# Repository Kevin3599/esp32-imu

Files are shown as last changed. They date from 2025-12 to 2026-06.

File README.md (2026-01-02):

# ESP32 双I²C总线 IMU+OLED 项目

本项目演示如何在ESP32-WROOM-32上使用两个独立的I²C控制器，分别连接MPU6050 IMU传感器和SSD1306 OLED显示屏。

## 🔌 硬件连接

### ESP32引脚分配
```
MPU6050 (I²C总线0)：
├── VCC  → 3.3V
├── GND  → GND  
├── SDA  → GPIO21
└── SCL  → GPIO19

OLED显示屏 (I²C总线1)：
├── VCC  → 3.3V
├── GND  → GND
├── SDA  → GPIO25  
└── SCL  → GPIO26
```

### 接线图说明
```
ESP32-WROOM-32
     ┌─────────────┐
     │             │
     │  GPIO19 ────┼──── SCL (MPU6050)
     │  GPIO21 ────┼──── SDA (MPU6050)  
     │             │
     │  GPIO26 ────┼──── SCL (OLED)
     │  GPIO25 ────┼──── SDA (OLED)
     │             │
     │   3.3V ─────┼──── VCC (两个设备)
     │   GND ─────┼──── GND (两个设备)
     └─────────────┘
```

## 📋 物料清单

| 组件 | 型号/规格 | 数量 | 备注 |
|---|---|---|---|
| 微控制器 | ESP32-WROOM-32 | 1 | 主控制器 |
| IMU传感器 | MPU6050 | 1 | 6轴惯性传感器 |
| 显示屏 | SSD1306 OLED 128×64 | 1 | I²C接口 |
| 电阻 | 4.7KΩ | 4 | I²C上拉电阻（可选） |
| 跳线 | 杜邦线 | 若干 | 连接线 |

## 🛠️ 软件环境

### 开发环境
- **IDE**: Visual Studio Code + PlatformIO
- **框架**: Arduino Framework
- **平台**: Espressif 32

### 库依赖
```ini
lib_deps = 
    adafruit/Adafruit SSD1306@^2.5.7
    adafruit/Adafruit GFX Library@^1.11.8
    electroniccats/MPU6050@^1.0.2
    wire
```

## 📈 扩展建议

### 1. 姿态解算
```cpp
// 添加四元数或欧拉角计算
float pitch = atan2(-accelX, sqrt(accelY*accelY + accelZ*accelZ)) * 180/PI;
float roll = atan2(accelY, accelZ) * 180/PI;
```

### 2. 数据滤波
```cpp
// 添加低通滤波或卡尔曼滤波
class LowPassFilter {
private:
    float alpha;
    float filteredValue;
public:
    LowPassFilter(float cutoff) : alpha(cutoff), filteredValue(0) {}
    float update(float input) {
        filteredValue = alpha * input + (1 - alpha) * filteredValue;
        return filteredValue;
    }
};
```

## 📄 许可证

本项目采用 MIT 许可证 - 详见 [LICENSE](LICENSE) 文件

## 🤝 贡献

欢迎提交 Pull Request 和 Issue！

## 📧 联系方式

如有问题，请提交 GitHub Issue 或发送邮件。

---

**项目状态**: ✅ 稳定版本  
**最后更新**: 2024-12-23  
**兼容性**: ESP32-WROOM-32, Arduino Framework

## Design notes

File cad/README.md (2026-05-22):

# PCB1 Enclosure Model

This folder contains a parametric `OpenSCAD` enclosure for the PCB described by
`Gerber_PCB1_2026-02-03.zip`.

## Source dimensions

- Board outline: `78.867 mm x 70.866 mm`
- Corner radius: `5.08 mm`
- Source file: `Gerber_BoardOutlineLayer.GKO`

## Files

- `pcb1_enclosure.scad`: two-piece printable enclosure with a base, lid, board
  support ring, inferred component keepouts, simple edge retainers, and
  external screw-ear shell fastening.

## Design assumptions

- The PCB does not expose dedicated mounting holes, so the base uses perimeter
  support plus four retainers instead of screw posts.
- Top-side component clearance defaults to `18 mm`.
- Bottom-side component clearance defaults to `3 mm`.
- Edge cutouts default to a best-effort layout inferred from the Gerber probe
  data and should be tuned after checking the exact connector and cable
  locations on the assembled board.
- The lid now includes local relief pockets above the main component regions so
  you can keep the overall shell height reasonable while still clearing modules.
- The upper and lower shells are fastened with four external screw ears so the
  enclosure can still lock together even though the PCB itself has no mounting
  holes.

## Quick use

1. Open `pcb1_enclosure.scad` in OpenSCAD.
2. Change `show_mode` to `base`, `lid`, or `exploded` while tuning.
3. Toggle `show_components` if you want to inspect the inferred keepout boxes.
4. Adjust the clearance and cutout parameters near the top of the file.
5. Edit the cutout arrays as `[center, width, height]` in millimeters.
6. Export each half as STL once the fit looks right.

## Parameters you will likely tune first

- `fit_gap`
- `board_edge_gap`
- `underside_clearance`
- `topside_clearance`
- `north_cutouts`
- `south_cutouts`
- `east_cutouts`
- `west_cutouts`
- `component_clearance_gap`
- `use_fastening_ears`
- `screw_clearance_diameter`
- `screw_pilot_diameter`
- `screw_head_diameter`

## Notes

- The lid is modeled as an outer cap that overlaps the base walls. If your
  printer runs tight, increase `lid_clearance` by `0.1 mm` to `0.2 mm`.
- `show_components = true` displays approximate top-side module volumes inferred
  from silkscreen and flying-probe data. Treat them as starting geometry, not a
  final metrology source.
- `use_pressure_pads` is disabled by default to avoid colliding with tall
  modules until the exact assembled height is measured.
- The default fastening geometry is sized for roughly M3 hardware or similar
  self-tapping screws. Tweak the screw diameters if you plan to use inserts or
  machine screws instead.
- The support ring can be widened if the PCB has heavy modules near its center.

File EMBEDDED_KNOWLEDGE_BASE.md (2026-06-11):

# Embedded Knowledge Base

> 面向未来自己的工程复盘。本文以当前工作区源码为事实基线；旧 README、优化报告和面试笔记只作为设计背景，不覆盖代码事实。
>
> 最后核查：2026-06-10

## 目录

1. [第一部分：项目全景图](#第一部分项目全景图)
2. [第二部分：系统架构设计](#第二部分系统架构设计)
3. [第三部分：项目运行流程](#第三部分项目运行流程)
4. [第四部分：核心模块解析](#第四部分核心模块解析)
5. [第五部分：技术知识提取](#第五部分技术知识提取)
6. [第六部分：设计决策分析](#第六部分设计决策分析)
7. [第七部分：调试与踩坑记录](#第七部分调试与踩坑记录)
8. [第八部分：工程实践总结](#第八部分工程实践总结)
9. [第九部分：项目复盘](#第九部分项目复盘)
10. [第十部分：个人知识地图](#第十部分个人知识地图)

---

## 阅读前先知道的事实

这个仓库只有一个主固件项目，但它经历了明显演化：

1. 最初是 ESP32 + MPU6050 + OLED 的双 I2C 演示。
2. 后来加入 GT-U7 GPS，目标变成低成本 Dragy 风格车辆性能仪。
3. 再加入摩托车倾角/G 力分析、Wi-Fi 网页、音频录制、SD 卡日志、PCB 和 3D 打印外壳。

因此旧文档与当前代码有冲突。以后判断“现在是什么”，优先级应为：

```text
当前源码与 platformio.ini
        >
当前硬件接线和实测记录
        >
README / GPS 优化报告 / 面试笔记
```

当前已发现的版本漂移：

| 主题 | 当前源码 | 旧文档中的其他说法 |
|---|---|---|
| I2C | MPU: GPIO21/22；OLED: GPIO18/19，两条总线 | README 曾写 21/19 与 25/26；GPS_WIRING 曾写共享 21/22 |
| GPS 串口 | UART2，GPIO16/17，9600 bps | 优化报告写过 38400 bps |
| GPS 更新率 | 启动配置 10 Hz；掉线恢复时改为 5 Hz | 文档同时出现 5 Hz、10 Hz |
| SD 卡 | 模块完整，但 `setup()` 初始化被注释 | 部分描述把它写成可直接使用 |
| GPS-IMU 融合 | `loop()` 每 5 ms 调用 `fuseIMUSpeed()` | `/data` 的 `imuSpeed` 仍固定输出 0，注释称暂未实现 |
| 摩托互补滤波 | 已在 `performance_analyzer.cpp` 实现 | 面试笔记部分段落称姿态互补滤波未实现 |

编码方面，大量中文文件显示为 mojibake，说明文件很可能曾以 UTF-8 保存、后被错误编码链处理。代码符号仍可读，但这是长期维护风险。

---

# 第一部分：项目全景图

# ESP32 Draggy Racing Logger

## 项目背景

项目想用低成本器件做一个车载/摩托车数据终端：实时读取车辆运动状态，显示速度、姿态、G 力和性能测试结果，并让手机不安装 App 也能查看数据。

真正困难的不是“读出传感器”，而是车辆环境：

- 发动机和路面引入高频振动。
- MPU6050 有零偏、温漂和安装坐标误差。
- GT-U7 在静止和弱信号时会速度漂移。
- GPS 只有低频绝对速度，IMU 有高频响应但积分漂移。
- Web、OLED、采样、录音和存储都跑在同一个 Arduino 主循环中。

## 项目目标

当前代码试图实现：

- 200 Hz IMU 采样与滤波。
- 10 Hz GPS 解析、静止抑制和性能计时。
- GPS-IMU 速度与 G 力的轻量融合。
- 摩托车倾角、弯道、翘头/翘尾和峰值统计。
- OLED 本地显示。
- ESP32 SoftAP + HTTP Web 仪表盘。
- SPIFFS 低码率 WAV 录音。
- SD 卡 10 Hz CSV 行驶日志。
- 与 PCB 配套的参数化 OpenSCAD 外壳。

必须区分：SD 记录代码存在，但当前启动流程没有初始化 SD 卡，所以默认不会真正记录。

## 技术栈

| 类别 | 使用内容 |
|---|---|
| MCU | ESP32-WROOM-32 / PlatformIO `esp32dev` |
| 框架 | Arduino Framework |
| 语言 | C++、HTML/CSS/JavaScript、OpenSCAD |
| 传感器 | MPU6050、GT-U7 GPS、模拟麦克风 |
| 显示 | SSD1306 128x64 OLED |
| 总线 | 双 I2C、UART2、HSPI、ADC1 |
| 网络 | Wi-Fi SoftAP、HTTP `WebServer` |
| 存储 | SPIFFS、SD/FAT CSV |
| 数据格式 | NMEA、JSON、CSV、PCM WAV |
| 构建 | PlatformIO |
| 机械 | Gerber、OpenSCAD、STL |

## 项目一句话总结

基于 ESP32 构建低成本车载多传感器性能记录仪，融合 200 Hz IMU 与 10 Hz GPS，实现姿态/G 力分析、性能计时、Web 实时可视化、录音与可扩展数据记录。

## 项目目录结构分析

```text
esp32-imu/
├── src/                         固件主源码
│   ├── main.cpp                 系统装配、调度、OLED、HTTP API
│   ├── mpu6050.*                IMU 驱动、滤波、基础姿态
│   ├── gps_module.*             GPS、性能测试、速度融合、会话持久化
│   ├── performance_analyzer.*   G 力融合、车辆行为、摩托车分析
│   ├── audio_recorder.*         ADC 定时采样、WAV、自动录音
│   └── sd_logger.*              SD 初始化与 CSV 日志
├── data/index.html              SPIFFS Web 仪表盘
├── cad/                         PCB 外壳源码与 STL
├── platformio.ini               板卡、串口、依赖、SPIFFS 配置
├── README.md                    早期项目说明，已落后于源码
├── BUILD_GUIDE.md               PlatformIO 构建与排错说明
├── GPS_*.md                     GPS 接线、升级与优化思路
├── GT-U7_*.md                   GT-U7 优化总结，部分内容未与代码同步
├── INTERVIEW_NOTES.md           技术复盘素材，不是运行事实来源
├── Gerber_*.zip                 PCB 制造文件
├── wiring_diagram.txt           接线说明，接近当前双 I2C 方案
├── include/ lib/ test/          PlatformIO 模板目录，暂无自有实现/测试
└── interview/                   LaTeX/PDF 派生文档，不属于固件运行链
```

PCB 和外壳是同一产品化尝试的一部分，不应误识别为独立软件项目。Gerber 表明存在双层 PCB、丝印、阻焊、钻孔和飞针测试数据；无法仅从当前工作区确定实际焊接版本和最终 BOM。

---

# 第二部分：系统架构设计

# 系统架构

## 总体架构

```text
                   +---------------- ESP32 ----------------+
MPU6050 -- I2C0 -->| 采样/均值/IIR --> 姿态与G力 --------+ |
                   |                                      | |
GT-U7 ---- UART2 ->| NMEA解析/质量判断/速度滤波 --------+ | |
                   |                                    | | |
Mic ------ ADC1 -->| Timer ISR --> WAV缓冲 --> SPIFFS   | | |
                   |                                    v v |
SD Card --- HSPI <-| CSV Logger <--- 融合/性能/摩托分析器  |
                   |                    |                 |
OLED ----- I2C1 <--| 本地显示 <---------+                 |
                   |                    v                 |
Phone <-- Wi-Fi ---| WebServer --> JSON API --> index.html|
                   +--------------------------------------+
```

## 为什么这样拆分

- `main.cpp` 是 composition root：拥有硬件实例、启动顺序和时间调度。
- 驱动/算法按数据源拆分：IMU、GPS、音频、SD 各自维护状态。
- `performance_analyzer` 位于传感器之上，读取全局 IMU/GPS 数据形成派生指标。
- OLED 和 HTTP 是两个输出适配器，共享同一批全局状态。

这套拆法适合原型开发，新增功能快；代价是模块通过 `extern` 全局结构体耦合，调用顺序就是隐含的数据一致性协议。

## 数据链路

### 运动数据链

```text
MPU6050 raw acceleration/gyro
        |
        v
10点移动平均 + 一阶IIR
        |
        +--> Roll/Pitch
        +--> G力/驾驶状态
        +--> 摩托倾角互补滤波
        +--> IMU速度积分
                         \
GT-U7 NMEA --> GPS速度 ---> 轻量互补修正 --> 性能指标/Web/OLED/CSV
```

GPS 提供长期不漂移的绝对速度；IMU 提供短期快速变化。当前实现不是严格卡尔曼滤波，而是偏置校准、死区、积分和 GPS 比例拉回。

### 展示链

```text
全局状态结构体
   +--> OLED: 20 Hz，五种页面
   +--> /data: Web主仪表盘
   +--> /moto: 摩托数据
   +--> /audio: 录音状态
   +--> Serial: 5 Hz简报 / 2 s详细信息
```

### 存储链

```text
Mic ADC --> 8-bit/8 kHz PCM --> 512 B buffer --> SPIFFS WAV
GPS+IMU+Fusion --> RideDataPoint --> CSV line --> SD card
Browser samples --> JavaScript memory --> client-side CSV/JSON export
```

这里实际上有三套“记录”：SPIFFS 音频、SD 原始/融合数据、浏览器内存记录。它们没有统一会话 ID 和时间基准。

---

# 第三部分：项目运行流程

# 上电初始化

```text
Reset
  |
  v
Serial 115200 + BOOT输入
  |
  v
双I2C 400 kHz初始化 -> 扫描设备
  |
  v
MPU6050 -> GPS -> 性能分析 -> 摩托模式 -> 音频
  |
  v
SD初始化跳过（当前测试模式）
  |
  v
OLED -> SPIFFS -> Wi-Fi SoftAP -> HTTP路由
  |
  v
显示连接信息，进入 loop()
```

值得注意：`initAudioRecorder()` 在 `SPIFFS.begin(true)` 之前读取 SPIFFS 容量。首次启动或文件系统异常时，这个顺序不稳妥，应该先挂载文件系统。

# 主循环调度

项目没有 FreeRTOS 显式任务，也没有统一 scheduler，而是 `millis()` 驱动的协作式时间片：

```text
loop()
  |
  +--> server.handleClient()
  +--> BOOT按键与串口命令
  |
  +--> 每5 ms:
  |      ReadMPU6050()
  |      fuseIMUSpeed()
  |
  +--> 每100 ms:
  |      updateGPSData()
  |      checkAutoLogging()
  |      optional logDataPoint()
  |
  +--> 每次循环:
  |      updateAudioRecorder()
  |
  +--> 每50 ms:
         updateFusedData()
         update OLED
         print serial
```

优点是易读、没有任务同步成本。问题是任何阻塞操作都会破坏所有“频率承诺”。HTTP 文件传输、GPS 重连 `delay()`、OLED I2C、SD flush 和串口输出都可能让 5 ms/125 us 级任务失约。

# 中断流程

唯一明确的用户中断路径是音频定时器：

```text
125 us timer
   |
   v
ISR: adc1_get_raw()
   |
   +--> lastSample = sample
   +--> sampleReady = true
             |
             v
主循环 processSample()
   |
   +--> 12 bit转8 bit
   +--> 更新音量
   +--> 写入512 B缓冲
   +--> 缓冲满后写SPIFFS
```

这不是可靠的生产者-消费者队列。若主循环在两个中断之间没有消费，`lastSample` 被覆盖，只保留最新样本。

# 通信流程

## GPS

```text
UART2 bytes
  -> TinyGPS++ encode
  -> location/speed/time/satellite/HDOP
  -> 合理范围与跳变检查
  -> 速度20点窗口、方差、自适应滤波、死区
  -> GPS_DATA
```

超过 3 秒无可解析数据会标记丢失；每 10 秒发送热启动和恢复配置。恢复配置将更新周期设置为 5 Hz，与启动时 10 Hz 不一致。

## Web

ESP32 创建 `ESP32-IMU` 热点，密码硬编码为 `12345678`，地址通常为 `192.168.4.1`。

| 路由 | 作用 |
|---|---|
| `/` | 从 SPIFFS 流式返回 `index.html` |
| `/data` | 通用速度、GPS、G 力、性能 JSON |
| `/moto` | 摩托倾角、事件和峰值 JSON |
| `/audio` | 录音状态 JSON |
| `/audio/control?action=...` | 开始、停止、暂停、恢复、删除、自动模式、列表 |
| `/audio/download?file=...` | 下载 WAV |

网页每 150 ms 请求 `/data`，每 100 ms 请求 `/moto`。这是轮询架构，简单但请求频繁，且 `/moto` 请求本身会再次调用 `updateMotorcycleData()`，使算法更新时间受浏览器请求节奏影响。

# 状态机

## 音频录制

```text
IDLE/STOPPED -- speed >= 5 --> ACTIVE
ACTIVE -- speed < 2 for 5s --> STOPPED
ACTIVE -- pause ------------> PAUSED
PAUSED -- resume -----------> ACTIVE
ACTIVE -- 300s -------------> STOPPED
```

`RECORDING_WAITING` 被定义但当前逻辑基本未使用。

## 性能测试

- 加速：速度超过 5 km/h 自动开始，穿越 60/100/200 km/h 时记录时间。
- 制动：速度达到约 95 km/h 后进入条件，降到 5 km/h 结束。
- 圈速字段和函数声明存在，但完整实现无法从当前工作区确定。

---

# 第四部分：核心模块解析

# `main.cpp`：系统装配与输出层

职责：

- 创建两条 `TwoWire` 总线、OLED、WebServer。
- 固定初始化顺序和主循环频率。
- 把全局数据编码为 OLED 页面和 JSON。
- 管理 BOOT 按键及串口模式。

关键设计是多速率协作循环。最大问题是文件已超过千行，HTTP、OLED、调度和业务拼在一起，修改一个输出字段容易影响实时路径。

# `mpu6050`：高振动车辆 IMU 前端

核心结构 `MPU6050_DATA` 同时保存原始和滤波后的加速度、角速度、Roll/Pitch。

处理链：

```text
Adafruit getEvent()
 -> 10样本滑动平均
 -> alpha=0.1 一阶IIR
 -> 加速度倾角
```

量程为 ±8 g、±500 deg/s，DLPF 为 94 Hz。选择 94 Hz 是为了保留快速车辆动作，再依赖软件滤波压制振动。

注意：

- `CalculateAttitude()` 的基础 Roll/Pitch 仅使用加速度计。
- `Yaw` 固定为 0。
- 陀螺数据在 Adafruit API 中是 rad/s，但摩托互补滤波直接按 deg/s 积分的迹象很强；若未转换，倾角动态项会缩小约 57.3 倍。需要实机与库单位确认后修正。
- 初始滤波状态为 0，会有启动爬升过程。

# `gps_module`：GPS、速度与性能计时

核心结构：

- `GPS_DATA`：位置、时间、速度、信号质量、融合状态。
- `PERFORMANCE_DATA`：加速、制动、圈速和会话数据。

主要策略：

- 仅输出 RMC/GGA，降低 9600 bps 下 NMEA 堵塞风险。
- 开启 SBAS/WAAS。
- 对位置做经纬度范围和 1 km 单帧跳变检查。
- 对速度做 20 点窗口、标准差、卫星/HDOP 动态阈值、分段 IIR 和最终死区。
- 静止时收集 200 个样本估计 IMU 前向偏置。
- IMU 积分速度每次 GPS 新帧向 GPS 拉回 10%。

设计意图正确，但实现中 `gps_data.speed_ms` 很少被明确同步为当前 GPS 速度，而校准与静止归零依赖它；应统一只使用 `speed_mps` 或明确维护该字段。

# `performance_analyzer`：派生指标与摩托语义

`FUSED_PERFORMANCE_DATA` 保存当前速度/G 力、峰值、行为状态和质量分数。

主要功能：

- 组合 IMU 加速度与 GPS 速度差分。
- 检测加速、制动、转弯。
- 用车辆质量、滚阻、风阻估算瞬时功率。
- 用互补滤波估计摩托倾角和俯仰。
- 检测弯道、翘头、翘尾，估算弯道半径。

这里把“信号处理”和“车辆业务语义”放在同一模块，原型阶段方便，但未来应拆成：

```text
Sensor Fusion
Vehicle Frame Transform
Event Detector
Session Statistics
```

硬编码偏置 `-0.47/+0.5/-0.48` 和假定坐标 `X=垂直、Y=侧向、Z=前向` 是整个分析可信度的基础。换安装方向或换板后必须重新标定。

# `audio_recorder`：低码率事件录音

配置为单声道、8 kHz、8 bit PCM，每秒约 8 KB，5 分钟约 2.4 MB，不含文件系统开销。

WAV 头在开始时写占位值，停止时回写文件大小。这种方式简单，但异常断电会留下头部未完成的文件。

最大架构问题是 ISR 只有一个样本槽，不是 DMA/环形缓冲。录音数据完整性无法保证。

# `sd_logger`：行驶 CSV

SD 使用 HSPI：

```text
MISO GPIO25
MOSI GPIO13
SCK  GPIO14
CS   GPIO15
```

选择 GPIO25 替代 GPIO12，是为了规避 ESP32 启动绑带引脚风险。日志以 10 Hz 写 CSV，每 100 点 flush 一次，在数据安全和写入开销之间折中。

当前 `setup()` 没有调用 `initSDCard()`，因此 `checkAutoLogging()` 会因 `initialized=false` 直接返回。

# `data/index.html`：无 App Web 仪表盘

单文件前端包含：

- 实时速度/G 力曲线。
- 性能、GPS、摩托状态。
- 浏览器端会话记录与 CSV/JSON 导出。
- 录音控制逻辑。

优点是部署简单。缺点是 HTML 已很大、编码损坏明显、无构建/校验、API 字段靠手写约定。浏览器记录只存在内存，刷新即丢失。

# `cad/pcb1_enclosure.scad`：参数化产品外壳

外壳从 Gerber 轮廓推导出 78.867 x 70.866 mm、圆角 5.08 mm 的 PCB：

- 底壳用周边支撑环和卡扣固定无安装孔 PCB。
- 上盖使用局部器件避让腔。
- 四角外置螺钉耳避免占用板内空间。
- 提供通风槽、边缘开口、装配/爆炸/导出模式。

器件高度和接口位置是从丝印/飞针数据推断的，不是装配实测。打印前必须实测校核。

---

# 第五部分：技术知识提取

# 双 I2C

## 为什么需要它

MPU6050 与 OLED 本可共享地址不同的总线，但 OLED 整帧刷新会占用 I2C 时间。分成两条控制器可以隔离显示流量与传感器采样，也方便独立排错。

## 项目中的实际应用

- I2C0：GPIO21/22，MPU6050。
- I2C1：GPIO18/19，SSD1306。
- 两者均配置 400 kHz。

## 常见 Bug 与调试

- 文档接线漂移是当前首要风险。
- 地址应扫描确认：MPU 0x68/0x69，OLED 0x3C/0x3D。
- 线长、上拉、电源噪声会导致间歇 NACK。
- 用现有 `scanI2CDevices()` 先区分接线问题与驱动问题。

替代方案是共享一条 I2C，节省引脚；对本项目而言隔离总线更适合实时采样。

# UART 与 NMEA

GT-U7 通过 UART2 输入 NMEA。项目只保留 RMC 与 GGA，因为 10 Hz、9600 bps 时全量语句容易占满串口带宽。

常见坑：

- 模块不一定兼容所有 PMTK 命令。
- 发送 10 Hz 配置不代表模块确实进入 10 Hz。
- 掉线恢复又设置 5 Hz，导致运行状态不一致。
- 应统计每秒完整 RMC/GGA 帧数，而不是只相信配置命令。

# 采样与数字滤波

项目使用了三类低成本滤波：

- 硬件 DLPF：在传感器内部先限制带宽。
- 滑动平均：压制随机噪声，但引入窗口延迟。
- 一阶 IIR：O(1) 状态，适合 MCU，但有相位延迟。

常见误区是把“200 Hz 调用周期”当成严格采样率。当前系统是协作循环，实际采样间隔会抖动，且代码给融合器的 `dt` 固定为 5 ms，没有用真实时间差。

调试时应同时记录：

- 实际 `micros()` 间隔分布。
- 原始值、滑动平均值、IIR 值。
- 静止 RMS、阶跃响应和相位延迟。

# GPS 静止漂移

GPS 低速时噪声可能大于真实速度。项目不是简单小于阈值清零，而是综合窗口方差、连续稳定次数、卫星数和 HDOP。

这能改善显示，但阈值滤波也会吃掉真实低速起步，使 0-100 起点变晚。性能计时最好保留原始 Doppler 速度和滤波速度两路，分别服务计时与 UI。

# GPS-IMU 融合

当前思路：

```text
IMU: 高频预测，但漂移
GPS: 低频校正，但延迟和低速噪声
```

项目采用简化互补校正而非 EKF，优点是参数直观、计算低。缺点是没有显式状态协方差、时间戳对齐、姿态重力补偿和传感器延迟模型。

真正升级时，优先实现一维状态 `[速度, 加速度偏置]` 的 Kalman filter，而不是直接上完整 9/15 状态导航 EKF。

# ADC、Timer 与音频

定时器中断可以建立稳定采样节拍，但 ISR 应只搬运数据，不能依赖单槽共享变量承载连续流。

更合适的方案：

- ESP32 I2S ADC/DMA。
- ISR 写入 lock-free ring buffer。
- 双缓冲，由任务批量写文件。

此外 8-bit unsigned PCM 的直流中心假设是 128；模拟麦克风偏置和 ADC 非线性应实测。

# SPI、SD 与文件系统

SD 写入延迟具有长尾，`flush()` 可能阻塞几十毫秒。若和 200 Hz 采样同循环，必须缓冲解耦。

SPIFFS 适合少量静态资源和小文件，不适合高频持续音频写入。LittleFS 或 SD 更适合长期录音；异常断电还需要临时文件和恢复策略。

# Wi-Fi 与 HTTP

SoftAP 让手机直接连接，现场无需路由器，这是很实用的产品决策。

当前轮询方案的常见问题：

- 多客户端会放大 CPU 和 JSON 序列化开销。
- 同步 `WebServer` 的流式下载可能阻塞采样。
- `sprintf` 固定缓冲区依赖字段长度，需用 `snprintf`。
- 密码硬编码，适合原型但不适合发布。

替代方案：Server-Sent Events 或 WebSocket 推送，并将静态资源缓存与实时数据通道分离。

---

# 第六部分：设计决策分析

# 双 I2C 而不是共享总线

背景：显示更新与高频 IMU 读取争用总线。

优点：故障隔离、时序可控、扫描清晰。缺点：多占两根 GPIO，接线复杂。当前 ESP32 引脚尚可，选择合理。

# 协作式调度而不是 FreeRTOS 任务

背景：Arduino 原型需要快速迭代。

优点：控制流直观、调试容易。缺点：所有模块共享阻塞预算，无法保证 200 Hz IMU 和 8 kHz 音频。

当前方案适合功能验证；当音频、SD 和网络同时开启时，应迁移为任务和队列：

```text
Core/Task Sensor -> Queue -> Fusion
Core/Task IO     -> SD/SPIFFS/Web
```

# 多级滤波而不是单一滤波器

车辆振动覆盖宽频段，单一强低通会造成明显延迟。硬件 DLPF、移动平均和 IIR 分层容易调参，但当前级联实际带宽没有通过测试数据验证。

替代方案包括双二阶 Butterworth、陷波器、Savitzky-Golay 或频域分析后定制滤波。应先采集原始数据做 PSD，再决定，而不是继续堆滤波。

# 互补滤波而不是 EKF

当前传感器精度有限，且原型更需要可解释性。互补滤波成本低、故障容易定位。

缺点是重力投影、安装误差和时间同步需要手工处理。等硬件、坐标系和时间戳稳定后，再引入一维 KF 或姿态 EKF。

# 阈值状态机

自动录音、SD 日志、加速/制动、弯道检测都采用阈值 + 延时/滞回。

优点是行为可解释；缺点是阈值分散在多个文件，且录音与 SD 的起停参数不一致：

- 录音停止延时 5 秒。
- SD 停止延时 30 秒。

应集中成 `VehicleSessionConfig`，并用一次会话状态驱动所有记录器。

# 浏览器端导出

浏览器记录减轻 ESP32 存储压力，开发方便。但手机锁屏、刷新、断连都会丢数据，不能替代设备端可靠日志。它更适合作为“即时观察与临时导出”。

---

# 第七部分：调试与踩坑记录

# 调试记录 1：文档与固件接线冲突

问题：按旧 README 接线可能找不到设备。

原因：项目从共享 I2C 演进到双 I2C，文档未统一。

定位：以 `main.cpp` 宏和启动扫描输出为准。

解决：维护唯一 `HARDWARE_PINOUT.md`，其他文档只链接，不复制引脚表。

经验：硬件配置必须单一事实源。

# 调试记录 2：音频丢采样

问题：WAV 时长、音质或样本数异常。

原因：8 kHz ISR 覆盖单个 `lastSample`；主循环无法保证每 125 us 消费。

定位：比较墙钟时长与 `samples_recorded / 8000`，统计覆盖次数。

解决：I2S DMA 或环形缓冲，文件写入放到独立任务。

# 调试记录 3：SD 功能看似存在但不工作

问题：速度超过阈值仍不生成 CSV。

原因：`initSDCard()` 在 `setup()` 被注释，`sd_status.initialized` 始终为 false。

定位：查看启动日志是否打印 SD 容量。

解决：恢复初始化前先解决原注释所说的 I2C/引脚冲突，并增加 Web/串口 SD 状态。

# 调试记录 4：倾角动态响应可能错误

问题：陀螺贡献过弱，倾角主要跟随加速度计。

原因：Adafruit 陀螺输出通常为 rad/s，而摩托代码按 deg/s 注释直接积分。

定位：固定角速度转动，比较原始 gyro、积分角与实际角度。

解决：在驱动边界统一单位，字段命名加入 `_rad_s` 或 `_deg_s`。

# 调试记录 5：GPS 模式不一致

问题：掉线恢复后刷新率下降，性能测试响应变化。

原因：启动发送 100 ms 更新命令，恢复发送 200 ms 更新命令。

解决：抽取 `configureGPS()`，启动和恢复调用同一配置；读取实际帧率确认结果。

# 调试记录 6：启动顺序与 SPIFFS

问题：音频模块初始化时容量可能为 0 或状态不可靠。

原因：音频初始化早于 `SPIFFS.begin(true)`。

解决：先初始化存储，再初始化依赖存储的音频和 Web。

# 调试记录 7：融合字段与 API 不一致

问题：内部已经运行速度融合，但网页 `imuSpeed` 永远为 0，`speed` 仍来自 GPS。

原因：算法、状态结构和 JSON 输出没有同时更新。

解决：定义明确字段：`gps_speed`、`imu_predicted_speed`、`fused_speed`，并建立 API schema 测试。

# 调试记录 8：HTTP 文件下载路径

问题：下载接口可能访问任意 SPIFFS 已知路径，而不仅是录音。

原因：只补 `/` 和检查文件存在，没有限定 `/ride_*.wav`。

解决：白名单文件名格式，拒绝 `..`、非 WAV 和非录音前缀。

# 调试记录 9：字符串与缓冲区

问题：JSON/文本字段增长后可能溢出固定缓冲区。

原因：使用 `sprintf` 而非长度受限接口。

解决：改为 `snprintf` 并检查返回值；长期使用 ArduinoJson 流式序列化。

# 调试记录 10：编码损坏

问题：中文日志、网页标签和文档显示乱码，甚至可能破坏 HTML 标签或 C++ 字符串。

原因：文件编码链不一致。

解决：全仓统一 UTF-8，无 BOM；添加 `.editorconfig`，在 CI 中做 UTF-8 解码和 HTML/C++ 基础检查。

---

# 第八部分：工程实践总结

## 做得好的地方

- 模块按传感器和业务域拆分，原型意图清楚。
- 使用 `millis()` 而不是在主路径大量固定延时。
- 对 GPS 弱信号、静止漂移和跳点有工程化防护。
- 同时保留原始值、滤波值和峰值，便于调试。
- 通过 SoftAP + 单页 Web 降低现场使用门槛。
- SD 选择 HSPI 和非 GPIO12 MISO，体现了对 ESP32 启动绑带的考虑。
- OpenSCAD 参数化外壳把软件项目向可装配设备推进了一步。

## 可以改进的地方

### 代码组织

`main.cpp` 应拆成：

```text
app_scheduler
web_api
oled_view
hardware_config
```

全局 `extern` 状态应逐步替换为只读快照或消息结构，至少明确谁写、谁读、更新频率和单位。

### 配置管理

引脚、采样率、阈值、车辆参数和 Wi-Fi 凭据分散在各文件。建议集中：

```text
board_config.h
sensor_config.h
vehicle_config.h
```

并把所有物理量写入单位后缀。

### 日志

串口日志丰富，但缺乏级别和节流统一。应使用 `LOGE/W/I/D`，避免高频 `Serial.printf` 破坏实时性。

### 错误处理

很多初始化失败后继续运行，这是原型的容错思路，但后续函数仍可能假定硬件有效。应维护模块健康状态，并在 UI 显示 degraded mode。

### 测试策略

当前 `test/` 只有模板说明，没有项目测试。最值得先补的是纯算法主机测试：

- Haversine 距离。
- GPS 窗口与静止判定。
- 阈值穿越计时。
- WAV 头尺寸。
- CSV 格式。
- 互补滤波单位与步进响应。
- 状态机起停滞回。

硬件在环测试应回放已保存的 NMEA 与 IMU 数据，而不是每次都上车测试。

### 构建与 CI

当前配置锁定库版本是好事。建议 CI 至少执行：

```text
pio run
pio test -e native
HTML/JSON schema sanity check
UTF-8 validation
```

本次分析环境无法执行构建，因为终端没有可用的 `pio` 命令；因此当前源码是否能完整编译无法从本次静态分析确定。

---

# 第九部分：项目复盘

## 最大的亮点

不是简单堆传感器，而是围绕“低成本硬件在真实车辆环境中不可靠”做了多层处理：信号质量、静止抑制、漂移校准、融合、状态机和多终端显示。

## 最大的难点

多时间尺度和多误差源同时存在：

- 音频 8 kHz。
- IMU 200 Hz。
- 显示/融合 20 Hz。
- GPS/日志 10 Hz。
- Web 约 6.7/10 Hz。

而它们目前共享一个可能阻塞的主循环。真正的系统瓶颈是调度与数据一致性，不再只是算法。

## 学到的知识

- 传感器数据“能读”与“能用于决策”之间隔着校准、坐标系、滤波、质量评估和时间同步。
- 低成本 GPS 的极限不能只靠软件宣传突破，升级硬件有时比继续堆阈值更合理。
- 原型文档很容易落后于代码，尤其是引脚和单位。
- 记录系统必须考虑掉电、断连和阻塞长尾。
- 机械结构、接线和软件配置应被视为同一系统架构。

## 如果重新设计

1. 先定义统一硬件配置、坐标系和单位。
2. 使用 I2S DMA 采音，传感器和存储通过队列解耦。
3. 建立单一 `VehicleSession` 状态机，统一音频、CSV 和峰值会话。
4. 所有数据携带 `micros()` 时间戳，融合使用真实 `dt`。
5. 保留 raw/filtered/fused 三层数据并定义稳定 API schema。
6. 先做数据回放工具和 native 单元测试，再调算法。
7. 用实测频谱和标定数据选择滤波器。
8. 把网页通信改成 SSE/WebSocket。

## 下一步扩展

优先级建议：

1. 修复编码、引脚文档和单位问题。
2. 恢复可验证的 SD 日志，获得真实数据集。
3. 修复音频采样架构。
4. 增加时间戳和离线回放测试。
5. 一维速度/偏置 Kalman filter。
6. 升级 NEO-M9N 或更高频 GNSS；是否上 RTK 取决于实际计时精度目标。
7. 增加 OTA、配置页面和会话下载。

无法从当前工作区确定：现有 PCB 是否已经覆盖麦克风与 SD 模块、外壳是否完成实物试装、车辆参数是否经过标定、GPS 优化报告中的量化提升是否来自可复现实测。

---

# 第十部分：个人知识地图

# Embedded Knowledge Map

```text
嵌入式系统
├── ESP32
│   ├── Arduino Framework
│   ├── GPIO与启动绑带
│   ├── 双I2C控制器
│   ├── UART2
│   ├── HSPI
│   ├── ADC1与硬件Timer
│   ├── SPIFFS
│   └── Wi-Fi SoftAP / HTTP
│
├── 传感器与信号处理
│   ├── MPU6050量程与DLPF
│   ├── 滑动平均
│   ├── 一阶IIR
│   ├── 互补滤波
│   ├── 零偏与安装校准
│   ├── 坐标系映射
│   ├── 重力补偿
│   └── 采样率、抖动与真实dt
│
├── GNSS
│   ├── NMEA RMC/GGA
│   ├── Doppler速度
│   ├── 卫星数与HDOP
│   ├── 静止漂移抑制
│   ├── 跳点过滤
│   ├── SBAS
│   ├── 多频率数据融合
│   └── GT-U7到高性能GNSS升级
│
├── 车辆与机器人数据
│   ├── 纵向/横向/垂直G
│   ├── 加速与制动计时
│   ├── 倾角与俯仰
│   ├── 弯道检测与半径估计
│   ├── 翘头/翘尾事件
│   ├── 峰值与会话统计
│   └── 简化功率估算
│
├── 数据记录
│   ├── WAV/PCM
│   ├── CSV
│   ├── JSON API
│   ├── 环形缓冲与DMA
│   ├── SD写入长尾
│   ├── 掉电一致性
│   └── 浏览器端临时记录
│
├── 软件架构
│   ├── 协作式调度
│   ├── 多速率任务
│   ├── 状态机与滞回
│   ├── 全局状态耦合
│   ├── 消息队列/生产者消费者
│   ├── 模块健康状态
│   └── API schema
│
├── 工程化
│   ├── PlatformIO依赖锁定
│   ├── Native算法测试
│   ├── 硬件在环与数据回放
│   ├── 日志分级
│   ├── UTF-8与文档单一事实源
│   └── CI构建与静态检查
│
└── 产品化
    ├── Gerber与PCB制造资料
    ├── 飞针测试数据
    ├── OpenSCAD参数化外壳
    ├── 装配公差与器件避让
    ├── Web免安装交互
    └── 硬件成本与精度边界
```

## 长期维护入口

半年后重新开始时，建议按这个顺序：

1. 先读本文的“阅读前事实”和“调试记录”。
2. 核对实际硬件接线与 `main.cpp` 引脚。
3. 执行 PlatformIO 构建并保存构建环境版本。
4. 串口确认 I2C 扫描、GPS 帧率、SPIFFS 和 SD 状态。
5. 先记录一份 raw 数据，再修改滤波或融合参数。
6. 所有新的实测结论更新到本文，同时删除或标记过时文档中的冲突说法。

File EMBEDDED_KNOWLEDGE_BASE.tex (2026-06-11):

% Options for packages loaded elsewhere
\PassOptionsToPackage{unicode}{hyperref}
\PassOptionsToPackage{hyphens}{url}
\PassOptionsToPackage{dvipsnames,svgnames,x11names}{xcolor}
\documentclass[
  UTF8,11pt,a4paper]{ctexart}
\usepackage{xcolor}
\usepackage[margin=2.2cm]{geometry}
\usepackage{amsmath,amssymb}
\setcounter{secnumdepth}{5}
\usepackage{iftex}
\ifPDFTeX
  \usepackage[T1]{fontenc}
  \usepackage[utf8]{inputenc}
  \usepackage{textcomp} % provide euro and other symbols
\else % if luatex or xetex
  \usepackage{unicode-math} % this also loads fontspec
  \defaultfontfeatures{Scale=MatchLowercase}
  \defaultfontfeatures[\rmfamily]{Ligatures=TeX,Scale=1}
\fi
\usepackage{lmodern}
\ifPDFTeX\else
  % xetex/luatex font selection
\fi
% Use upquote if available, for straight quotes in verbatim environments
\IfFileExists{upquote.sty}{\usepackage{upquote}}{}
\IfFileExists{microtype.sty}{% use microtype if available
  \usepackage[]{microtype}
  \UseMicrotypeSet[protrusion]{basicmath} % disable protrusion for tt fonts
}{}
\makeatletter
\@ifundefined{KOMAClassName}{% if non-KOMA class
  \IfFileExists{parskip.sty}{%
    \usepackage{parskip}
  }{% else
    \setlength{\parindent}{0pt}
    \setlength{\parskip}{6pt plus 2pt minus 1pt}}
}{% if KOMA class
  \KOMAoptions{parskip=half}}
\makeatother
\usepackage{listings}
\setmonofont{Microsoft YaHei UI}
\setCJKmonofont{Microsoft YaHei UI}
\lstset{
  basicstyle=\small\ttfamily,
  columns=fullflexible,
  keepspaces=true,
  breaklines=true,
  breakatwhitespace=false,
  showstringspaces=false
}
\newcommand{\passthrough}[1]{#1}
\lstset{defaultdialect=[5.3]Lua}
\lstset{defaultdialect=[x86masm]Assembler}
\usepackage{longtable,booktabs,array}
\newcounter{none} % for unnumbered tables
\usepackage{calc} % for calculating minipage widths
% Correct order of tables after \paragraph or \subparagraph
\usepackage{etoolbox}
\makeatletter
\patchcmd\longtable{\par}{\if@noskipsec\mbox{}\fi\par}{}{}
\makeatother
% Allow footnotes in longtable head/foot
\IfFileExists{footnotehyper.sty}{\usepackage{footnotehyper}}{\usepackage{footnote}}
\makesavenoteenv{longtable}
\setlength{\emergencystretch}{3em} % prevent overfull lines
\providecommand{\tightlist}{%
  \setlength{\itemsep}{0pt}\setlength{\parskip}{0pt}}
\usepackage{bookmark}
\IfFileExists{xurl.sty}{\usepackage{xurl}}{} % add URL line breaks if available
\urlstyle{same}
\hypersetup{
  colorlinks=true,
  linkcolor={teal},
  filecolor={Maroon},
  citecolor={Blue},
  urlcolor={blue},
  pdfcreator={LaTeX via pandoc}}

\title{Embedded Knowledge Base}
\usepackage{etoolbox}
\makeatletter
\providecommand{\subtitle}[1]{% add subtitle to \maketitle
  \apptocmd{\@title}{\par {\large #1 \par}}{}{}
}
\makeatother
\subtitle{ESP32 Draggy Racing Logger 工程知识库}
\author{Workspace Engineering Notes}
\date{2026-06-10}

\begin{document}
\maketitle

{
\setcounter{tocdepth}{3}
\tableofcontents
}
\section{Embedded Knowledge Base}\label{embedded-knowledge-base}

\begin{quote}
面向未来自己的工程复盘。本文以当前工作区源码为事实基线；旧
README、优化报告和面试笔记只作为设计背景，不覆盖代码事实。

最后核查：2026-06-10
\end{quote}

\subsection{目录}\label{ux76eeux5f55}

\begin{enumerate}
\def\labelenumi{\arabic{enumi}.}
\tightlist
\item
  \hyperref[ux7b2cux4e00ux90e8ux5206ux9879ux76eeux5168ux666fux56fe]{第一部分：项目全景图}
\item
  \hyperref[ux7b2cux4e8cux90e8ux5206ux7cfbux7edfux67b6ux6784ux8bbeux8ba1]{第二部分：系统架构设计}
\item
  \hyperref[ux7b2cux4e09ux90e8ux5206ux9879ux76eeux8fd0ux884cux6d41ux7a0b]{第三部分：项目运行流程}
\item
  \hyperref[ux7b2cux56dbux90e8ux5206ux6838ux5fc3ux6a21ux5757ux89e3ux6790]{第四部分：核心模块解析}
\item
  \hyperref[ux7b2cux4e94ux90e8ux5206ux6280ux672fux77e5ux8bc6ux63d0ux53d6]{第五部分：技术知识提取}
\item
  \hyperref[ux7b2cux516dux90e8ux5206ux8bbeux8ba1ux51b3ux7b56ux5206ux6790]{第六部分：设计决策分析}
\item
  \hyperref[ux7b2cux4e03ux90e8ux5206ux8c03ux8bd5ux4e0eux8e29ux5751ux8bb0ux5f55]{第七部分：调试与踩坑记录}
\item
  \hyperref[ux7b2cux516bux90e8ux5206ux5de5ux7a0bux5b9eux8df5ux603bux7ed3]{第八部分：工程实践总结}
\item
  \hyperref[ux7b2cux4e5dux90e8ux5206ux9879ux76eeux590dux76d8]{第九部分：项目复盘}
\item
  \hyperref[ux7b2cux5341ux90e8ux5206ux4e2aux4ebaux77e5ux8bc6ux5730ux56fe]{第十部分：个人知识地图}
\end{enumerate}

\begin{center}\rule{0.5\linewidth}{0.5pt}\end{center}

\subsection{阅读前先知道的事实}\label{ux9605ux8bfbux524dux5148ux77e5ux9053ux7684ux4e8bux5b9e}

这个仓库只有一个主固件项目，但它经历了明显演化：

\begin{enumerate}
\def\labelenumi{\arabic{enumi}.}
\tightlist
\item
  最初是 ESP32 + MPU6050 + OLED 的双 I2C 演示。
\item
  后来加入 GT-U7 GPS，目标变成低成本 Dragy 风格车辆性能仪。
\item
  再加入摩托车倾角/G 力分析、Wi-Fi 网页、音频录制、SD 卡日志、PCB 和 3D
  打印外壳。
\end{enumerate}

因此旧文档与当前代码有冲突。以后判断``现在是什么''，优先级应为：

\begin{lstlisting}
当前源码与 platformio.ini
        >
当前硬件接线和实测记录
        >
README / GPS 优化报告 / 面试笔记
\end{lstlisting}

当前已发现的版本漂移：

{\def\LTcaptype{none} % do not increment counter
\begin{longtable}[]{@{}lll@{}}
\toprule\noalign{}
主题 & 当前源码 & 旧文档中的其他说法 \\
\midrule\noalign{}
\endhead
\bottomrule\noalign{}
\endlastfoot
I2C & MPU: GPIO21/22；OLED: GPIO18/19，两条总线 & README 曾写 21/19 与
25/26；GPS\_WIRING 曾写共享 21/22 \\
GPS 串口 & UART2，GPIO16/17，9600 bps & 优化报告写过 38400 bps \\
GPS 更新率 & 启动配置 10 Hz；掉线恢复时改为 5 Hz & 文档同时出现 5 Hz、10
Hz \\
SD 卡 & 模块完整，但 \passthrough{\lstinline!setup()!} 初始化被注释 &
部分描述把它写成可直接使用 \\
GPS-IMU 融合 & \passthrough{\lstinline!loop()!} 每 5 ms 调用
\passthrough{\lstinline!fuseIMUSpeed()!} &
\passthrough{\lstinline!/data!} 的 \passthrough{\lstinline!imuSpeed!}
仍固定输出 0，注释称暂未实现 \\
摩托互补滤波 & 已在 \passthrough{\lstinline!performance\_analyzer.cpp!}
实现 & 面试笔记部分段落称姿态互补滤波未实现 \\
\end{longtable}
}

编码方面，大量中文文件显示为 mojibake，说明文件很可能曾以 UTF-8
保存、后被错误编码链处理。代码符号仍可读，但这是长期维护风险。

\begin{center}\rule{0.5\linewidth}{0.5pt}\end{center}

\section{第一部分：项目全景图}\label{ux7b2cux4e00ux90e8ux5206ux9879ux76eeux5168ux666fux56fe}

\section{ESP32 Draggy Racing Logger}\label{esp32-draggy-racing-logger}

\subsection{项目背景}\label{ux9879ux76eeux80ccux666f}

项目想用低成本器件做一个车载/摩托车数据终端：实时读取车辆运动状态，显示速度、姿态、G
力和性能测试结果，并让手机不安装 App 也能查看数据。

真正困难的不是``读出传感器''，而是车辆环境：

\begin{itemize}
\tightlist
\item
  发动机和路面引入高频振动。
\item
  MPU6050 有零偏、温漂和安装坐标误差。
\item
  GT-U7 在静止和弱信号时会速度漂移。
\item
  GPS 只有低频绝对速度，IMU 有高频响应但积分漂移。
\item
  Web、OLED、采样、录音和存储都跑在同一个 Arduino 主循环中。
\end{itemize}

\subsection{项目目标}\label{ux9879ux76eeux76eeux6807}

当前代码试图实现：

\begin{itemize}
\tightlist
\item
  200 Hz IMU 采样与滤波。
\item
  10 Hz GPS 解析、静止抑制和性能计时。
\item
  GPS-IMU 速度与 G 力的轻量融合。
\item
  摩托车倾角、弯道、翘头/翘尾和峰值统计。
\item
  OLED 本地显示。
\item
  ESP32 SoftAP + HTTP Web 仪表盘。
\item
  SPIFFS 低码率 WAV 录音。
\item
  SD 卡 10 Hz CSV 行驶日志。
\item
  与 PCB 配套的参数化 OpenSCAD 外壳。
\end{itemize}

必须区分：SD 记录代码存在，但当前启动流程没有初始化 SD
卡，所以默认不会真正记录。

\subsection{技术栈}\label{ux6280ux672fux6808}

{\def\LTcaptype{none} % do not increment counter
\begin{longtable}[]{@{}ll@{}}
\toprule\noalign{}
类别 & 使用内容 \\
\midrule\noalign{}
\endhead
\bottomrule\noalign{}
\endlastfoot
MCU & ESP32-WROOM-32 / PlatformIO \passthrough{\lstinline!esp32dev!} \\
框架 & Arduino Framework \\
语言 & C++、HTML/CSS/JavaScript、OpenSCAD \\
传感器 & MPU6050、GT-U7 GPS、模拟麦克风 \\
显示 & SSD1306 128x64 OLED \\
总线 & 双 I2C、UART2、HSPI、ADC1 \\
网络 & Wi-Fi SoftAP、HTTP \passthrough{\lstinline!WebServer!} \\
存储 & SPIFFS、SD/FAT CSV \\
数据格式 & NMEA、JSON、CSV、PCM WAV \\
构建 & PlatformIO \\
机械 & Gerber、OpenSCAD、STL \\
\end{longtable}
}

\subsection{项目一句话总结}\label{ux9879ux76eeux4e00ux53e5ux8bddux603bux7ed3}

基于 ESP32 构建低成本车载多传感器性能记录仪，融合 200 Hz IMU 与 10 Hz
GPS，实现姿态/G 力分析、性能计时、Web 实时可视化、录音与可扩展数据记录。

\subsection{项目目录结构分析}\label{ux9879ux76eeux76eeux5f55ux7ed3ux6784ux5206ux6790}

\begin{lstlisting}
esp32-imu/
├── src/                         固件主源码
│   ├── main.cpp                 系统装配、调度、OLED、HTTP API
│   ├── mpu6050.*                IMU 驱动、滤波、基础姿态
│   ├── gps_module.*             GPS、性能测试、速度融合、会话持久化
│   ├── performance_analyzer.*   G 力融合、车辆行为、摩托车分析
│   ├── audio_recorder.*         ADC 定时采样、WAV、自动录音
│   └── sd_logger.*              SD 初始化与 CSV 日志
├── data/index.html              SPIFFS Web 仪表盘
├── cad/                         PCB 外壳源码与 STL
├── platformio.ini               板卡、串口、依赖、SPIFFS 配置
├── README.md                    早期项目说明，已落后于源码
├── BUILD_GUIDE.md               PlatformIO 构建与排错说明
├── GPS_*.md                     GPS 接线、升级与优化思路
├── GT-U7_*.md                   GT-U7 优化总结，部分内容未与代码同步
├── INTERVIEW_NOTES.md           技术复盘素材，不是运行事实来源
├── Gerber_*.zip                 PCB 制造文件
├── wiring_diagram.txt           接线说明，接近当前双 I2C 方案
├── include/ lib/ test/          PlatformIO 模板目录，暂无自有实现/测试
└── interview/                   LaTeX/PDF 派生文档，不属于固件运行链
\end{lstlisting}

PCB 和外壳是同一产品化尝试的一部分，不应误识别为独立软件项目。Gerber
表明存在双层
PCB、丝印、阻焊、钻孔和飞针测试数据；无法仅从当前工作区确定实际焊接版本和最终
BOM。

\begin{center}\rule{0.5\linewidth}{0.5pt}\end{center}

\section{第二部分：系统架构设计}\label{ux7b2cux4e8cux90e8ux5206ux7cfbux7edfux67b6ux6784ux8bbeux8ba1}

\section{系统架构}\label{ux7cfbux7edfux67b6ux6784}

\subsection{总体架构}\label{ux603bux4f53ux67b6ux6784}

\begin{lstlisting}
                   +---------------- ESP32 ----------------+
MPU6050 -- I2C0 -->| 采样/均值/IIR --> 姿态与G力 --------+ |
                   |                                      | |
GT-U7 ---- UART2 ->| NMEA解析/质量判断/速度滤波 --------+ | |
                   |                                    | | |
Mic ------ ADC1 -->| Timer ISR --> WAV缓冲 --> SPIFFS   | | |
                   |                                    v v |
SD Card --- HSPI <-| CSV Logger <--- 融合/性能/摩托分析器  |
                   |                    |                 |
OLED ----- I2C1 <--| 本地显示 <---------+                 |
                   |                    v                 |
Phone <-- Wi-Fi ---| WebServer --> JSON API --> index.html|
                   +--------------------------------------+
\end{lstlisting}

\subsection{为什么这样拆分}\label{ux4e3aux4ec0ux4e48ux8fd9ux6837ux62c6ux5206}

\begin{itemize}
\tightlist
\item
  \passthrough{\lstinline!main.cpp!} 是 composition
  root：拥有硬件实例、启动顺序和时间调度。
\item
  驱动/算法按数据源拆分：IMU、GPS、音频、SD 各自维护状态。
\item
  \passthrough{\lstinline!performance\_analyzer!}
  位于传感器之上，读取全局 IMU/GPS 数据形成派生指标。
\item
  OLED 和 HTTP 是两个输出适配器，共享同一批全局状态。
\end{itemize}

这套拆法适合原型开发，新增功能快；代价是模块通过
\passthrough{\lstinline!extern!}
全局结构体耦合，调用顺序就是隐含的数据一致性协议。

\subsection{数据链路}\label{ux6570ux636eux94feux8def}

\subsubsection{运动数据链}\label{ux8fd0ux52a8ux6570ux636eux94fe}

\begin{lstlisting}
MPU6050 raw acceleration/gyro
        |
        v
10点移动平均 + 一阶IIR
        |
        +--> Roll/Pitch
        +--> G力/驾驶状态
        +--> 摩托倾角互补滤波
        +--> IMU速度积分
                         \
GT-U7 NMEA --> GPS速度 ---> 轻量互补修正 --> 性能指标/Web/OLED/CSV
\end{lstlisting}

GPS 提供长期不漂移的绝对速度；IMU
提供短期快速变化。当前实现不是严格卡尔曼滤波，而是偏置校准、死区、积分和
GPS 比例拉回。

\subsubsection{展示链}\label{ux5c55ux793aux94fe}

\begin{lstlisting}
全局状态结构体
   +--> OLED: 20 Hz，五种页面
   +--> /data: Web主仪表盘
   +--> /moto: 摩托数据
   +--> /audio: 录音状态
   +--> Serial: 5 Hz简报 / 2 s详细信息
\end{lstlisting}

\subsubsection{存储链}\label{ux5b58ux50a8ux94fe}

\begin{lstlisting}
Mic ADC --> 8-bit/8 kHz PCM --> 512 B buffer --> SPIFFS WAV
GPS+IMU+Fusion --> RideDataPoint --> CSV line --> SD card
Browser samples --> JavaScript memory --> client-side CSV/JSON export
\end{lstlisting}

这里实际上有三套``记录''：SPIFFS 音频、SD
原始/融合数据、浏览器内存记录。它们没有统一会话 ID 和时间基准。

\begin{center}\rule{0.5\linewidth}{0.5pt}\end{center}

\section{第三部分：项目运行流程}\label{ux7b2cux4e09ux90e8ux5206ux9879ux76eeux8fd0ux884cux6d41ux7a0b}

\section{上电初始化}\label{ux4e0aux7535ux521dux59cbux5316}

\begin{lstlisting}
Reset
  |
  v
Serial 115200 + BOOT输入
  |
  v
双I2C 400 kHz初始化 -> 扫描设备
  |
  v
MPU6050 -> GPS -> 性能分析 -> 摩托模式 -> 音频
  |
  v
SD初始化跳过（当前测试模式）
  |
  v
OLED -> SPIFFS -> Wi-Fi SoftAP -> HTTP路由
  |
  v
显示连接信息，进入 loop()
\end{lstlisting}

值得注意：\passthrough{\lstinline!initAudioRecorder()!} 在
\passthrough{\lstinline!SPIFFS.begin(true)!} 之前读取 SPIFFS
容量。首次启动或文件系统异常时，这个顺序不稳妥，应该先挂载文件系统。

\section{主循环调度}\label{ux4e3bux5faaux73afux8c03ux5ea6}

项目没有 FreeRTOS 显式任务，也没有统一 scheduler，而是
\passthrough{\lstinline!millis()!} 驱动的协作式时间片：

\begin{lstlisting}
loop()
  |
  +--> server.handleClient()
  +--> BOOT按键与串口命令
  |
  +--> 每5 ms:
  |      ReadMPU6050()
  |      fuseIMUSpeed()
  |
  +--> 每100 ms:
  |      updateGPSData()
  |      checkAutoLogging()
  |      optional logDataPoint()
  |
  +--> 每次循环:
  |      updateAudioRecorder()
  |
  +--> 每50 ms:
         updateFusedData()
         update OLED
         print serial
\end{lstlisting}

优点是易读、没有任务同步成本。问题是任何阻塞操作都会破坏所有``频率承诺''。HTTP
文件传输、GPS 重连 \passthrough{\lstinline!delay()!}、OLED I2C、SD flush
和串口输出都可能让 5 ms/125 us 级任务失约。

\section{中断流程}\label{ux4e2dux65adux6d41ux7a0b}

唯一明确的用户中断路径是音频定时器：

\begin{lstlisting}
125 us timer
   |
   v
ISR: adc1_get_raw()
   |
   +--> lastSample = sample
   +--> sampleReady = true
             |
             v
主循环 processSample()
   |
   +--> 12 bit转8 bit
   +--> 更新音量
   +--> 写入512 B缓冲
   +--> 缓冲满后写SPIFFS
\end{lstlisting}

这不是可靠的生产者-消费者队列。若主循环在两个中断之间没有消费，\passthrough{\lstinline!lastSample!}
被覆盖，只保留最新样本。

\section{通信流程}\label{ux901aux4fe1ux6d41ux7a0b}

\subsection{GPS}\label{gps}

\begin{lstlisting}
UART2 bytes
  -> TinyGPS++ encode
  -> location/speed/time/satellite/HDOP
  -> 合理范围与跳变检查
  -> 速度20点窗口、方差、自适应滤波、死区
  -> GPS_DATA
\end{lstlisting}

超过 3 秒无可解析数据会标记丢失；每 10
秒发送热启动和恢复配置。恢复配置将更新周期设置为 5 Hz，与启动时 10 Hz
不一致。

\subsection{Web}\label{web}

ESP32 创建 \passthrough{\lstinline!ESP32-IMU!} 热点，密码硬编码为
\passthrough{\lstinline!12345678!}，地址通常为
\passthrough{\lstinline!192.168.4.1!}。

{\def\LTcaptype{none} % do not increment counter
\begin{longtable}[]{@{}ll@{}}
\toprule\noalign{}
路由 & 作用 \\
\midrule\noalign{}
\endhead
\bottomrule\noalign{}
\endlastfoot
\passthrough{\lstinline!/!} & 从 SPIFFS 流式返回
\passthrough{\lstinline!index.html!} \\
\passthrough{\lstinline!/data!} & 通用速度、GPS、G 力、性能 JSON \\
\passthrough{\lstinline!/moto!} & 摩托倾角、事件和峰值 JSON \\
\passthrough{\lstinline!/audio!} & 录音状态 JSON \\
\passthrough{\lstinline!/audio/control?action=...!} &
开始、停止、暂停、恢复、删除、自动模式、列表 \\
\passthrough{\lstinline!/audio/download?file=...!} & 下载 WAV \\
\end{longtable}
}

网页每 150 ms 请求 \passthrough{\lstinline!/data!}，每 100 ms 请求
\passthrough{\lstinline!/moto!}。这是轮询架构，简单但请求频繁，且
\passthrough{\lstinline!/moto!} 请求本身会再次调用
\passthrough{\lstinline!updateMotorcycleData()!}，使算法更新时间受浏览器请求节奏影响。

\section{状态机}\label{ux72b6ux6001ux673a}

\subsection{音频录制}\label{ux97f3ux9891ux5f55ux5236}

\begin{lstlisting}
IDLE/STOPPED -- speed >= 5 --> ACTIVE
ACTIVE -- speed < 2 for 5s --> STOPPED
ACTIVE -- pause ------------> PAUSED
PAUSED -- resume -----------> ACTIVE
ACTIVE -- 300s -------------> STOPPED
\end{lstlisting}

\passthrough{\lstinline!RECORDING\_WAITING!}
被定义但当前逻辑基本未使用。

\subsection{性能测试}\label{ux6027ux80fdux6d4bux8bd5}

\begin{itemize}
\tightlist
\item
  加速：速度超过 5 km/h 自动开始，穿越 60/100/200 km/h 时记录时间。
\item
  制动：速度达到约 95 km/h 后进入条件，降到 5 km/h 结束。
\item
  圈速字段和函数声明存在，但完整实现无法从当前工作区确定。
\end{itemize}

\begin{center}\rule{0.5\linewidth}{0.5pt}\end{center}

\section{第四部分：核心模块解析}\label{ux7b2cux56dbux90e8ux5206ux6838ux5fc3ux6a21ux5757ux89e3ux6790}

\section{\texorpdfstring{\texttt{main.cpp}：系统装配与输出层}{main.cpp：系统装配与输出层}}\label{maincppux7cfbux7edfux88c5ux914dux4e0eux8f93ux51faux5c42}

职责：

\begin{itemize}
\tightlist
\item
  创建两条 \passthrough{\lstinline!TwoWire!} 总线、OLED、WebServer。
\item
  固定初始化顺序和主循环频率。
\item
  把全局数据编码为 OLED 页面和 JSON。
\item
  管理 BOOT 按键及串口模式。
\end{itemize}

关键设计是多速率协作循环。最大问题是文件已超过千行，HTTP、OLED、调度和业务拼在一起，修改一个输出字段容易影响实时路径。

\section{\texorpdfstring{\texttt{mpu6050}：高振动车辆 IMU
前端}{mpu6050：高振动车辆 IMU 前端}}\label{mpu6050ux9ad8ux632fux52a8ux8f66ux8f86-imu-ux524dux7aef}

核心结构 \passthrough{\lstinline!MPU6050\_DATA!}
同时保存原始和滤波后的加速度、角速度、Roll/Pitch。

处理链：

\begin{lstlisting}
Adafruit getEvent()
 -> 10样本滑动平均
 -> alpha=0.1 一阶IIR
 -> 加速度倾角
\end{lstlisting}

量程为 ±8 g、±500 deg/s，DLPF 为 94 Hz。选择 94 Hz
是为了保留快速车辆动作，再依赖软件滤波压制振动。

注意：

\begin{itemize}
\tightlist
\item
  \passthrough{\lstinline!CalculateAttitude()!} 的基础 Roll/Pitch
  仅使用加速度计。
\item
  \passthrough{\lstinline!Yaw!} 固定为 0。
\item
  陀螺数据在 Adafruit API 中是 rad/s，但摩托互补滤波直接按 deg/s
  积分的迹象很强；若未转换，倾角动态项会缩小约 57.3
  倍。需要实机与库单位确认后修正。
\item
  初始滤波状态为 0，会有启动爬升过程。
\end{itemize}

\section{\texorpdfstring{\texttt{gps\_module}：GPS、速度与性能计时}{gps\_module：GPS、速度与性能计时}}\label{gps_modulegpsux901fux5ea6ux4e0eux6027ux80fdux8ba1ux65f6}

核心结构：

\begin{itemize}
\tightlist
\item
  \passthrough{\lstinline!GPS\_DATA!}：位置、时间、速度、信号质量、融合状态。
\item
  \passthrough{\lstinline!PERFORMANCE\_DATA!}：加速、制动、圈速和会话数据。
\end{itemize}

主要策略：

\begin{itemize}
\tightlist
\item
  仅输出 RMC/GGA，降低 9600 bps 下 NMEA 堵塞风险。
\item
  开启 SBAS/WAAS。
\item
  对位置做经纬度范围和 1 km 单帧跳变检查。
\item
  对速度做 20 点窗口、标准差、卫星/HDOP 动态阈值、分段 IIR 和最终死区。
\item
  静止时收集 200 个样本估计 IMU 前向偏置。
\item
  IMU 积分速度每次 GPS 新帧向 GPS 拉回 10\%。
\end{itemize}

设计意图正确，但实现中 \passthrough{\lstinline!gps\_data.speed\_ms!}
很少被明确同步为当前 GPS 速度，而校准与静止归零依赖它；应统一只使用
\passthrough{\lstinline!speed\_mps!} 或明确维护该字段。

\section{\texorpdfstring{\texttt{performance\_analyzer}：派生指标与摩托语义}{performance\_analyzer：派生指标与摩托语义}}\label{performance_analyzerux6d3eux751fux6307ux6807ux4e0eux6469ux6258ux8bedux4e49}

\passthrough{\lstinline!FUSED\_PERFORMANCE\_DATA!} 保存当前速度/G
力、峰值、行为状态和质量分数。

主要功能：

\begin{itemize}
\tightlist
\item
  组合 IMU 加速度与 GPS 速度差分。
\item
  检测加速、制动、转弯。
\item
  用车辆质量、滚阻、风阻估算瞬时功率。
\item
  用互补滤波估计摩托倾角和俯仰。
\item
  检测弯道、翘头、翘尾，估算弯道半径。
\end{itemize}

这里把``信号处理''和``车辆业务语义''放在同一模块，原型阶段方便，但未来应拆成：

\begin{lstlisting}
Sensor Fusion
Vehicle Frame Transform
Event Detector
Session Statistics
\end{lstlisting}

硬编码偏置 \passthrough{\lstinline!-0.47/+0.5/-0.48!} 和假定坐标
\passthrough{\lstinline!X=垂直、Y=侧向、Z=前向!}
是整个分析可信度的基础。换安装方向或换板后必须重新标定。

\section{\texorpdfstring{\texttt{audio\_recorder}：低码率事件录音}{audio\_recorder：低码率事件录音}}\label{audio_recorderux4f4eux7801ux7387ux4e8bux4ef6ux5f55ux97f3}

配置为单声道、8 kHz、8 bit PCM，每秒约 8 KB，5 分钟约 2.4
MB，不含文件系统开销。

WAV
头在开始时写占位值，停止时回写文件大小。这种方式简单，但异常断电会留下头部未完成的文件。

最大架构问题是 ISR 只有一个样本槽，不是
DMA/环形缓冲。录音数据完整性无法保证。

\section{\texorpdfstring{\texttt{sd\_logger}：行驶
CSV}{sd\_logger：行驶 CSV}}\label{sd_loggerux884cux9a76-csv}

SD 使用 HSPI：

\begin{lstlisting}
MISO GPIO25
MOSI GPIO13
SCK  GPIO14
CS   GPIO15
\end{lstlisting}

选择 GPIO25 替代 GPIO12，是为了规避 ESP32 启动绑带引脚风险。日志以 10 Hz
写 CSV，每 100 点 flush 一次，在数据安全和写入开销之间折中。

当前 \passthrough{\lstinline!setup()!} 没有调用
\passthrough{\lstinline!initSDCard()!}，因此
\passthrough{\lstinline!checkAutoLogging()!} 会因
\passthrough{\lstinline!initialized=false!} 直接返回。

\section{\texorpdfstring{\texttt{data/index.html}：无 App Web
仪表盘}{data/index.html：无 App Web 仪表盘}}\label{dataindexhtmlux65e0-app-web-ux4eeaux8868ux76d8}

单文件前端包含：

\begin{itemize}
\tightlist
\item
  实时速度/G 力曲线。
\item
  性能、GPS、摩托状态。
\item
  浏览器端会话记录与 CSV/JSON 导出。
\item
  录音控制逻辑。
\end{itemize}

优点是部署简单。缺点是 HTML 已很大、编码损坏明显、无构建/校验、API
字段靠手写约定。浏览器记录只存在内存，刷新即丢失。

\section{\texorpdfstring{\texttt{cad/pcb1\_enclosure.scad}：参数化产品外壳}{cad/pcb1\_enclosure.scad：参数化产品外壳}}\label{cadpcb1_enclosurescadux53c2ux6570ux5316ux4ea7ux54c1ux5916ux58f3}

外壳从 Gerber 轮廓推导出 78.867 x 70.866 mm、圆角 5.08 mm 的 PCB：

\begin{itemize}
\tightlist
\item
  底壳用周边支撑环和卡扣固定无安装孔 PCB。
\item
  上盖使用局部器件避让腔。
\item
  四角外置螺钉耳避免占用板内空间。
\item
  提供通风槽、边缘开口、装配/爆炸/导出模式。
\end{itemize}

器件高度和接口位置是从丝印/飞针数据推断的，不是装配实测。打印前必须实测校核。

\begin{center}\rule{0.5\linewidth}{0.5pt}\end{center}

\section{第五部分：技术知识提取}\label{ux7b2cux4e94ux90e8ux5206ux6280ux672fux77e5ux8bc6ux63d0ux53d6}

\section{双 I2C}\label{ux53cc-i2c}

\subsection{为什么需要它}\label{ux4e3aux4ec0ux4e48ux9700ux8981ux5b83}

MPU6050 与 OLED 本可共享地址不同的总线，但 OLED 整帧刷新会占用 I2C
时间。分成两条控制器可以隔离显示流量与传感器采样，也方便独立排错。

\subsection{项目中的实际应用}\label{ux9879ux76eeux4e2dux7684ux5b9eux9645ux5e94ux7528}

\begin{itemize}
\tightlist
\item
  I2C0：GPIO21/22，MPU6050。
\item
  I2C1：GPIO18/19，SSD1306。
\item
  两者均配置 400 kHz。
\end{itemize}

\subsection{常见 Bug 与调试}\label{ux5e38ux89c1-bug-ux4e0eux8c03ux8bd5}

\begin{itemize}
\tightlist
\item
  文档接线漂移是当前首要风险。
\item
  地址应扫描确认：MPU 0x68/0x69，OLED 0x3C/0x3D。
\item
  线长、上拉、电源噪声会导致间歇 NACK。
\item
  用现有 \passthrough{\lstinline!scanI2CDevices()!}
  先区分接线问题与驱动问题。
\end{itemize}

替代方案是共享一条 I2C，节省引脚；对本项目而言隔离总线更适合实时采样。

\section{UART 与 NMEA}\label{uart-ux4e0e-nmea}

GT-U7 通过 UART2 输入 NMEA。项目只保留 RMC 与 GGA，因为 10 Hz、9600 bps
时全量语句容易占满串口带宽。

常见坑：

\begin{itemize}
\tightlist
\item
  模块不一定兼容所有 PMTK 命令。
\item
  发送 10 Hz 配置不代表模块确实进入 10 Hz。
\item
  掉线恢复又设置 5 Hz，导致运行状态不一致。
\item
  应统计每秒完整 RMC/GGA 帧数，而不是只相信配置命令。
\end{itemize}

\section{采样与数字滤波}\label{ux91c7ux6837ux4e0eux6570ux5b57ux6ee4ux6ce2}

项目使用了三类低成本滤波：

\begin{itemize}
\tightlist
\item
  硬件 DLPF：在传感器内部先限制带宽。
\item
  滑动平均：压制随机噪声，但引入窗口延迟。
\item
  一阶 IIR：O(1) 状态，适合 MCU，但有相位延迟。
\end{itemize}

常见误区是把``200 Hz
调用周期''当成严格采样率。当前系统是协作循环，实际采样间隔会抖动，且代码给融合器的
\passthrough{\lstinline!dt!} 固定为 5 ms，没有用真实时间差。

调试时应同时记录：

\begin{itemize}
\tightlist
\item
  实际 \passthrough{\lstinline!micros()!} 间隔分布。
\item
  原始值、滑动平均值、IIR 值。
\item
  静止 RMS、阶跃响应和相位延迟。
\end{itemize}

\section{GPS 静止漂移}\label{gps-ux9759ux6b62ux6f02ux79fb}

GPS
低速时噪声可能大于真实速度。项目不是简单小于阈值清零，而是综合窗口方差、连续稳定次数、卫星数和
HDOP。

这能改善显示，但阈值滤波也会吃掉真实低速起步，使 0-100
起点变晚。性能计时最好保留原始 Doppler
速度和滤波速度两路，分别服务计时与 UI。

\section{GPS-IMU 融合}\label{gps-imu-ux878dux5408}

当前思路：

\begin{lstlisting}
IMU: 高频预测，但漂移
GPS: 低频校正，但延迟和低速噪声
\end{lstlisting}

项目采用简化互补校正而非
EKF，优点是参数直观、计算低。缺点是没有显式状态协方差、时间戳对齐、姿态重力补偿和传感器延迟模型。

真正升级时，优先实现一维状态
\passthrough{\lstinline![速度, 加速度偏置]!} 的 Kalman
filter，而不是直接上完整 9/15 状态导航 EKF。

\section{ADC、Timer 与音频}\label{adctimer-ux4e0eux97f3ux9891}

定时器中断可以建立稳定采样节拍，但 ISR
应只搬运数据，不能依赖单槽共享变量承载连续流。

更合适的方案：

\begin{itemize}
\tightlist
\item
  ESP32 I2S ADC/DMA。
\item
  ISR 写入 lock-free ring buffer。
\item
  双缓冲，由任务批量写文件。
\end{itemize}

此外 8-bit unsigned PCM 的直流中心假设是 128；模拟麦克风偏置和 ADC
非线性应实测。

\section{SPI、SD 与文件系统}\label{spisd-ux4e0eux6587ux4ef6ux7cfbux7edf}

SD 写入延迟具有长尾，\passthrough{\lstinline!flush()!}
可能阻塞几十毫秒。若和 200 Hz 采样同循环，必须缓冲解耦。

SPIFFS 适合少量静态资源和小文件，不适合高频持续音频写入。LittleFS 或 SD
更适合长期录音；异常断电还需要临时文件和恢复策略。

\section{Wi-Fi 与 HTTP}\label{wi-fi-ux4e0e-http}

SoftAP 让手机直接连接，现场无需路由器，这是很实用的产品决策。

当前轮询方案的常见问题：

\begin{itemize}
\tightlist
\item
  多客户端会放大 CPU 和 JSON 序列化开销。
\item
  同步 \passthrough{\lstinline!WebServer!} 的流式下载可能阻塞采样。
\item
  \passthrough{\lstinline!sprintf!} 固定缓冲区依赖字段长度，需用
  \passthrough{\lstinline!snprintf!}。
\item
  密码硬编码，适合原型但不适合发布。
\end{itemize}

替代方案：Server-Sent Events 或 WebSocket
推送，并将静态资源缓存与实时数据通道分离。

\begin{center}\rule{0.5\linewidth}{0.5pt}\end{center}

\section{第六部分：设计决策分析}\label{ux7b2cux516dux90e8ux5206ux8bbeux8ba1ux51b3ux7b56ux5206ux6790}

\section{双 I2C
而不是共享总线}\label{ux53cc-i2c-ux800cux4e0dux662fux5171ux4eabux603bux7ebf}

背景：显示更新与高频 IMU 读取争用总线。

优点：故障隔离、时序可控、扫描清晰。缺点：多占两根 GPIO，接线复杂。当前
ESP32 引脚尚可，选择合理。

\section{协作式调度而不是 FreeRTOS
任务}\label{ux534fux4f5cux5f0fux8c03ux5ea6ux800cux4e0dux662f-freertos-ux4efbux52a1}

背景：Arduino 原型需要快速迭代。

优点：控制流直观、调试容易。缺点：所有模块共享阻塞预算，无法保证 200 Hz
IMU 和 8 kHz 音频。

当前方案适合功能验证；当音频、SD 和网络同时开启时，应迁移为任务和队列：

\begin{lstlisting}
Core/Task Sensor -> Queue -> Fusion
Core/Task IO     -> SD/SPIFFS/Web
\end{lstlisting}

\section{多级滤波而不是单一滤波器}\label{ux591aux7ea7ux6ee4ux6ce2ux800cux4e0dux662fux5355ux4e00ux6ee4ux6ce2ux5668}

车辆振动覆盖宽频段，单一强低通会造成明显延迟。硬件 DLPF、移动平均和 IIR
分层容易调参，但当前级联实际带宽没有通过测试数据验证。

替代方案包括双二阶 Butterworth、陷波器、Savitzky-Golay
或频域分析后定制滤波。应先采集原始数据做 PSD，再决定，而不是继续堆滤波。

\section{互补滤波而不是
EKF}\label{ux4e92ux8865ux6ee4ux6ce2ux800cux4e0dux662f-ekf}

当前传感器精度有限，且原型更需要可解释性。互补滤波成本低、故障容易定位。

缺点是重力投影、安装误差和时间同步需要手工处理。等硬件、坐标系和时间戳稳定后，再引入一维
KF 或姿态 EKF。

\section{阈值状态机}\label{ux9608ux503cux72b6ux6001ux673a}

自动录音、SD 日志、加速/制动、弯道检测都采用阈值 + 延时/滞回。

优点是行为可解释；缺点是阈值分散在多个文件，且录音与 SD
的起停参数不一致：

\begin{itemize}
\tightlist
\item
  录音停止延时 5 秒。
\item
  SD 停止延时 30 秒。
\end{itemize}

应集中成
\passthrough{\lstinline!VehicleSessionConfig!}，并用一次会话状态驱动所有记录器。

\section{浏览器端导出}\label{ux6d4fux89c8ux5668ux7aefux5bfcux51fa}

浏览器记录减轻 ESP32
存储压力，开发方便。但手机锁屏、刷新、断连都会丢数据，不能替代设备端可靠日志。它更适合作为``即时观察与临时导出''。

\begin{center}\rule{0.5\linewidth}{0.5pt}\end{center}

\section{第七部分：调试与踩坑记录}\label{ux7b2cux4e03ux90e8ux5206ux8c03ux8bd5ux4e0eux8e29ux5751ux8bb0ux5f55}

\section{调试记录
1：文档与固件接线冲突}\label{ux8c03ux8bd5ux8bb0ux5f55-1ux6587ux6863ux4e0eux56faux4ef6ux63a5ux7ebfux51b2ux7a81}

问题：按旧 README 接线可能找不到设备。

原因：项目从共享 I2C 演进到双 I2C，文档未统一。

定位：以 \passthrough{\lstinline!main.cpp!} 宏和启动扫描输出为准。

解决：维护唯一
\passthrough{\lstinline!HARDWARE\_PINOUT.md!}，其他文档只链接，不复制引脚表。

经验：硬件配置必须单一事实源。

\section{调试记录
2：音频丢采样}\label{ux8c03ux8bd5ux8bb0ux5f55-2ux97f3ux9891ux4e22ux91c7ux6837}

问题：WAV 时长、音质或样本数异常。

原因：8 kHz ISR 覆盖单个
\passthrough{\lstinline!lastSample!}；主循环无法保证每 125 us 消费。

定位：比较墙钟时长与
\passthrough{\lstinline!samples\_recorded / 8000!}，统计覆盖次数。

解决：I2S DMA 或环形缓冲，文件写入放到独立任务。

\section{调试记录 3：SD
功能看似存在但不工作}\label{ux8c03ux8bd5ux8bb0ux5f55-3sd-ux529fux80fdux770bux4f3cux5b58ux5728ux4f46ux4e0dux5de5ux4f5c}

问题：速度超过阈值仍不生成 CSV。

原因：\passthrough{\lstinline!initSDCard()!} 在
\passthrough{\lstinline!setup()!}
被注释，\passthrough{\lstinline!sd\_status.initialized!} 始终为 false。

定位：查看启动日志是否打印 SD 容量。

解决：恢复初始化前先解决原注释所说的 I2C/引脚冲突，并增加 Web/串口 SD
状态。

\section{调试记录
4：倾角动态响应可能错误}\label{ux8c03ux8bd5ux8bb0ux5f55-4ux503eux89d2ux52a8ux6001ux54cdux5e94ux53efux80fdux9519ux8bef}

问题：陀螺贡献过弱，倾角主要跟随加速度计。

原因：Adafruit 陀螺输出通常为 rad/s，而摩托代码按 deg/s 注释直接积分。

定位：固定角速度转动，比较原始 gyro、积分角与实际角度。

解决：在驱动边界统一单位，字段命名加入
\passthrough{\lstinline!\_rad\_s!} 或
\passthrough{\lstinline!\_deg\_s!}。

\section{调试记录 5：GPS
模式不一致}\label{ux8c03ux8bd5ux8bb0ux5f55-5gps-ux6a21ux5f0fux4e0dux4e00ux81f4}

问题：掉线恢复后刷新率下降，性能测试响应变化。

原因：启动发送 100 ms 更新命令，恢复发送 200 ms 更新命令。

解决：抽取
\passthrough{\lstinline!configureGPS()!}，启动和恢复调用同一配置；读取实际帧率确认结果。

\section{调试记录 6：启动顺序与
SPIFFS}\label{ux8c03ux8bd5ux8bb0ux5f55-6ux542fux52a8ux987aux5e8fux4e0e-spiffs}

问题：音频模块初始化时容量可能为 0 或状态不可靠。

原因：音频初始化早于 \passthrough{\lstinline!SPIFFS.begin(true)!}。

解决：先初始化存储，再初始化依赖存储的音频和 Web。

\section{调试记录 7：融合字段与 API
不一致}\label{ux8c03ux8bd5ux8bb0ux5f55-7ux878dux5408ux5b57ux6bb5ux4e0e-api-ux4e0dux4e00ux81f4}

问题：内部已经运行速度融合，但网页 \passthrough{\lstinline!imuSpeed!}
永远为 0，\passthrough{\lstinline!speed!} 仍来自 GPS。

原因：算法、状态结构和 JSON 输出没有同时更新。

解决：定义明确字段：\passthrough{\lstinline!gps\_speed!}、\passthrough{\lstinline!imu\_predicted\_speed!}、\passthrough{\lstinline!fused\_speed!}，并建立
API schema 测试。

\section{调试记录 8：HTTP
文件下载路径}\label{ux8c03ux8bd5ux8bb0ux5f55-8http-ux6587ux4ef6ux4e0bux8f7dux8defux5f84}

问题：下载接口可能访问任意 SPIFFS 已知路径，而不仅是录音。

原因：只补 \passthrough{\lstinline!/!} 和检查文件存在，没有限定
\passthrough{\lstinline!/ride\_*.wav!}。

解决：白名单文件名格式，拒绝 \passthrough{\lstinline!..!}、非 WAV
和非录音前缀。

\section{调试记录
9：字符串与缓冲区}\label{ux8c03ux8bd5ux8bb0ux5f55-9ux5b57ux7b26ux4e32ux4e0eux7f13ux51b2ux533a}

问题：JSON/文本字段增长后可能溢出固定缓冲区。

原因：使用 \passthrough{\lstinline!sprintf!} 而非长度受限接口。

解决：改为 \passthrough{\lstinline!snprintf!} 并检查返回值；长期使用
ArduinoJson 流式序列化。

\section{调试记录
10：编码损坏}\label{ux8c03ux8bd5ux8bb0ux5f55-10ux7f16ux7801ux635fux574f}

问题：中文日志、网页标签和文档显示乱码，甚至可能破坏 HTML 标签或 C++
字符串。

原因：文件编码链不一致。

解决：全仓统一 UTF-8，无 BOM；添加
\passthrough{\lstinline!.editorconfig!}，在 CI 中做 UTF-8 解码和
HTML/C++ 基础检查。

\begin{center}\rule{0.5\linewidth}{0.5pt}\end{center}

\section{第八部分：工程实践总结}\label{ux7b2cux516bux90e8ux5206ux5de5ux7a0bux5b9eux8df5ux603bux7ed3}

\subsection{做得好的地方}\label{ux505aux5f97ux597dux7684ux5730ux65b9}

\begin{itemize}
\tightlist
\item
  模块按传感器和业务域拆分，原型意图清楚。
\item
  使用 \passthrough{\lstinline!millis()!} 而不是在主路径大量固定延时。
\item
  对 GPS 弱信号、静止漂移和跳点有工程化防护。
\item
  同时保留原始值、滤波值和峰值，便于调试。
\item
  通过 SoftAP + 单页 Web 降低现场使用门槛。
\item
  SD 选择 HSPI 和非 GPIO12 MISO，体现了对 ESP32 启动绑带的考虑。
\item
  OpenSCAD 参数化外壳把软件项目向可装配设备推进了一步。
\end{itemize}

\subsection{可以改进的地方}\label{ux53efux4ee5ux6539ux8fdbux7684ux5730ux65b9}

\subsubsection{代码组织}\label{ux4ee3ux7801ux7ec4ux7ec7}

\passthrough{\lstinline!main.cpp!} 应拆成：

\begin{lstlisting}
app_scheduler
web_api
oled_view
hardware_config
\end{lstlisting}

全局 \passthrough{\lstinline!extern!}
状态应逐步替换为只读快照或消息结构，至少明确谁写、谁读、更新频率和单位。

\subsubsection{配置管理}\label{ux914dux7f6eux7ba1ux7406}

引脚、采样率、阈值、车辆参数和 Wi-Fi 凭据分散在各文件。建议集中：

\begin{lstlisting}
board_config.h
sensor_config.h
vehicle_config.h
\end{lstlisting}

并把所有物理量写入单位后缀。

\subsubsection{日志}\label{ux65e5ux5fd7}

串口日志丰富，但缺乏级别和节流统一。应使用
\passthrough{\lstinline!LOGE/W/I/D!}，避免高频
\passthrough{\lstinline!Serial.printf!} 破坏实时性。

\subsubsection{错误处理}\label{ux9519ux8befux5904ux7406}

很多初始化失败后继续运行，这是原型的容错思路，但后续函数仍可能假定硬件有效。应维护模块健康状态，并在
UI 显示 degraded mode。

\subsubsection{测试策略}\label{ux6d4bux8bd5ux7b56ux7565}

当前 \passthrough{\lstinline!test/!}
只有模板说明，没有项目测试。最值得先补的是纯算法主机测试：

\begin{itemize}
\tightlist
\item
  Haversine 距离。
\item
  GPS 窗口与静止判定。
\item
  阈值穿越计时。
\item
  WAV 头尺寸。
\item
  CSV 格式。
\item
  互补滤波单位与步进响应。
\item
  状态机起停滞回。
\end{itemize}

硬件在环测试应回放已保存的 NMEA 与 IMU 数据，而不是每次都上车测试。

\subsubsection{构建与 CI}\label{ux6784ux5efaux4e0e-ci}

当前配置锁定库版本是好事。建议 CI 至少执行：

\begin{lstlisting}
pio run
pio test -e native
HTML/JSON schema sanity check
UTF-8 validation
\end{lstlisting}

本次分析环境无法执行构建，因为终端没有可用的
\passthrough{\lstinline!pio!}
命令；因此当前源码是否能完整编译无法从本次静态分析确定。

\begin{center}\rule{0.5\linewidth}{0.5pt}\end{center}

\section{第九部分：项目复盘}\label{ux7b2cux4e5dux90e8ux5206ux9879ux76eeux590dux76d8}

\subsection{最大的亮点}\label{ux6700ux5927ux7684ux4eaeux70b9}

不是简单堆传感器，而是围绕``低成本硬件在真实车辆环境中不可靠''做了多层处理：信号质量、静止抑制、漂移校准、融合、状态机和多终端显示。

\subsection{最大的难点}\label{ux6700ux5927ux7684ux96beux70b9}

多时间尺度和多误差源同时存在：

\begin{itemize}
\tightlist
\item
  音频 8 kHz。
\item
  IMU 200 Hz。
\item
  显示/融合 20 Hz。
\item
  GPS/日志 10 Hz。
\item
  Web 约 6.7/10 Hz。
\end{itemize}

而它们目前共享一个可能阻塞的主循环。真正的系统瓶颈是调度与数据一致性，不再只是算法。

\subsection{学到的知识}\label{ux5b66ux5230ux7684ux77e5ux8bc6}

\begin{itemize}
\tightlist
\item
  传感器数据``能读''与``能用于决策''之间隔着校准、坐标系、滤波、质量评估和时间同步。
\item
  低成本 GPS
  的极限不能只靠软件宣传突破，升级硬件有时比继续堆阈值更合理。
\item
  原型文档很容易落后于代码，尤其是引脚和单位。
\item
  记录系统必须考虑掉电、断连和阻塞长尾。
\item
  机械结构、接线和软件配置应被视为同一系统架构。
\end{itemize}

\subsection{如果重新设计}\label{ux5982ux679cux91cdux65b0ux8bbeux8ba1}

\begin{enumerate}
\def\labelenumi{\arabic{enumi}.}
\tightlist
\item
  先定义统一硬件配置、坐标系和单位。
\item
  使用 I2S DMA 采音，传感器和存储通过队列解耦。
\item
  建立单一 \passthrough{\lstinline!VehicleSession!}
  状态机，统一音频、CSV 和峰值会话。
\item
  所有数据携带 \passthrough{\lstinline!micros()!} 时间戳，融合使用真实
  \passthrough{\lstinline!dt!}。
\item
  保留 raw/filtered/fused 三层数据并定义稳定 API schema。
\item
  先做数据回放工具和 native 单元测试，再调算法。
\item
  用实测频谱和标定数据选择滤波器。
\item
  把网页通信改成 SSE/WebSocket。
\end{enumerate}

\subsection{下一步扩展}\label{ux4e0bux4e00ux6b65ux6269ux5c55}

优先级建议：

\begin{enumerate}
\def\labelenumi{\arabic{enumi}.}
\tightlist
\item
  修复编码、引脚文档和单位问题。
\item
  恢复可验证的 SD 日志，获得真实数据集。
\item
  修复音频采样架构。
\item
  增加时间戳和离线回放测试。
\item
  一维速度/偏置 Kalman filter。
\item
  升级 NEO-M9N 或更高频 GNSS；是否上 RTK 取决于实际计时精度目标。
\item
  增加 OTA、配置页面和会话下载。
\end{enumerate}

无法从当前工作区确定：现有 PCB 是否已经覆盖麦克风与 SD
模块、外壳是否完成实物试装、车辆参数是否经过标定、GPS
优化报告中的量化提升是否来自可复现实测。

\begin{center}\rule{0.5\linewidth}{0.5pt}\end{center}

\section{第十部分：个人知识地图}\label{ux7b2cux5341ux90e8ux5206ux4e2aux4ebaux77e5ux8bc6ux5730ux56fe}

\section{Embedded Knowledge Map}\label{embedded-knowledge-map}

\begin{lstlisting}
嵌入式系统
├── ESP32
│   ├── Arduino Framework
│   ├── GPIO与启动绑带
│   ├── 双I2C控制器
│   ├── UART2
│   ├── HSPI
│   ├── ADC1与硬件Timer
│   ├── SPIFFS
│   └── Wi-Fi SoftAP / HTTP
│
├── 传感器与信号处理
│   ├── MPU6050量程与DLPF
│   ├── 滑动平均
│   ├── 一阶IIR
│   ├── 互补滤波
│   ├── 零偏与安装校准
│   ├── 坐标系映射
│   ├── 重力补偿
│   └── 采样率、抖动与真实dt
│
├── GNSS
│   ├── NMEA RMC/GGA
│   ├── Doppler速度
│   ├── 卫星数与HDOP
│   ├── 静止漂移抑制
│   ├── 跳点过滤
│   ├── SBAS
│   ├── 多频率数据融合
│   └── GT-U7到高性能GNSS升级
│
├── 车辆与机器人数据
│   ├── 纵向/横向/垂直G
│   ├── 加速与制动计时
│   ├── 倾角与俯仰
│   ├── 弯道检测与半径估计
│   ├── 翘头/翘尾事件
│   ├── 峰值与会话统计
│   └── 简化功率估算
│
├── 数据记录
│   ├── WAV/PCM
│   ├── CSV
│   ├── JSON API
│   ├── 环形缓冲与DMA
│   ├── SD写入长尾
│   ├── 掉电一致性
│   └── 浏览器端临时记录
│
├── 软件架构
│   ├── 协作式调度
│   ├── 多速率任务
│   ├── 状态机与滞回
│   ├── 全局状态耦合
│   ├── 消息队列/生产者消费者
│   ├── 模块健康状态
│   └── API schema
│
├── 工程化
│   ├── PlatformIO依赖锁定
│   ├── Native算法测试
│   ├── 硬件在环与数据回放
│   ├── 日志分级
│   ├── UTF-8与文档单一事实源
│   └── CI构建与静态检查
│
└── 产品化
    ├── Gerber与PCB制造资料
    ├── 飞针测试数据
    ├── OpenSCAD参数化外壳
    ├── 装配公差与器件避让
    ├── Web免安装交互
    └── 硬件成本与精度边界
\end{lstlisting}

\subsection{长期维护入口}\label{ux957fux671fux7ef4ux62a4ux5165ux53e3}

半年后重新开始时，建议按这个顺序：

\begin{enumerate}
\def\labelenumi{\arabic{enumi}.}
\tightlist
\item
  先读本文的``阅读前事实''和``调试记录''。
\item
  核对实际硬件接线与 \passthrough{\lstinline!main.cpp!} 引脚。
\item
  执行 PlatformIO 构建并保存构建环境版本。
\item
  串口确认 I2C 扫描、GPS 帧率、SPIFFS 和 SD 状态。
\item
  先记录一份 raw 数据，再修改滤波或融合参数。
\item
  所有新的实测结论更新到本文，同时删除或标记过时文档中的冲突说法。
\end{enumerate}

\end{document}

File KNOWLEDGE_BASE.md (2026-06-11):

# Embedded Knowledge Base

> 个人技术知识库 · ESP32 车载性能仪项目
> 半年后重新打开这个仓库时，**只读这一份文档**就能想起来：当时做了什么、为什么这么设计、数据怎么流、核心技术是什么、踩过哪些坑。
> 生成日期：2026-06-10 · 工作区：`e:\esp32\esp32-imu`

---

## 目录

- [第一部分：项目全景图](#第一部分项目全景图)
- [第二部分：系统架构设计](#第二部分系统架构设计)
- [第三部分：项目运行流程](#第三部分项目运行流程)
- [第四部分：核心模块解析](#第四部分核心模块解析)
- [第五部分：技术知识提取](#第五部分技术知识提取)
- [第六部分：设计决策分析](#第六部分设计决策分析)
- [第七部分：调试与踩坑记录](#第七部分调试与踩坑记录)
- [第八部分：工程实践总结](#第八部分工程实践总结)
- [第九部分：项目复盘](#第九部分项目复盘)
- [第十部分：个人知识地图](#第十部分个人知识地图)

> **关于工作区范围**：当前工作区只有**一个固件项目**（`esp32-imu`），外加它的随附文档（GPS 升级分析、面试归档、接线图、构建指南）和一个 `cad/` 里的 OpenSCAD 外壳模型 + Gerber 压缩包。本文档据此组织。CAD 外壳是该项目的机械配套件，单独在末尾点到为止。

---

# 第一部分：项目全景图

## 项目名称：ESP32 车载性能仪（"Dragy 风格" Performance Box）

### 项目背景

为什么会有这个项目？因为想用便宜的开源硬件，自己做一台**摩托车/汽车的车载性能记录仪**，对标商业产品 Dragy（一种 GPS 性能盒子，专门测 0-100 km/h、0-400m、刹车距离这类加速性能）。商业 Dragy 设备要 2000 元，而一套 ESP32 + MPU6050 + GT-U7 GPS 的料才几十块。

核心挑战不是"读个传感器显示出来"那么简单，而是：

- **传感器装在摩托车上，发动机震动极烈**，MPU6050 原始数据被 20~50 Hz 机械振动淹没。
- **GT-U7 是 30 元级的老 GPS 模块**，静止时速度零漂 ±2 km/h，10 Hz 更新，低速段噪声比信号还大。
- 要在这种"脏数据"上，算出能看的 G 力、倾角、加速测试成绩。

这个项目的真正价值，在于**用软件算法把廉价硬件的潜力榨干**——这也是它后来被整理成面试答辩材料（[INTERVIEW_NOTES.md](INTERVIEW_NOTES.md)）的原因。

### 项目目标

最终想实现一台能：

1. 实时显示**速度 / G 力（纵向、横向、垂直）/ 压弯倾角 / 加速测试成绩**。
2. 自动识别"开始骑行 / 停车"，自动开始/停止数据记录与录音。
3. 把所有数据通过 **WiFi 热点 + 网页**推到手机浏览器（无需 App）。
4. 提供专门的**摩托车模式**：压弯角度、翘头/翘尾检测、弯道半径估算。
5. 数据可落盘（SPIFFS 录音 / SD 卡 CSV 行车数据）。

### 技术栈

| 维度 | 选型 |
|---|---|
| 芯片 | ESP32-WROOM-32（双核 240MHz，板载 WiFi） |
| 框架 | Arduino Framework（基于 ESP-IDF） |
| 操作系统 | 无 RTOS 显式使用，裸机 `loop()` + 软件分时调度（底层是 FreeRTOS，但本项目未直接用任务/队列） |
| 构建系统 | PlatformIO（`platformio.ini`） |
| 语言 | C++（Arduino 风格） + 前端 HTML/CSS/JS（`data/index.html`） |
| 传感器 | MPU6050（6 轴 IMU）、GT-U7（GPS，UBX-M8030 芯片）、模拟麦克风 |
| 显示 | SSD1306 OLED 128×64（I²C） |
| 协议 | I²C（双路）、UART（GPS）、SPI（SD 卡 HSPI）、HTTP（Web）、NMEA/PMTK（GPS 指令） |
| 关键库 | Adafruit MPU6050 / SSD1306 / GFX、TinyGPSPlus、ArduinoJson |
| 机械 | OpenSCAD 参数化外壳（`cad/`） |

### 项目一句话总结（适合放简历）

> 基于 ESP32 + MPU6050 + GT-U7 GPS 自研车载性能仪，通过**三级级联滤波**抑制发动机振动、**GPS-IMU 互补滤波融合**与**动态信心度加权**算法，将 30 元 GPS 模块的静止零漂从 ±2.5 km/h 压到 ±0.8 km/h；实现 0-100 km/h 加速测试、压弯倾角/翘头检测，并通过 WiFi 热点 + 网页实时可视化。

### 项目目录结构分析

```
esp32-imu/
├── platformio.ini              # PlatformIO 工程配置：板型、库依赖、串口
├── src/                        # 固件源码（核心）
│   ├── main.cpp                # 主程序：setup/loop、Web 服务器、OLED 显示、调度
│   ├── mpu6050.{h,cpp}         # IMU 驱动 + 三级振动滤波 + 姿态角计算
│   ├── gps_module.{h,cpp}      # GPS 解析 + 零漂抑制 + GPS-IMU 速度融合 + 性能测试
│   ├── performance_analyzer.{h,cpp} # G 力计算 + 摩托车模式（倾角/弯道/翘头）
│   ├── audio_recorder.{h,cpp}  # ADC 麦克风录音 → WAV，自动骑行触发
│   └── sd_logger.{h,cpp}       # SD 卡 CSV 行车数据记录（HSPI）
├── data/
│   └── index.html              # SPIFFS 网页前端（手机端仪表盘）
├── cad/                        # 机械外壳（OpenSCAD 参数化模型 + STL）
├── interview/                  # LaTeX 版面试材料（main.tex/pdf）
├── INTERVIEW_NOTES.md          # ★ 面试技术答辩归档：踩坑/原理/量化效果（精华）
├── GPS_UPGRADE_ANALYSIS.md     # GPS 硬件升级对比分析
├── GT-U7_ULTIMATE_OPTIMIZATION.md # GT-U7 软件压榨优化记录
├── GPS_WIRING.md / wiring_diagram.txt # 接线图
├── BUILD_GUIDE.md              # 编译/上传/串口/排错指南
└── README.md                   # 原始 README（⚠️ 已与代码脱节，见踩坑记录）
```

> **重点目录提示**：真正的"知识密度"集中在 `src/` 和 `INTERVIEW_NOTES.md`。后者是已经写好的踩坑复盘，本知识库第七部分大量与之呼应。

---

# 第二部分：系统架构设计

## 系统由哪些模块组成

固件按"传感器采集 → 数据融合 → 输出"分层，五个功能模块围绕 `main.cpp` 的调度器协作：

```
┌──────────────────────────────────────────────────────────────┐
│                         main.cpp (调度器)                       │
│   软件分时循环 loop()：按 millis() 时间片驱动各模块             │
└──────────────────────────────────────────────────────────────┘
        │            │             │            │            │
   ┌────▼────┐  ┌────▼────┐   ┌────▼─────┐  ┌───▼────┐  ┌────▼────┐
   │ mpu6050 │  │   gps   │   │ perf_ana │  │ audio  │  │   sd    │
   │  IMU驱动 │  │ GPS解析  │   │ 融合/摩托 │  │  录音  │  │  记录   │
   │ +三级滤波│  │ +零漂抑制 │  │ G力/倾角 │  │ WAV   │  │  CSV    │
   └─────────┘  └─────────┘   └──────────┘  └────────┘  └─────────┘
        │            │             │
        └────────────┴─────────────┘
                     │ 全局数据结构（mpu6050_data / gps_data / fused_data / moto_data）
                     ▼
        ┌────────────────────────────────┐
        │  输出层：OLED显示 + 串口 + Web服务器 │
        └────────────────────────────────┘
```

## 为什么这样拆分模块

- **按物理传感器 + 按算法职责拆分**。`mpu6050`/`gps`/`audio`/`sd` 对应四个外设；`performance_analyzer` 是纯算法层（不碰硬件，只消费别人的全局数据），把"业务逻辑"和"驱动"分开。
- **模块间用全局数据结构通信，而不是函数参数传递**。`mpu6050_data`、`gps_data`、`fused_data`、`moto_data` 都是 `extern` 全局单例。这是嵌入式裸机常见做法：避免动态分配、零拷贝、任何模块随时能读最新值。代价是耦合度高、不可重入——但在单线程 `loop()` 里没有竞态问题。
- **没有用 FreeRTOS 任务**。所有"并发"靠 `loop()` 里基于 `millis()` 的时间片调度实现（见第三部分）。对这种数据流明确、无阻塞操作的场景，裸机分时比多任务更简单、更可控。

## 模块之间如何协作（数据链路）

```
MPU6050 (I²C0, 200Hz)
   │ 原始 a/g/temp
   ▼
[三级滤波] → mpu6050_data.*_Filtered
   │
   ├──────────────► fuseIMUSpeed()  ← GPS速度  ┐
   │                  (互补滤波)               │ 
   ▼                                          ▼
[performance_analyzer]                   gps_data.fused_speed
   calculateGForces() ← GPS速度差分(动态信心度)
   │
   ├─► fused_data (G力/状态/功率)
   └─► moto_data  (倾角/弯道/翘头)
   
GT-U7 GPS (UART2, 10Hz)
   │ NMEA → TinyGPS++ 解析
   ▼
[零漂抑制 三层] → gps_data.speed_kmh / 位置 / 卫星
   │
   ▼
[性能测试状态机] 0-60/0-100/制动测试

输出汇聚：
   gps_data + fused_data + moto_data + audio_data
        │
        ├─► OLED (5种显示模式, 20Hz)
        ├─► 串口 (简要/详细/混合)
        ├─► Web /data /moto /audio (JSON)
        └─► SD卡 CSV (10Hz, 18字段/行)
```

**每条链路的作用**：

| 链路 | 频率 | 作用 |
|---|---|---|
| IMU 采样 → 滤波 | 200 Hz | 高频采集，为 GPS-IMU 融合提供积分基础 |
| IMU → 速度融合 | 200 Hz | 用加速度积分填补 GPS 帧间空白，GPS 帧到来时拉回漂移 |
| GPS → 零漂抑制 | 10 Hz | 把脏速度变成能用的速度，喂给所有下游 |
| 融合 → G力/倾角 | 20 Hz | 算出展示用的 G 力、压弯角、弯道信息 |
| 汇聚 → 输出 | 20 Hz(显示) / 10 Hz(SD) | OLED/网页/串口/落盘 |

---

# 第三部分：项目运行流程

## 上电之后发生什么（初始化流程）

`setup()`（[main.cpp:713](src/main.cpp#L713)）的顺序是经过踩坑调整过的：

```
上电 / Reset
   │
   ▼
Serial.begin(115200)         ← 串口先起，方便看后续日志
   │
   ▼
pinMode(0, INPUT_PULLUP)     ← BOOT 按钮（GPIO0）做显示模式切换
   │
   ▼
双路 I²C 初始化
   I2C_MPU.begin(21,22,400k) ← I2C0 接 MPU6050
   I2C_OLED.begin(18,19,400k)← I2C1 接 OLED
   │
   ▼
scanI2CDevices()             ← 扫总线，确认 0x68/0x3C 在位（排错关键）
   │
   ▼
Init_mpu6050()               ← 设量程 ±8G/±500°/s，DLPF=94Hz，初始化滤波缓冲
   │
   ▼
initGPS()                    ← UART2 9600，发 PMTK 指令配 10Hz + 精简 NMEA + SBAS
   │
   ▼
initPerformanceAnalyzer()    ← 清零 fused_data
initMotorcycleMode()         ← 清零 moto_data，启用互补滤波
initAudioRecorder()          ← 配 ADC1_CH6(GPIO34)，读存储空间
   │
   ▼
[SD 卡初始化被注释跳过]       ← ⚠️ 当前为"测试模式"（见踩坑记录）
   │
   ▼
display.begin()              ← OLED 启动，显示开机画面 2 秒
   │
   ▼
SPIFFS.begin(true)           ← 挂载文件系统（网页 + 录音存这里）
   │
   ▼
WiFi.softAP("ESP32-IMU")     ← 开热点，固定 IP 192.168.4.1
   │
   ▼
server.on(...) + server.begin()  ← 注册 6 个 HTTP 路由
   │
   ▼
display_mode=1, displayQRCode()  ← 初始显示 WiFi 连接信息
```

## 主循环流程（任务调度）

`loop()`（[main.cpp:835](src/main.cpp#L835)）是整个系统的心跳，用 **`millis()` 时间片做软件多任务**，每个"任务"有自己的周期：

```
loop() {
  server.handleClient();        // ① Web 请求：每圈都处理（非阻塞）
  检测 BOOT 按钮 → 切换 display_mode (0~4)
  handleSerialCommands();       // ② 串口命令：每圈都查

  if (now - lastIMUTime >= 5ms)      → ReadMPU6050() + fuseIMUSpeed()   // 200Hz
  if (now - lastGPSTime >= 100ms)    → updateGPSData() + SD记录          // 10Hz
  updateAudioRecorder();             → processSample() + 自动录音检查     // 持续
  if (now - lastUpdateTime >= 50ms)  → updateFusedData() + OLED + 串口   // 20Hz
}
```

时间片分配（这是整个固件的调度核心）：

```
频率   周期    任务                       为什么是这个频率
─────  ─────  ─────────────────────────  ────────────────────────────
200Hz   5ms   IMU采样 + 速度积分融合       足够细的积分步长，抑制积分误差
 20Hz  50ms   数据融合 + OLED + 串口        人眼刷新够用，省CPU
 10Hz 100ms   GPS处理 + SD落盘             GT-U7 硬件就是 10Hz
持续    -     Web / 按钮 / 串口 / 录音采样   尽快响应，无阻塞
```

> **关键设计**：`loop()` 里**绝对没有 `delay()`（除了按钮防抖那一处 200ms）**。所有周期都用"时间戳差值比较"实现非阻塞，这样高频 IMU 不会被低频 GPS 拖慢——这是裸机分时调度能跑起来的前提。

## 中断流程

全项目**只有一处硬件中断**：录音采样定时器。

```
startRecording()
   │
   ▼
timerBegin(0, 80, true)        ← 定时器0，80分频 → 1MHz 计数
timerAlarmWrite(timer, 125)    ← 125 tick = 125µs = 8kHz
timerAttachInterrupt(onSampleTimer)
   │
   ▼ 每 125µs 触发
IRAM_ATTR onSampleTimer() {     ← 中断服务程序（放在 IRAM 加速）
   lastSample = adc1_get_raw()  ← 只做最少的事：读ADC + 置标志位
   sampleReady = true
}
   │
   ▼ loop() 中
processSample() {               ← 真正的处理放在主循环（ISR 外）
   if (!sampleReady) return
   8位量化 + 写缓冲 + 满512字节写SPIFFS
}
```

这是教科书式的 **ISR 最小化**：中断里只读一个 ADC 值、置标志，重活（量化、写 Flash）全部丢回主循环。原因——SPIFFS 写操作可能阻塞，绝不能在 ISR 里做。

## 通信流程

```
GPS:   GT-U7 ──NMEA(9600,UART2)──► gps.encode() 逐字节喂给 TinyGPS++
Web:   手机 ──WiFi──► 192.168.4.1 ──HTTP GET──► /data 返回 JSON ──► 网页轮询
配置:  ESP32 ──PMTK指令(UART)──► GT-U7  (配更新率/NMEA语句/SBAS)
```

## 状态机流程

项目里有**三个独立状态机**：

**1. 录音状态机**（[audio_recorder.cpp:296](src/audio_recorder.cpp#L296)）

```
RECORDING_IDLE/STOPPED ──速度≥5km/h──► RECORDING_ACTIVE
        ▲                                   │
        │                          速度<2km/h 持续5秒
        └───────────────────────────────────┘
   (也可手动 start/stop/pause/resume)
```

**2. 加速/制动测试状态机**（[gps_module.cpp:337](src/gps_module.cpp#L337)）

```
速度跨过 5km/h ──► 启动加速测试计时
   ├─ 跨 60km/h  → 记 0-60 时间
   ├─ 跨 100km/h → 记 0-100 时间
   └─ 跨 200km/h → 记 100-200，结束
速度≥95km/h ──► 启动制动测试 ──速度≤5km/h──► 记 100-0 时间
```

**3. SD 自动记录状态机**（[sd_logger.cpp:280](src/sd_logger.cpp#L280)）：速度 >5 km/h 开始记录，停车 30 秒后结束。逻辑与录音状态机平行。

---

# 第四部分：核心模块解析

## 模块一：MPU6050 IMU 驱动（`mpu6050.cpp`）

**职责**：读 6 轴数据，做振动滤波，算姿态角。

**设计思路**：用 Adafruit 库读原始值，但**不信任原始值**——叠加自己的三级软件滤波（见第五部分振动专题）。这是因为发动机振动让原始数据无法直接用。

**核心数据结构** `MPU6050_DATA`：同时保存"原始值"和"_Filtered 滤波值"两套。下游算 G 力用滤波值，算融合用原始值（积分对延迟敏感）。

**核心函数**：

| 函数 | 作用 |
|---|---|
| `Init_mpu6050()` | 量程 ±8G/±500°/s，DLPF=94Hz；失败时自动尝试 0x69 地址 |
| `ReadMPU6050()` | 读 a/g/temp → 滤波 → 算姿态角 |
| `FilterDataForVibration()` | 滑动平均(10点) + 一阶 IIR(α=0.1) 级联 |
| `CalculateAttitude()` | `atan2` 算 Roll/Pitch（⚠️ Yaw 硬编码为 0） |

**调用关系**：`main.loop()` 每 5ms 调 `ReadMPU6050()` → 内部链式调用滤波和姿态计算。

## 模块二：GPS 模块（`gps_module.cpp`）

**职责**：解析 NMEA、抑制零漂、GPS-IMU 速度融合、跑加速/制动测试状态机。这是**代码量最大、算法最密集的模块（756 行）**。

**设计思路**：GT-U7 数据脏，所以这个模块本质是"**清洗 + 融合**"流水线。配置阶段用 PMTK 指令把 GPS 调到 10Hz 并精简 NMEA（只留 RMC+GGA，否则 9600 波特率会溢出）。

**核心函数**：

| 函数 | 作用 |
|---|---|
| `initGPS()` | UART2 + PMTK 配置（10Hz/精简NMEA/SBAS/WAAS） |
| `updateGPSData()` | 逐字节喂 TinyGPS++ → 三层零漂抑制 → 信号监控自恢复 |
| `fuseIMUSpeed()` | GPS-IMU 互补滤波（核心算法，见第五部分） |
| `calibrateIMUBias()` | 静止时递推均值在线校准加速度偏置（O(1) 内存） |
| `interpolateSpeedAtTime()` | 速度阈值穿越线性插值，把 10Hz 的 100ms 不确定度降到 ~10-20ms |
| `calculateDistance()` | Haversine 球面距离（用于位置跳变检测、圈速） |
| `saveSessionData()/loadSessionData()` | 用 ArduinoJson 把成绩存进 SPIFFS |

## 模块三：性能分析器 + 摩托车模式（`performance_analyzer.cpp`）

**职责**：纯算法层。把 IMU + GPS 融合成 G 力，再衍生出摩托车专属指标。

**设计思路**：分两套数据 `fused_data`（通用 G 力/功率）和 `moto_data`（压弯/翘头/弯道）。

**核心函数**：

| 函数 | 作用 |
|---|---|
| `calculateGForces()` | 动态信心度加权融合 GPS 差分加速度与 IMU；静止/动态两套逻辑 |
| `calculateLeanAngle()` | **互补滤波**算压弯倾角（陀螺仪积分 + 加速度计修正，α=0.96） |
| `detectWheelieStoppie()` | 俯仰角 + 前向 G 力联合判断翘头/翘尾 |
| `analyzeCorner()` | 弯道进出检测 + 半径估算 `r = v²/(g·G_lat)` |
| `estimatePower()` | 用滚阻+风阻+加速力模型估算功率(kW) |

> ⚠️ 注意一个微妙点：`calculateLeanAngle()` 里 `Gyro_Z_Filtered` 被当作"横滚"、`Gyro_X_Filtered` 当作"偏航"，因为**传感器是垂直安装的**（X 轴朝下承重力）。坐标轴映射是按这个安装姿态硬编码的——换安装方向就要改。

## 模块四：录音模块（`audio_recorder.cpp`）

**职责**：定时器中断采集麦克风 ADC，存成 WAV 到 SPIFFS，骑行时自动录。

**核心数据结构**：`WAVHeader`（44 字节标准 WAV 头，先占位后回填 size）、`AUDIO_RECORDER_DATA`（含录音状态机字段）。

**设计思路**：8kHz / 8bit / 单声道——刻意压低规格省 SPIFFS 空间（SPIFFS 才几 MB）。中断只读 ADC，写盘在主循环。

## 模块五：SD 记录（`sd_logger.cpp`）

**职责**：把每个数据点（18 字段）写成 CSV 行到 SD 卡，方便事后用 Excel/Python 分析。

**设计思路**：用 **HSPI**（而非默认 VSPI），MISO 改到 GPIO25 避开 GPIO12 的启动冲突。每 100 个点 flush 一次（平衡掉电安全和写入性能）。

> ⚠️ **当前状态**：SD 初始化在 `setup()` 里被注释掉了（"测试模式"），但 `loop()` 里仍调用 `checkAutoLogging` 和 `logDataPoint`。因为 `sd_status.initialized=false`，这些调用会安全地早退，不写盘。这是一个**半成品功能**。

## 模块六：Web 服务器（在 `main.cpp` 内）

**职责**：WiFi 热点 + HTTP 服务，把数据 JSON 化推给手机网页。

**路由表**：

| 路由 | 作用 |
|---|---|
| `/` | 从 SPIFFS 返回 `index.html`（带 5 分钟缓存头） |
| `/data` | 主数据 JSON：温度/G力/角度/GPS/性能 |
| `/moto` | 摩托车模式 JSON：倾角/弯道/翘头/状态 |
| `/audio` | 录音状态 |
| `/audio/control` | 录音控制（start/stop/pause/list/...） |
| `/audio/download` | 下载 WAV 文件 |

**设计思路**：用 `sprintf` 手动拼 JSON 字符串（而非 ArduinoJson 序列化），固定大小 `char[]` 缓冲。原因——`/data` 是高频轮询接口，手拼 JSON 比构建 JsonDocument 快、内存可控。⚠️ 代价：缓冲区大小要算准，否则溢出（见踩坑记录）。

---

# 第五部分：技术知识提取

> 本部分只讲**项目里真的用到、且有"为什么"的**知识点，不抄教科书定义。

## 知识点 1：I²C（双路总线设计）

**为什么需要它**：MPU6050 和 OLED 都是 I²C 设备，要挂到 ESP32。

**项目中的实际应用**：项目用了**两个独立的 I²C 控制器**（ESP32 有两个硬件 I²C）：`TwoWire(0)` 给 MPU6050（GPIO21/22），`TwoWire(1)` 给 OLED（GPIO18/19）。

**为什么不共享一条总线**：共享其实完全可行（地址 0x68 和 0x3C 不冲突）。分两路的好处是：OLED 刷新（大量数据传输）不会阻塞 IMU 的高频读取，互不干扰。代价是多占两个 GPIO。

**常见误区/坑**：README 和 main.cpp 的注释里都写过"共享总线 GPIO21/22"，但实际代码是双路。**文档和代码已脱节**（见踩坑记录）——以代码为准。

**调试方法**：`scanI2CDevices()` 分别扫两条总线，打印找到的地址。这是 I²C 排错第一招。

## 知识点 2：振动环境下的三级级联滤波（本项目灵魂）

**它解决什么问题**：发动机怠速 20~50 Hz 振动叠加到加速度上，G 力跳变、姿态角抖 ±5°。

**工作原理 — 三级级联**：

```
原始ADC
   │
① 硬件 DLPF (MPU6050内置数字低通)
   setFilterBandwidth(94Hz)        ← 砍掉 >94Hz，但保留快速动作响应
   │
② 滑动平均 FIR (窗口10点 @200Hz)
   等效时间窗50ms，截止≈10Hz        ← 无相位累积，但延迟25ms
   │
③ 一阶 IIR 低通 (α=0.1)
   y=αx+(1-α)y_prev，截止≈3.5Hz     ← O(1)内存，进一步平滑
   │
最终 *_Filtered (等效截止 3~5Hz，振动衰减>12dB)
```

**为什么这么设计（关键权衡）**：

- 为什么 DLPF 选 94Hz 而不是 5Hz？因为陀螺仪要追摩托快速转向（可达 90°/s），截止太低动态响应变迟钝。硬件留宽点，靠软件补。
- 为什么 IIR 不用 FIR？MCU 上 IIR 只存一个上次输出值（O(1)），FIR 要存整个窗口。加速度测量不做频谱分析，对相位延迟不敏感，IIR 划算。
- α=0.1 怎么定的？公式 `fc ≈ α·fs/(2π) ≈ 0.1×200/6.28 ≈ 3.2Hz`，再用串口波形观察微调。

**量化效果**：静止 G 力噪声 ±0.15g → ±0.01g；姿态抖动 ±5° → ±0.5°；代价是 25~50ms 延迟（可接受）。

## 知识点 3：互补滤波（Complementary Filter）

**为什么需要它**：纯加速度计算姿态，在动态（加速/振动）时会把"线加速度"误当"重力"，Pitch 虚假偏 5~10°；纯陀螺仪积分会漂移。

**工作原理**：`θ = α·(θ_prev + ω·dt) + (1-α)·θ_accel`。陀螺仪管高频（快、短期准），加速度计管低频（慢、长期准），互补。

**项目中的实际应用**：摩托车模式的压弯倾角（[performance_analyzer.cpp:524](src/performance_analyzer.cpp#L524)）用 α=0.96 实现。注意**姿态角主路径（mpu6050.cpp）没用互补滤波**，是已知缺口——G 力测量优先级更高，姿态是次要功能。

**常见误区**：α 不是越大越好。α=0.98 时间常数 τ=α·dt/(1-α)≈0.25s，即 0.25s 内加速度计才能把陀螺拉回——这个"拉回速度"要和振动强度匹配着调。

## 知识点 4：GPS-IMU 速度融合 + 动态信心度

**为什么需要它**：GPS 准但慢（10Hz、低速噪声大）；IMU 快（200Hz）但积分会漂。要互补。

**两个融合点**：

1. **速度融合**（`fuseIMUSpeed`，互补滤波）：200Hz 用加速度积分填 GPS 帧间空白，每个 GPS 帧（~100ms）到来时按 `GPS_CORRECTION_RATE=0.1` 拉回 10% 漂移。
2. **G 力融合**（`calculateGForces`，动态信心度）：不是固定权重，而是按实时信号质量算 `imu_confidence = gps稳定性 × 信号质量`，动态分配 GPS 差分加速度和 IMU 的权重。

**为什么不用卡尔曼滤波**：

| | 本项目(互补/自适应IIR) | 卡尔曼(EKF) |
|-|---|---|
| 计算量 | 极低，适合 ESP32 | 矩阵运算重 |
| 调参 | 直观(α、死区) | 要建模 Q/R 协方差 |
| 选择 | ✅ | 改进方向 |

**常见误区**：用 GPS 的速度，**要用 Doppler 测速而非位置差分**。TinyGPS++ 的 `gps.speed.kmph()` 解析的 RMC 速度本身就是 Doppler 速度，精度比位置差分高 ~10 倍。项目用对了。

## 知识点 5：GPS 零漂抑制（三层）

GT-U7 静止时输出 0.5~2 km/h 假速度。三层压制：

```
层1：20点滑动平均 + 标准差分析
     std_dev<0.2 且 avg<动态阈值 → 判定稳定
层2：自适应IIR (按速度段调α)
     <0.5km/h→α=0.92强抑零漂；>4km/h→α=0.35快响应不耽误计时
层3：最终死区
     好信号(≥8星,HDOP<1.0)阈值0.8km/h，否则1.2km/h，以下归零
```

判定静止需持续 1.5 秒（15 次 ×100ms）。这是个**精度 vs 响应**的反复权衡——压太狠会让 0-100 测试起步判断变慢。

## 知识点 6：ADC + 定时器中断采样（录音）

**为什么用 ADC1 的 GPIO34**：ESP32 的 **ADC2 与 WiFi 冲突**（WiFi 开启时 ADC2 不可用）。本项目全程开着 WiFi 热点，所以麦克风必须接 ADC1。GPIO34 是纯输入引脚（无上拉/输出），最适合做模拟输入。这是个**容易踩的硬件坑，项目避开了**。

**采样机制**：硬件定时器 80 分频得 1MHz，125 tick=125µs=8kHz 触发中断。ISR 只 `adc1_get_raw` + 置标志。

## 知识点 7：WAV 文件格式

44 字节 RIFF 头 + PCM 裸数据。录音时先写占位头（size=0），结束时 `seek(0)` 回填真实的 `dataSize`/`fileSize`。8bit 无符号 PCM，中心在 128。

## 知识点 8：SPIFFS vs SD 卡

| | SPIFFS（板载Flash） | SD卡（外接） |
|-|---|---|
| 容量 | ~1-3MB | GB级 |
| 用途 | 网页文件 + 录音(小) | 行车CSV(大量) |
| 接口 | 内部 | SPI(HSPI) |
| 项目状态 | 在用 | 半成品(初始化被注释) |

## 知识点 9：PMTK / NMEA 协议

GPS 用 NMEA 文本协议输出（`$GPRMC`/`$GPGGA`），用 PMTK 专有指令配置。项目发的关键指令：

- `$PMTK220,100*2F`：更新率 100ms（10Hz）
- `$PMTK314,...`：只输出 RMC+GGA（精简，防 9600 波特率溢出）
- `$PMTK313,1*2E`：启用 SBAS
- `$PMTK301,2*2E`：DGPS 用 WAAS

> ⚠️ 注意文档间不一致：`GT-U7_ULTIMATE_OPTIMIZATION.md` 说要把波特率提到 38400、用多星座，但 `initGPS()` 实际代码仍是 9600 + 10Hz。优化文档是"设想"，代码是"现状"。

## 知识点 10：HTTP / WiFi SoftAP

ESP32 开热点（`WiFi.softAP`），固定 IP 192.168.4.1，跑 `WebServer`。网页用 JS 轮询 `/data` 拿 JSON。`/data` 返回 `no-cache`（实时数据），`/`（HTML）返回 `max-age=300`（静态可缓存）。这种缓存策略区分对了。

---

# 第六部分：设计决策分析

### 决策 1：裸机分时调度，而非 FreeRTOS 任务

- **背景**：要"同时"跑 200Hz IMU、10Hz GPS、20Hz 显示、持续录音和 Web。
- **方案**：`loop()` 里用 `millis()` 时间戳差比较做软件分时，全程无 `delay()`。
- **优点**：简单、可控、无竞态（单线程）、无任务切换开销。
- **缺点**：任一环节若阻塞会拖垮全局；CPU 没用上第二个核。
- **替代**：FreeRTOS 多任务 + 队列（ESP32 底层就是 FreeRTOS）。
- **为什么这么选**：数据流明确、无长阻塞操作，裸机分时足够且心智负担小。

### 决策 2：全局数据结构通信，而非消息传递

- **优点**：零拷贝、无动态分配、任意模块读最新值、实现极简。
- **缺点**：强耦合、不可重入、多线程下会有竞态（但本项目单线程，无此问题）。
- **为什么**：嵌入式裸机标准做法，内存确定性 > 解耦优雅。

### 决策 3：环形缓冲区做滑动平均

- **背景**：振动滤波要算窗口均值。
- **方案**：定长数组 + 取模索引 `(idx+1)%N`，配 `buffer_full` 标志处理冷启动。
- **优点**：O(1) 内存、无动态分配、写覆盖最旧。
- **为什么**：MCU 上定长环形缓冲是滑动窗口的标准实现。

### 决策 4：互补滤波而非卡尔曼

见第五部分知识点 4 的对比表。一句话：**ESP32 算力和调参成本下，互补/自适应 IIR 性价比远高于 EKF**，卡尔曼列为改进方向。

### 决策 5：双 I²C 总线

- **优点**：OLED 刷新不阻塞 IMU 读取。
- **缺点**：多占 2 个 GPIO。
- **替代**：单总线共享（地址不冲突，可行）。
- **为什么**：高频 IMU 对总线占用敏感，隔离更稳。

### 决策 6：手拼 JSON 而非序列化库

- **背景**：`/data` 高频轮询。
- **优点**：`sprintf` 比构建 JsonDocument 快、固定 `char[]` 内存可控。
- **缺点**：缓冲区大小要手算，易溢出；可维护性差。
- **替代**：ArduinoJson（项目在低频的 `saveSessionData` 里用了它）。
- **为什么**：热路径选性能，冷路径选可维护性——**两种都用，按场景分**。

### 决策 7：SD 卡用 HSPI + MISO 改 GPIO25

- **背景**：GPIO12 是 ESP32 的 strapping 引脚（启动时拉高会导致 flash 电压判断错误，启动失败）。
- **方案**：SD 用 HSPI（独立于默认 VSPI），并把 MISO 从 GPIO12 挪到 GPIO25。
- **为什么**：避开 strapping 引脚的启动冲突——这是 ESP32 经典硬件坑。

### 决策 8：录音 8kHz/8bit

- **背景**：SPIFFS 只有几 MB。
- **方案**：刻意压低音质规格。8kHz×8bit×单声道 = 8KB/s，5 分钟约 2.4MB。
- **为什么**：录的是"骑行环境音/排气声"，不需要高保真，容量优先。

---

# 第七部分：调试与踩坑记录

> 以下问题部分来自代码痕迹推断，部分已记录在 [INTERVIEW_NOTES.md](INTERVIEW_NOTES.md)。

### 坑 1：IMU 被发动机震动淹没 ★已解决

- **问题**：怠速时 G 力跳变、姿态抖 ±5°。
- **原因**：MPU6050 DLPF 默认 260Hz，等于没滤，20~50Hz 振动全透传。
- **定位**：串口打印原始加速度波形，看到高频毛刺。
- **解决**：三级级联滤波（硬件 94Hz + 滑动平均 + IIR），等效截止 3~5Hz。
- **经验**：传感器原始值不可全信，先看噪声频谱再定滤波策略。

### 坑 2：GPS 静止零漂 ★已解决

- **问题**：停车时显示"车在缓慢移动"，0-100 测试起步判断错。
- **原因**：GT-U7 多路径反射 + 卫星几何误差，静止输出 0.5~2km/h。
- **解决**：三层零漂抑制（滑动平均+标准差 / 自适应IIR / 死区）。
- **经验**：死区阈值要随信号质量动态变，固定阈值要么压不住要么误杀低速。

### 坑 3：IMU 加速度偏置导致积分漂移 ★部分解决

- **问题**：积分求速度漂移大（1m/s² 偏置 ×10s = 10m/s 误差）。
- **原因**：MPU6050 出厂零偏 ±50~150mg。
- **解决**：① 手动测量硬编码 `-0.47/+0.5/-0.48`（performance_analyzer）；② GPS 判静止时递推均值在线校准（gps_module）。
- **遗留**：温漂未补偿；手动硬编码值换硬件就失效。

### 坑 4：GPS 位置跳变 ★已解决

- **问题**：隧道出口/高楼后重定位，位置瞬跳数百米，距离统计飙升。
- **解决**：Haversine 算帧间距离，>1000m（即 >1km/帧，F1 也才 83m/s）直接拒绝。

### 坑 5：GPIO12 启动冲突（SD 卡）★已规避

- **问题**：SD 卡 MISO 默认接 GPIO12 会导致 ESP32 启动失败。
- **原因**：GPIO12 是 strapping 引脚，启动时电平影响 flash 电压选择。
- **解决**：MISO 挪到 GPIO25，用 HSPI。

### 坑 6：ADC2 与 WiFi 冲突（麦克风）★已规避

- **问题**：WiFi 开启时 ADC2 引脚读不到值。
- **解决**：麦克风接 ADC1 的 GPIO34（纯输入引脚）。

### 坑 7：9600 波特率下 10Hz NMEA 溢出 ★已规避

- **问题**：10Hz 全量 NMEA 语句在 9600 波特率下数据溢出、丢帧。
- **解决**：PMTK314 只保留 RMC+GGA 两条语句。

### 坑 8：文档与代码脱节 ⚠️ 待修

- README 写"共享 I²C 总线 GPIO21/19"，实际代码是**双路** GPIO21/22 + GPIO18/19。
- README 的 `lib_deps` 写 `electroniccats/MPU6050`，实际 `platformio.ini` 用 `adafruit/Adafruit MPU6050`。
- `GT-U7_ULTIMATE` 说 38400 波特率/多星座，代码实际 9600/10Hz。
- **经验**：文档要么删要么同步，过时文档比没文档更误导未来的自己。

### 坑 9：SD 记录是半成品 ⚠️ 待完成

- `setup()` 里 `initSDCard()` 被注释（"测试模式"），但 `loop()` 仍调记录函数。
- 因 `initialized=false` 安全早退，不写盘。**功能未真正启用。**

### 潜在风险（代码审查角度，未必触发）

- **JSON 缓冲区**：`/data` 用 `char[750]`、`/moto` 用 `char[600]` 手拼。字段多、`%.8f` 经纬度长，**接近上限，未来加字段易溢出**。建议加 `snprintf` 长度保护。
- **静止校准的 static 局部变量**：`calculateGForces` 里 `gravity_bias_x` 等用 `static` 且只累加不重置，长时间运行逻辑可能僵化（一旦 `calibration_samples` 满 50 就固定）。

---

# 第八部分：工程实践总结

### 做得好的地方

- **代码组织**：按外设/算法清晰分模块，头文件声明 + cpp 实现规整，函数注释到位。
- **接口设计**：全局数据结构单例 + `extern` 声明，模块边界清楚。
- **错误处理**：初始化大量带降级（MPU6050 试 0x68 失败试 0x69；OLED 失败仍继续；GPS 信号丢失自动热重启恢复）。这种"**失败不死机、打印原因、降级运行**"的思路很成熟。
- **可观测性**：串口三种打印模式（简要/详细/混合），可运行时切换；I²C 扫描、原始 NMEA 打印——调试钩子完备。
- **构建系统**：PlatformIO，依赖锁版本（`@^x.y.z`），`monitor_filters = esp32_exception_decoder` 自动解崩溃栈。
- **配置管理**：引脚、阈值、滤波系数都用 `#define`/`const` 集中在文件头，调参不用翻代码。
- **场景化分层**：热路径手拼 JSON 求性能，冷路径用 ArduinoJson 求可维护——分得清。

### 可以改进的地方

- **文档与代码同步**：README/优化文档已严重脱节（坑 8）。
- **魔法数字**：`-0.47/+0.5/-0.48` 这类校准偏置散落在多个文件、重复出现，应抽成统一配置或自动校准。
- **缓冲区安全**：手拼 JSON 用 `sprintf` 无长度保护，应换 `snprintf`。
- **SD 功能收尾**：要么启用要么删，别留半成品调用。
- **测试策略**：目前**无任何自动化测试**（`test/` 只有空 README）。IMU 滤波、Haversine、零漂判定这些纯函数其实很适合做单元测试（host 端跑）。
- **持续集成**：无 CI。可加 PlatformIO 的 `pio ci` 在 push 时编译检查。

---

# 第九部分：项目复盘

### 最大的亮点

把"算法"当成项目主角，而不是"点亮外设"。**三级滤波 + GPS-IMU 融合 + 动态信心度**这套组合，把 30 元 GPS 的静止零漂从 ±2.5 压到 ±0.8 km/h（与专业设备差距从 20 倍缩到 4 倍，成本差 67 倍）。这是真正有技术含量、能讲清"为什么"的部分。

### 最大的难点

**在脏数据上做可信的实时融合**。GPS 慢且低速噪声大，IMU 快但漂，两者都不可单独信任。难点不在写公式，而在：什么时候信谁、信多少（动态信心度）、怎么不让滤波延迟拖垮测试计时（自适应 α）。这些都是反复调参 + 串口看波形磨出来的。

### 学到的知识

- 滤波器选型的工程权衡（FIR vs IIR、硬件 vs 软件、截止频率 vs 响应延迟）。
- 互补滤波 / 传感器融合的实战（而非课本公式）。
- ESP32 硬件陷阱（strapping 引脚、ADC2/WiFi 冲突）。
- 裸机分时调度的设计模式（millis 时间片、ISR 最小化）。
- GPS NMEA/PMTK 协议、Doppler 测速 vs 位置差分。

### 如果重新设计会怎么做

- **传感器融合上 1D 卡尔曼**：只融合纵向速度，状态量少，ESP32 扛得住，比手调信心度更系统。
- **校准全自动化**：删掉所有硬编码偏置，统一走静止在线校准 + 温度补偿。
- **姿态主路径加互补滤波**：解决加速时 Pitch 虚假偏移。
- **抽配置层**：所有引脚/阈值/系数集中到一个 `config.h`。
- **加 host 端单元测试**：纯算法函数脱离硬件测。
- **用 FreeRTOS 双核**：Web/录音放一个核，传感器融合放另一个核，物理隔离。

### 下一步可以扩展什么

- 升级 GPS 到 NEO-M9N（[GPS_UPGRADE_ANALYSIS.md](GPS_UPGRADE_ANALYSIS.md) 已做选型，150 元换 5-8 倍精度）。
- 真正启用 SD 记录 + 配套 Python 分析脚本（CSV 已就绪）。
- 加磁力计（QMC5883L）补全 Yaw / 转向感知。
- 大倾角重力分量补偿：`a_真 = a_测 - g·sin(Roll)`。
- 网页端轨迹回放 / 成绩对比。

---

# 第十部分：个人知识地图

> 由本工作区内容沉淀出的长期知识体系。带 ✅ 的是本项目实际用过的。

```
Embedded Knowledge Map
│
├── MCU 基础 (ESP32)
│   ├── GPIO ✅           (BOOT按钮输入、CS控制)
│   ├── ADC ✅            (ADC1_CH6麦克风；ADC2/WiFi冲突坑)
│   ├── Timer + 中断 ✅    (8kHz采样定时器、IRAM_ATTR、ISR最小化)
│   ├── Strapping引脚 ✅   (GPIO12启动冲突坑)
│   └── 双核 (未用，改进方向)
│
├── 通信协议
│   ├── I²C ✅            (双路总线、设备扫描、400kHz、地址0x68/0x3C)
│   ├── UART ✅           (GPS 9600、HardwareSerial2)
│   ├── SPI ✅            (SD卡 HSPI、避VSPI冲突)
│   ├── HTTP/WiFi ✅      (SoftAP热点、WebServer、JSON、缓存策略)
│   └── NMEA/PMTK ✅      (GPS文本协议、Doppler测速、配置指令)
│
├── 传感器与信号处理 ★本项目核心
│   ├── IMU (MPU6050) ✅  (量程/DLPF配置、6轴)
│   ├── 滤波器 ✅
│   │   ├── 硬件DLPF ✅
│   │   ├── 滑动平均(FIR) ✅
│   │   ├── 一阶IIR/EMA ✅
│   │   └── 卡尔曼 (未用，改进方向)
│   ├── 传感器融合 ✅
│   │   ├── 互补滤波 ✅    (倾角、α=0.96)
│   │   ├── 动态信心度加权 ✅
│   │   └── 阈值穿越插值 ✅
│   ├── 姿态解算 ✅       (atan2算Roll/Pitch；Yaw缺磁力计)
│   └── 偏置校准 ✅       (递推均值O(1)在线校准)
│
├── GPS / 定位
│   ├── NMEA解析 ✅       (TinyGPS++)
│   ├── 零漂抑制 ✅       (三层：均值+自适应IIR+死区)
│   ├── Haversine距离 ✅
│   ├── HDOP/卫星质量 ✅
│   └── SBAS/DGPS增强 ✅
│
├── 数据存储
│   ├── SPIFFS ✅         (网页、录音、会话JSON)
│   ├── SD卡 CSV ⚠️       (半成品)
│   ├── WAV格式 ✅
│   └── ArduinoJson ✅
│
├── 系统架构 / 软件工程
│   ├── 裸机分时调度 ✅    (millis时间片、无delay)
│   ├── 全局单例通信 ✅
│   ├── 环形缓冲区 ✅
│   ├── 状态机 ✅         (录音/测试/SD记录 三个)
│   ├── 错误降级处理 ✅
│   └── RTOS任务/队列 (未用，改进方向)
│
├── 车辆动力学 (应用领域)
│   ├── G力 (纵向/横向/垂直) ✅
│   ├── 压弯倾角 ✅
│   ├── 弯道半径 r=v²/(gG) ✅
│   ├── 翘头/翘尾检测 ✅
│   ├── 加速/制动测试 ✅
│   └── 功率估算(阻力模型) ✅
│
└── 机械 / 工具链
    ├── PlatformIO ✅
    ├── OpenSCAD参数化建模 ✅ (cad/外壳)
    └── Gerber/PCB ✅
```

---

*本知识库由对工作区源码、文档、配置的递归分析生成。凡代码无法确定之处均已标注；未发现编造的功能或设计。若代码变更，请同步更新本文档——过时的笔记比没有笔记更危险。*

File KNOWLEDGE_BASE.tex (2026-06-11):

% !TEX program = xelatex
% ESP32 车载性能仪 —— 个人技术知识库
% 编译：xelatex KNOWLEDGE_BASE.tex （需运行两次以生成目录/书签）
% 依赖等宽字体 Consolas（Windows 自带，含制表符字形，用于 ASCII 架构图）
\documentclass[UTF8,11pt,a4paper]{ctexart}

\usepackage[top=2cm,bottom=2cm,left=2cm,right=2cm]{geometry}
\usepackage{amsmath,amssymb}
\usepackage{xcolor}
\usepackage{enumitem}
\usepackage{booktabs}
\usepackage{tabularx,array,longtable}
\usepackage{fancyvrb}
\usepackage{tcolorbox}
\tcbuselibrary{skins,breakable}
\usepackage{underscore} % 让正文中的 _ 直接显示，省去大量转义
\usepackage{fancyhdr}
\usepackage{titlesec}
\usepackage[colorlinks=true,linkcolor=teal!70!black,urlcolor=blue!60!black,
            bookmarksnumbered=true]{hyperref}

% 等宽字体（含 Unicode 制表符，用于 ASCII 图）
\setmonofont{Consolas}

% 页眉页脚
\pagestyle{fancy}\fancyhf{}
\fancyhead[L]{\small\color{gray} ESP32 车载性能仪 · 技术知识库}
\fancyhead[R]{\small\color{gray}\leftmark}
\fancyfoot[C]{\small\thepage}
\renewcommand{\headrulewidth}{0.3pt}

% 章节样式
\titleformat{\section}{\Large\bfseries\color{teal!70!black}}
  {\thesection}{0.6em}{}[{\color{teal!70!black}\titlerule[1.2pt]}]
\titlespacing{\section}{0pt}{14pt}{6pt}
\titleformat{\subsection}{\large\bfseries\color{teal!60!black}}{\thesubsection}{0.5em}{}
\titlespacing{\subsection}{0pt}{8pt}{3pt}
\titleformat{\subsubsection}{\normalsize\bfseries\color{teal!55!black}}{}{0pt}{}
\titlespacing{\subsubsection}{0pt}{6pt}{2pt}

\setlist{topsep=2pt,itemsep=1pt,leftmargin=1.6em}

% 强调框 / 警告框
\newtcolorbox{say}[1]{enhanced,breakable,
  colback=teal!5,colframe=teal!60!black,arc=1.2mm,boxrule=0.6pt,
  left=6pt,right=6pt,top=4pt,bottom=4pt,
  fonttitle=\bfseries\color{white},colbacktitle=teal!60!black,title={#1}}
\newtcolorbox{warn}[1]{enhanced,breakable,
  colback=red!4,colframe=red!55!black,arc=1.2mm,boxrule=0.6pt,
  left=6pt,right=6pt,top=4pt,bottom=4pt,
  fonttitle=\bfseries\color{white},colbacktitle=red!55!black,title={#1}}

% ASCII 架构图环境（等宽 + 浅色边框）
\DefineVerbatimEnvironment{ascii}{Verbatim}%
  {fontsize=\footnotesize,frame=single,framesep=4pt,rulecolor=\color{teal!40},
   commandchars=\\\{\}}

\renewcommand{\arraystretch}{1.25}

\title{\textbf{\Huge Embedded Knowledge Base}\\[6pt]
       \Large ESP32 车载性能仪 · 个人技术知识库}
\author{工作区：\texttt{e:\textbackslash esp32\textbackslash esp32-imu}}
\date{生成日期：2026-06-10}

\begin{document}
\maketitle

\begin{say}{这份文档是写给半年后的自己的}
重新打开这个仓库时，\textbf{只读这一份文档}就能想起来：当时做了什么、为什么这么设计、
数据怎么流、核心技术是什么、踩过哪些坑。
\end{say}

\vspace{4pt}
\noindent\textbf{关于工作区范围：}当前工作区只有\textbf{一个固件项目}（\texttt{esp32-imu}），
外加随附文档（GPS 升级分析、面试归档、接线图、构建指南）和 \texttt{cad/} 里的 OpenSCAD 外壳模型
与 Gerber 压缩包。本文档据此组织。

\tableofcontents
\newpage

% ================================================================
\section{项目全景图}
% ================================================================

\subsection{项目名称：ESP32 车载性能仪（“Dragy 风格” Performance Box）}

\subsubsection{项目背景}
想用便宜的开源硬件，自己做一台\textbf{摩托车/汽车的车载性能记录仪}，对标商业产品 Dragy
（一种 GPS 性能盒子，专测 0--100 km/h、0--400m、刹车距离）。商业 Dragy 要 2000 元，
而一套 ESP32 + MPU6050 + GT-U7 GPS 的料才几十块。

核心挑战不是“读个传感器显示出来”，而是：
\begin{itemize}
  \item \textbf{传感器装在摩托车上，发动机振动极烈}，MPU6050 原始数据被 20\textasciitilde 50 Hz 机械振动淹没。
  \item \textbf{GT-U7 是 30 元级老 GPS 模块}，静止零漂 ±2 km/h，10 Hz 更新，低速段噪声比信号还大。
  \item 要在这种“脏数据”上算出能看的 G 力、倾角、加速测试成绩。
\end{itemize}
项目真正的价值在于\textbf{用软件算法把廉价硬件的潜力榨干}。

\subsubsection{项目目标}
\begin{enumerate}
  \item 实时显示\textbf{速度 / G 力（纵向、横向、垂直）/ 压弯倾角 / 加速测试成绩}。
  \item 自动识别“开始骑行 / 停车”，自动开始/停止数据记录与录音。
  \item 通过 \textbf{WiFi 热点 + 网页}把数据推到手机浏览器（无需 App）。
  \item 专门的\textbf{摩托车模式}：压弯角度、翘头/翘尾检测、弯道半径估算。
  \item 数据落盘（SPIFFS 录音 / SD 卡 CSV 行车数据）。
\end{enumerate}

\subsubsection{技术栈}
\begin{center}\small
\begin{tabularx}{\linewidth}{@{}lX@{}}
\toprule
\textbf{维度} & \textbf{选型} \\
\midrule
芯片 & ESP32-WROOM-32（双核 240MHz，板载 WiFi） \\
框架 & Arduino Framework（基于 ESP-IDF） \\
操作系统 & 无 RTOS 显式使用，裸机 \texttt{loop()} + 软件分时调度（底层是 FreeRTOS，但未直接用任务/队列） \\
构建系统 & PlatformIO（\texttt{platformio.ini}） \\
语言 & C++（Arduino 风格）+ 前端 HTML/CSS/JS（\texttt{data/index.html}） \\
传感器 & MPU6050（6 轴 IMU）、GT-U7（GPS，UBX-M8030 芯片）、模拟麦克风 \\
显示 & SSD1306 OLED 128×64（I²C） \\
协议 & I²C（双路）、UART（GPS）、SPI（SD 卡 HSPI）、HTTP（Web）、NMEA/PMTK \\
关键库 & Adafruit MPU6050 / SSD1306 / GFX、TinyGPSPlus、ArduinoJson \\
机械 & OpenSCAD 参数化外壳（\texttt{cad/}） \\
\bottomrule
\end{tabularx}
\end{center}

\subsubsection{项目一句话总结（适合放简历）}
\begin{say}{简历版}
基于 ESP32 + MPU6050 + GT-U7 GPS 自研车载性能仪，通过\textbf{三级级联滤波}抑制发动机振动、
\textbf{GPS-IMU 互补滤波融合}与\textbf{动态信心度加权}算法，将 30 元 GPS 模块的静止零漂
从 ±2.5 km/h 压到 ±0.8 km/h；实现 0--100 km/h 加速测试、压弯倾角/翘头检测，
并通过 WiFi 热点 + 网页实时可视化。
\end{say}

\subsubsection{项目目录结构分析}
\begin{ascii}
esp32-imu/
├── platformio.ini              # PlatformIO 工程配置：板型、库依赖、串口
├── src/                        # 固件源码（核心）
│   ├── main.cpp                # 主程序：setup/loop、Web服务器、OLED显示、调度
│   ├── mpu6050.{h,cpp}         # IMU驱动 + 三级振动滤波 + 姿态角计算
│   ├── gps_module.{h,cpp}      # GPS解析 + 零漂抑制 + GPS-IMU融合 + 性能测试
│   ├── performance_analyzer.*  # G力计算 + 摩托车模式（倾角/弯道/翘头）
│   ├── audio_recorder.{h,cpp}  # ADC麦克风录音 → WAV，自动骑行触发
│   └── sd_logger.{h,cpp}       # SD卡 CSV 行车数据记录（HSPI）
├── data/index.html             # SPIFFS 网页前端（手机端仪表盘）
├── cad/                        # 机械外壳（OpenSCAD 参数化模型 + STL）
├── interview/                  # LaTeX 版面试材料（main.tex/pdf）
├── INTERVIEW_NOTES.md          # [*] 面试技术答辩归档：踩坑/原理/量化效果（精华）
├── GPS_UPGRADE_ANALYSIS.md     # GPS 硬件升级对比分析
├── GT-U7_ULTIMATE_OPTIMIZATION.md  # GT-U7 软件压榨优化记录
├── wiring_diagram.txt          # 接线图
├── BUILD_GUIDE.md              # 编译/上传/串口/排错指南
└── README.md                   # 原始 README（[!] 已与代码脱节，见踩坑记录）
\end{ascii}
\noindent\textbf{重点：}真正的“知识密度”集中在 \texttt{src/} 和 \texttt{INTERVIEW\_NOTES.md}。

% ================================================================
\section{系统架构设计}
% ================================================================

\subsection{系统由哪些模块组成}
固件按“传感器采集 → 数据融合 → 输出”分层，五个功能模块围绕 \texttt{main.cpp} 的调度器协作：

\begin{ascii}
┌──────────────────────────────────────────────────────────────┐
│                       main.cpp (调度器)                        │
│   软件分时循环 loop()：按 millis() 时间片驱动各模块            │
└──────────────────────────────────────────────────────────────┘
      │           │            │           │           │
  ┌───▼───┐  ┌────▼───┐   ┌────▼────┐  ┌───▼───┐  ┌────▼───┐
  │mpu6050│  │  gps   │   │perf_ana │  │ audio │  │   sd   │
  │IMU驱动 │  │GPS解析  │   │融合/摩托 │  │ 录音  │  │  记录  │
  │+三级滤波│ │+零漂抑制 │  │G力/倾角 │  │ WAV  │  │  CSV   │
  └───────┘  └────────┘   └─────────┘  └───────┘  └────────┘
      │           │            │
      └───────────┴────────────┘
                  │ 全局数据结构 (mpu6050_data / gps_data / fused_data / moto_data)
                  ▼
        ┌────────────────────────────────┐
        │ 输出层：OLED显示 + 串口 + Web服务器 │
        └────────────────────────────────┘
\end{ascii}

\subsection{为什么这样拆分模块}
\begin{itemize}
  \item \textbf{按物理传感器 + 按算法职责拆分}。\texttt{mpu6050}/\texttt{gps}/\texttt{audio}/\texttt{sd}
        对应四个外设；\texttt{performance\_analyzer} 是纯算法层（不碰硬件，只消费别人的全局数据），
        把“业务逻辑”和“驱动”分开。
  \item \textbf{模块间用全局数据结构通信}。\texttt{mpu6050\_data}、\texttt{gps\_data}、\texttt{fused\_data}、
        \texttt{moto\_data} 都是 \texttt{extern} 全局单例。这是嵌入式裸机常见做法：避免动态分配、零拷贝、
        任何模块随时能读最新值。代价是耦合度高、不可重入——但单线程 \texttt{loop()} 里没有竞态。
  \item \textbf{没有用 FreeRTOS 任务}。所有“并发”靠 \texttt{loop()} 里基于 \texttt{millis()} 的时间片调度
        实现。对这种数据流明确、无阻塞操作的场景，裸机分时比多任务更简单、更可控。
\end{itemize}

\subsection{模块之间如何协作（数据链路）}
\begin{ascii}
MPU6050 (I²C0, 200Hz) ──原始 a/g/temp──► [三级滤波] ──► mpu6050_data.*_Filtered
                                                          │
                                  ┌───────────────────────┤
                                  ▼                        ▼
              fuseIMUSpeed() ◄── GPS速度          [performance_analyzer]
              (互补滤波)                           calculateGForces() ◄ GPS速度差分(信心度)
                  │                                    │
                  ▼                                    ├─► fused_data (G力/状态/功率)
          gps_data.fused_speed                         └─► moto_data  (倾角/弯道/翘头)

GT-U7 GPS (UART2,10Hz) ─NMEA─► TinyGPS++ ─► [零漂抑制 三层] ─► gps_data.speed_kmh / 位置 / 卫星
                                                              │
                                                              ▼  [性能测试状态机] 0-60/0-100/制动

输出汇聚：gps_data + fused_data + moto_data + audio_data
   ├─► OLED (5种显示模式, 20Hz)      ├─► Web /data /moto /audio (JSON)
   └─► 串口 (简要/详细/混合)          └─► SD卡 CSV (10Hz, 18字段/行)
\end{ascii}

\begin{center}\small
\begin{tabularx}{\linewidth}{@{}llX@{}}
\toprule
\textbf{链路} & \textbf{频率} & \textbf{作用} \\
\midrule
IMU 采样 → 滤波 & 200 Hz & 高频采集，为 GPS-IMU 融合提供积分基础 \\
IMU → 速度融合 & 200 Hz & 用加速度积分填补 GPS 帧间空白，GPS 帧到来时拉回漂移 \\
GPS → 零漂抑制 & 10 Hz & 把脏速度变成能用的速度，喂给所有下游 \\
融合 → G力/倾角 & 20 Hz & 算出展示用的 G 力、压弯角、弯道信息 \\
汇聚 → 输出 & 20/10 Hz & OLED/网页/串口（20Hz）、落盘（10Hz） \\
\bottomrule
\end{tabularx}
\end{center}

% ================================================================
\section{项目运行流程}
% ================================================================

\subsection{上电之后发生什么（初始化流程）}
\texttt{setup()}（\texttt{main.cpp:713}）的顺序是踩坑调整过的：
\begin{ascii}
上电/Reset
  → Serial.begin(115200)          串口先起，方便看后续日志
  → pinMode(0, INPUT_PULLUP)      BOOT按钮(GPIO0)做显示模式切换
  → 双路I²C初始化  I2C_MPU(21,22,400k) / I2C_OLED(18,19,400k)
  → scanI2CDevices()              扫总线确认 0x68/0x3C 在位（排错关键）
  → Init_mpu6050()                ±8G/±500°/s，DLPF=94Hz，初始化滤波缓冲
  → initGPS()                     UART2 9600，PMTK配 10Hz+精简NMEA+SBAS
  → initPerformanceAnalyzer() / initMotorcycleMode() / initAudioRecorder()
  → [SD卡初始化被注释跳过]          [!] 当前为“测试模式”（见踩坑记录）
  → display.begin()               OLED启动，开机画面2秒
  → SPIFFS.begin(true)            挂载文件系统（网页+录音）
  → WiFi.softAP("ESP32-IMU")      开热点，固定IP 192.168.4.1
  → server.on(...) + server.begin()   注册6个HTTP路由
  → display_mode=1, displayQRCode()   初始显示WiFi连接信息
\end{ascii}

\subsection{主循环流程（任务调度）}
\texttt{loop()}（\texttt{main.cpp:835}）是系统心跳，用 \texttt{millis()} 时间片做\textbf{软件多任务}：
\begin{ascii}
loop() {
  server.handleClient();        ① Web请求：每圈都处理（非阻塞）
  检测BOOT按钮 → 切换 display_mode (0~4)
  handleSerialCommands();       ② 串口命令：每圈都查
  if (now-lastIMUTime   >= 5ms)   → ReadMPU6050() + fuseIMUSpeed()   // 200Hz
  if (now-lastGPSTime   >= 100ms) → updateGPSData() + SD记录          // 10Hz
  updateAudioRecorder();          → processSample() + 自动录音检查     // 持续
  if (now-lastUpdateTime>= 50ms)  → updateFusedData() + OLED + 串口   // 20Hz
}
\end{ascii}
\begin{say}{关键设计：全程无 delay()}
\texttt{loop()} 里\textbf{绝对没有 delay()}（除了按钮防抖那一处 200ms）。所有周期都用
“时间戳差值比较”实现非阻塞，这样高频 IMU 不会被低频 GPS 拖慢——这是裸机分时调度能跑起来的前提。
\end{say}

\subsection{中断流程}
全项目\textbf{只有一处硬件中断}：录音采样定时器。教科书式的 \textbf{ISR 最小化}。
\begin{ascii}
startRecording()
  → timerBegin(0, 80, true)        定时器0，80分频 → 1MHz计数
  → timerAlarmWrite(timer, 125)    125 tick = 125µs = 8kHz
  → timerAttachInterrupt(onSampleTimer)
        │ 每125µs触发
        ▼
  IRAM_ATTR onSampleTimer() {      中断服务程序（放IRAM加速）
     lastSample = adc1_get_raw()   只做最少的事：读ADC + 置标志位
     sampleReady = true
  }
        │ loop()中
        ▼
  processSample() {                重活放主循环（ISR外）
     8位量化 + 写缓冲 + 满512字节写SPIFFS
  }
\end{ascii}
原因——SPIFFS 写操作可能阻塞，绝不能在 ISR 里做。

\subsection{状态机流程}
项目里有\textbf{三个独立状态机}：

\textbf{1）录音状态机}（\texttt{audio\_recorder.cpp:296}）
\begin{ascii}
RECORDING_IDLE/STOPPED ──速度≥5km/h──► RECORDING_ACTIVE
        ▲                                   │
        │                          速度<2km/h 持续5秒
        └───────────────────────────────────┘
   (也可手动 start/stop/pause/resume)
\end{ascii}

\textbf{2）加速/制动测试状态机}（\texttt{gps\_module.cpp:337}）
\begin{ascii}
速度跨过 5km/h ──► 启动加速测试计时
   ├─ 跨 60km/h  → 记 0-60 时间
   ├─ 跨 100km/h → 记 0-100 时间
   └─ 跨 200km/h → 记 100-200，结束
速度≥95km/h ──► 启动制动测试 ──速度≤5km/h──► 记 100-0 时间
\end{ascii}

\textbf{3）SD 自动记录状态机}（\texttt{sd\_logger.cpp:280}）：速度 $>$5 km/h 开始记录，停车 30 秒后结束。

% ================================================================
\section{核心模块解析}
% ================================================================

\subsection{模块一：MPU6050 IMU 驱动（mpu6050.cpp）}
\textbf{职责}：读 6 轴数据，做振动滤波，算姿态角。\textbf{设计思路}：用 Adafruit 库读原始值，
但\textbf{不信任原始值}——叠加三级软件滤波。\textbf{数据结构} \texttt{MPU6050\_DATA} 同时保存“原始值”
和“\_Filtered 滤波值”两套：下游算 G 力用滤波值，算融合用原始值（积分对延迟敏感）。
\begin{center}\small
\begin{tabularx}{\linewidth}{@{}lX@{}}
\toprule
\textbf{函数} & \textbf{作用} \\
\midrule
\texttt{Init\_mpu6050()} & 量程 ±8G/±500°/s，DLPF=94Hz；失败时自动尝试 0x69 地址 \\
\texttt{ReadMPU6050()} & 读 a/g/temp → 滤波 → 算姿态角 \\
\texttt{FilterDataForVibration()} & 滑动平均(10点) + 一阶 IIR(\(\alpha\)=0.1) 级联 \\
\texttt{CalculateAttitude()} & atan2 算 Roll/Pitch（[!] Yaw 硬编码为 0） \\
\bottomrule
\end{tabularx}
\end{center}

\subsection{模块二：GPS 模块（gps_module.cpp）}
\textbf{职责}：解析 NMEA、抑制零漂、GPS-IMU 速度融合、跑加速/制动测试状态机。
这是\textbf{代码量最大、算法最密集的模块（756 行）}。本质是“清洗 + 融合”流水线。
\begin{center}\small
\begin{tabularx}{\linewidth}{@{}lX@{}}
\toprule
\textbf{函数} & \textbf{作用} \\
\midrule
\texttt{initGPS()} & UART2 + PMTK 配置（10Hz/精简NMEA/SBAS/WAAS） \\
\texttt{updateGPSData()} & 逐字节喂 TinyGPS++ → 三层零漂抑制 → 信号监控自恢复 \\
\texttt{fuseIMUSpeed()} & GPS-IMU 互补滤波（核心算法） \\
\texttt{calibrateIMUBias()} & 静止时递推均值在线校准加速度偏置（O(1) 内存） \\
\texttt{interpolateSpeedAtTime()} & 速度阈值穿越线性插值，把 10Hz 的 100ms 不确定度降到 ~10-20ms \\
\texttt{calculateDistance()} & Haversine 球面距离（位置跳变检测、圈速） \\
\texttt{saveSessionData/loadSessionData} & 用 ArduinoJson 把成绩存进 SPIFFS \\
\bottomrule
\end{tabularx}
\end{center}

\subsection{模块三：性能分析器 + 摩托车模式（performance_analyzer.cpp）}
\textbf{职责}：纯算法层。把 IMU + GPS 融合成 G 力，再衍生摩托专属指标。分两套数据
\texttt{fused\_data}（通用 G 力/功率）和 \texttt{moto\_data}（压弯/翘头/弯道）。
\begin{center}\small
\begin{tabularx}{\linewidth}{@{}lX@{}}
\toprule
\textbf{函数} & \textbf{作用} \\
\midrule
\texttt{calculateGForces()} & 动态信心度加权融合 GPS 差分加速度与 IMU；静止/动态两套逻辑 \\
\texttt{calculateLeanAngle()} & \textbf{互补滤波}算压弯倾角（陀螺仪积分 + 加速度计修正，\(\alpha\)=0.96） \\
\texttt{detectWheelieStoppie()} & 俯仰角 + 前向 G 力联合判断翘头/翘尾 \\
\texttt{analyzeCorner()} & 弯道进出检测 + 半径估算 $r = v^2/(g\cdot G_{lat})$ \\
\texttt{estimatePower()} & 滚阻+风阻+加速力模型估算功率(kW) \\
\bottomrule
\end{tabularx}
\end{center}
\begin{warn}{安装姿态硬编码}
\texttt{calculateLeanAngle()} 里 \texttt{Gyro\_Z\_Filtered} 被当作“横滚”、\texttt{Gyro\_X\_Filtered}
当作“偏航”，因为\textbf{传感器是垂直安装的}（X 轴朝下承重力）。坐标轴映射按这个安装姿态硬编码——
换安装方向就要改。
\end{warn}

\subsection{模块四：录音模块（audio_recorder.cpp）}
\textbf{职责}：定时器中断采集麦克风 ADC，存成 WAV 到 SPIFFS，骑行时自动录。
\textbf{数据结构}：\texttt{WAVHeader}（44 字节标准 WAV 头，先占位后回填 size）、
\texttt{AUDIO\_RECORDER\_DATA}（含录音状态机字段）。\textbf{设计思路}：8kHz/8bit/单声道——
刻意压低规格省 SPIFFS 空间。中断只读 ADC，写盘在主循环。

\subsection{模块五：SD 记录（sd_logger.cpp）}
\textbf{职责}：把每个数据点（18 字段）写成 CSV 行到 SD 卡，方便事后用 Excel/Python 分析。
\textbf{设计思路}：用 \textbf{HSPI}（而非默认 VSPI），MISO 改到 GPIO25 避开 GPIO12 启动冲突。
每 100 个点 flush 一次（平衡掉电安全与写入性能）。
\begin{warn}{半成品功能}
SD 初始化在 \texttt{setup()} 里被注释掉（“测试模式”），但 \texttt{loop()} 里仍调用
\texttt{checkAutoLogging} 和 \texttt{logDataPoint}。因 \texttt{initialized=false}，这些调用安全早退，不写盘。
\end{warn}

\subsection{模块六：Web 服务器（在 main.cpp 内）}
\textbf{职责}：WiFi 热点 + HTTP 服务，把数据 JSON 化推给手机网页。
\begin{center}\small
\begin{tabularx}{\linewidth}{@{}lX@{}}
\toprule
\textbf{路由} & \textbf{作用} \\
\midrule
\texttt{/} & 从 SPIFFS 返回 index.html（带 5 分钟缓存头） \\
\texttt{/data} & 主数据 JSON：温度/G力/角度/GPS/性能 \\
\texttt{/moto} & 摩托车模式 JSON：倾角/弯道/翘头/状态 \\
\texttt{/audio} & 录音状态 \\
\texttt{/audio/control} & 录音控制（start/stop/pause/list/...） \\
\texttt{/audio/download} & 下载 WAV 文件 \\
\bottomrule
\end{tabularx}
\end{center}
\textbf{设计思路}：用 \texttt{sprintf} 手拼 JSON（而非 ArduinoJson 序列化），固定 \texttt{char[]} 缓冲。
原因——\texttt{/data} 高频轮询，手拼比构建 JsonDocument 快、内存可控。代价是缓冲区大小要算准，否则溢出。

% ================================================================
\section{技术知识提取}
% ================================================================
\noindent 本部分只讲\textbf{项目里真的用到、且有“为什么”的}知识点。

\subsection{知识点 1：I²C（双路总线设计）}
MPU6050 与 OLED 都是 I²C 设备。项目用\textbf{两个独立的 I²C 控制器}：\texttt{TwoWire(0)} 给 MPU6050
（GPIO21/22），\texttt{TwoWire(1)} 给 OLED（GPIO18/19）。共享其实可行（地址 0x68/0x3C 不冲突），
分两路的好处是 OLED 刷新不会阻塞 IMU 的高频读取，代价是多占两个 GPIO。
\textbf{排错第一招}：\texttt{scanI2CDevices()} 分别扫两条总线。

\subsection{知识点 2：振动环境下的三级级联滤波（本项目灵魂）}
\textbf{解决}：发动机怠速 20\textasciitilde 50 Hz 振动叠加，G 力跳变、姿态抖 ±5°。
\begin{ascii}
原始ADC
  ① 硬件DLPF setFilterBandwidth(94Hz)   砍掉>94Hz，但保留快速动作响应
  ② 滑动平均FIR(窗口10@200Hz)            等效窗50ms，截止≈10Hz，无相位累积，延迟25ms
  ③ 一阶IIR低通(a=0.1)                   y=a*x+(1-a)*y_prev，截止≈3.5Hz，O(1)内存
  最终 *_Filtered (等效截止3~5Hz，振动衰减>12dB)
\end{ascii}
\textbf{关键权衡：}
\begin{itemize}
  \item DLPF 选 94Hz 而非 5Hz：陀螺仪要追摩托快速转向（可达 90°/s），截止太低动态响应变迟钝。硬件留宽，靠软件补。
  \item IIR 不用 FIR：MCU 上 IIR 只存一个上次输出值（O(1)），FIR 要存整个窗口。加速度测量不做频谱分析，对相位延迟不敏感。
  \item \(\alpha\)=0.1 怎么定：$f_c \approx \alpha f_s/(2\pi) \approx 0.1\times200/6.28 \approx 3.2$ Hz，再用串口波形微调。
\end{itemize}
\textbf{量化效果}：静止 G 力噪声 ±0.15g → ±0.01g；姿态抖动 ±5° → ±0.5°；代价 25\textasciitilde 50ms 延迟。

\subsection{知识点 3：互补滤波（Complementary Filter）}
\textbf{解决}：纯加速度计算姿态，动态时把“线加速度”误当“重力”，Pitch 虚假偏 5\textasciitilde 10°；
纯陀螺仪积分会漂移。\textbf{原理}：
\[ \theta = \alpha\,(\theta_{prev}+\omega\,dt) + (1-\alpha)\,\theta_{accel} \]
陀螺仪管高频（快、短期准），加速度计管低频（慢、长期准），互补。
\textbf{应用}：摩托倾角（\texttt{performance\_analyzer.cpp:524}）用 \(\alpha\)=0.96。注意\textbf{姿态主路径
（mpu6050.cpp）没用互补滤波}，是已知缺口——G 力优先级更高，姿态次要。
\textbf{误区}：\(\alpha\) 不是越大越好。\(\alpha\)=0.98 时间常数 $\tau=\alpha\cdot dt/(1-\alpha)\approx0.25$s，
这个“拉回速度”要和振动强度匹配着调。

\subsection{知识点 4：GPS-IMU 速度融合 + 动态信心度}
GPS 准但慢（10Hz、低速噪声大）；IMU 快（200Hz）但积分会漂。\textbf{两个融合点}：
\begin{enumerate}
  \item \textbf{速度融合}（\texttt{fuseIMUSpeed}，互补滤波）：200Hz 用加速度积分填 GPS 帧间空白，
        每个 GPS 帧（~100ms）到来时按 \texttt{GPS\_CORRECTION\_RATE=0.1} 拉回 10\% 漂移。
  \item \textbf{G 力融合}（\texttt{calculateGForces}，动态信心度）：按实时信号质量算
        \texttt{imu\_confidence = gps稳定性 × 信号质量}，动态分配 GPS 差分加速度与 IMU 的权重。
\end{enumerate}
\begin{center}\small
\begin{tabularx}{\linewidth}{@{}lXX@{}}
\toprule
 & \textbf{本项目(互补/自适应IIR)} & \textbf{卡尔曼(EKF)} \\
\midrule
计算量 & 极低，适合 ESP32 & 矩阵运算重 \\
调参 & 直观(\(\alpha\)、死区) & 要建模 Q/R 协方差 \\
选择 & [v] & 改进方向 \\
\bottomrule
\end{tabularx}
\end{center}
\textbf{误区}：用 GPS 速度\textbf{要用 Doppler 测速而非位置差分}。TinyGPS++ 的 \texttt{gps.speed.kmph()}
解析的 RMC 速度本身就是 Doppler 速度，精度比位置差分高 ~10 倍。项目用对了。

\subsection{知识点 5：GPS 零漂抑制（三层）}
GT-U7 静止时输出 0.5\textasciitilde 2 km/h 假速度。三层压制：
\begin{ascii}
层1：20点滑动平均 + 标准差分析   std_dev<0.2 且 avg<动态阈值 → 判定稳定
层2：自适应IIR (按速度段调a)     <0.5km/h→a=0.92强抑零漂；>4km/h→a=0.35快响应不耽误计时
层3：最终死区                    好信号(≥8星,HDOP<1.0)阈值0.8km/h，否则1.2km/h，以下归零
\end{ascii}
判定静止需持续 1.5 秒（15 次 ×100ms）。这是\textbf{精度 vs 响应}的反复权衡。

\subsection{知识点 6：ADC + 定时器中断采样（录音）}
\textbf{为什么用 ADC1 的 GPIO34}：ESP32 的 \textbf{ADC2 与 WiFi 冲突}（WiFi 开启时 ADC2 不可用）。
本项目全程开热点，麦克风必须接 ADC1。GPIO34 是纯输入引脚，最适合模拟输入。这是个容易踩、项目避开了的坑。
\textbf{采样}：硬件定时器 80 分频得 1MHz，125 tick=125µs=8kHz 触发，ISR 只 \texttt{adc1\_get\_raw} + 置标志。

\subsection{知识点 7：WAV 文件格式}
44 字节 RIFF 头 + PCM 裸数据。录音时先写占位头（size=0），结束时 \texttt{seek(0)} 回填真实
\texttt{dataSize}/\texttt{fileSize}。8bit 无符号 PCM，中心在 128。

\subsection{知识点 8：SPIFFS vs SD 卡}
\begin{center}\small
\begin{tabularx}{\linewidth}{@{}lXX@{}}
\toprule
 & \textbf{SPIFFS（板载Flash）} & \textbf{SD卡（外接）} \\
\midrule
容量 & ~1-3MB & GB级 \\
用途 & 网页文件 + 录音(小) & 行车CSV(大量) \\
接口 & 内部 & SPI(HSPI) \\
项目状态 & 在用 & 半成品(初始化被注释) \\
\bottomrule
\end{tabularx}
\end{center}

\subsection{知识点 9：PMTK / NMEA 协议}
GPS 用 NMEA 文本协议输出（\texttt{\$GPRMC}/\texttt{\$GPGGA}），用 PMTK 专有指令配置：
\texttt{\$PMTK220,100} 更新率 10Hz；\texttt{\$PMTK314,...} 只输出 RMC+GGA（防 9600 波特率溢出）；
\texttt{\$PMTK313,1} 启用 SBAS；\texttt{\$PMTK301,2} DGPS 用 WAAS。
\begin{warn}{文档与代码不一致}
\texttt{GT-U7\_ULTIMATE\_OPTIMIZATION.md} 说要把波特率提到 38400、用多星座，但 \texttt{initGPS()}
实际代码仍是 9600 + 10Hz。优化文档是“设想”，代码是“现状”。
\end{warn}

\subsection{知识点 10：HTTP / WiFi SoftAP}
ESP32 开热点（\texttt{WiFi.softAP}），固定 IP 192.168.4.1，跑 \texttt{WebServer}。网页 JS 轮询
\texttt{/data} 拿 JSON。\texttt{/data} 返回 \texttt{no-cache}（实时数据），\texttt{/}（HTML）返回
\texttt{max-age=300}（静态可缓存）——缓存策略区分对了。

% ================================================================
\section{设计决策分析}
% ================================================================
\begin{description}[leftmargin=0pt,style=nextline]
\item[决策 1：裸机分时调度，而非 FreeRTOS 任务]
  \texttt{loop()} 用 \texttt{millis()} 时间戳差比较，全程无 \texttt{delay()}。
  优点：简单、可控、无竞态、无切换开销；缺点：任一环节阻塞拖垮全局，没用上第二个核。
  数据流明确、无长阻塞操作，裸机分时足够且心智负担小。
\item[决策 2：全局数据结构通信，而非消息传递]
  零拷贝、无动态分配、实现极简；强耦合、不可重入（但单线程无此问题）。嵌入式裸机标准做法。
\item[决策 3：环形缓冲区做滑动平均]
  定长数组 + 取模索引 + \texttt{buffer\_full} 标志处理冷启动。O(1) 内存，无动态分配。
\item[决策 4：互补滤波而非卡尔曼]
  ESP32 算力和调参成本下，互补/自适应 IIR 性价比远高于 EKF。
\item[决策 5：双 I²C 总线]
  OLED 刷新不阻塞 IMU 读取；代价多占 2 个 GPIO。可单总线共享（地址不冲突）。
\item[决策 6：手拼 JSON 而非序列化库]
  热路径（\texttt{/data} 高频）选性能；冷路径（\texttt{saveSessionData}）用 ArduinoJson 选可维护——\textbf{两种都用，按场景分}。
\item[决策 7：SD 卡用 HSPI + MISO 改 GPIO25]
  GPIO12 是 strapping 引脚（启动拉高致 flash 电压判断错、启动失败），把 MISO 挪到 GPIO25 避开——ESP32 经典硬件坑。
\item[决策 8：录音 8kHz/8bit]
  SPIFFS 只有几 MB，录的是骑行环境音/排气声，不需高保真，容量优先（8KB/s，5 分钟约 2.4MB）。
\end{description}

% ================================================================
\section{调试与踩坑记录}
% ================================================================
\noindent 部分来自代码痕迹推断，部分已记录在 \texttt{INTERVIEW\_NOTES.md}。

\begin{center}\small
\begin{tabularx}{\linewidth}{@{}p{3.4cm}Xl@{}}
\toprule
\textbf{坑} & \textbf{原因 / 解决} & \textbf{状态} \\
\midrule
IMU 被发动机振动淹没 & DLPF 默认 260Hz 等于没滤；三级级联滤波，等效截止 3\textasciitilde 5Hz & [*]已解决 \\
GPS 静止零漂 & 多路径反射 + 几何误差；三层零漂抑制（均值+标准差/自适应IIR/死区） & [*]已解决 \\
IMU 偏置致积分漂移 & 出厂零偏 ±50\textasciitilde 150mg；手动硬编码 + GPS判静止时递推均值在线校准 & [*]部分解决 \\
GPS 位置跳变 & 遮挡后重定位瞬跳数百米；Haversine 算帧间距离，>1000m 拒绝 & [*]已解决 \\
GPIO12 启动冲突(SD) & strapping 引脚；MISO 挪到 GPIO25，用 HSPI & [*]已规避 \\
ADC2 与 WiFi 冲突(麦克风) & WiFi 开启时 ADC2 读不到；麦克风接 ADC1 的 GPIO34 & [*]已规避 \\
9600 下 10Hz NMEA 溢出 & 全量语句溢出丢帧；PMTK314 只留 RMC+GGA & [*]已规避 \\
文档与代码脱节 & README/优化文档 与代码 多处对不上（见下） & [!] 待修 \\
SD 记录是半成品 & initSDCard() 被注释，loop() 仍调（initialized=false 安全早退） & [!] 待完成 \\
\bottomrule
\end{tabularx}
\end{center}

\subsubsection{脱节细节（坑 8 展开）}
\begin{itemize}
  \item README 写“共享 I²C 总线 GPIO21/19”，实际代码是\textbf{双路} GPIO21/22 + GPIO18/19。
  \item README 的 \texttt{lib\_deps} 写 \texttt{electroniccats/MPU6050}，实际 \texttt{platformio.ini} 用 \texttt{adafruit/Adafruit MPU6050}。
  \item \texttt{GT-U7\_ULTIMATE} 说 38400 波特率/多星座，代码实际 9600/10Hz。
\end{itemize}

\subsubsection{潜在风险（代码审查角度，未必触发）}
\begin{itemize}
  \item \textbf{JSON 缓冲区}：\texttt{/data} 用 \texttt{char[750]}、\texttt{/moto} 用 \texttt{char[600]} 手拼，
        字段多、\texttt{\%.8f} 经纬度长，\textbf{接近上限，加字段易溢出}。建议加 \texttt{snprintf} 长度保护。
  \item \textbf{静止校准 static 局部变量}：\texttt{calculateGForces} 里 \texttt{gravity\_bias\_x} 等用 \texttt{static}
        且只累加不重置，长时间运行逻辑可能僵化（满 50 样本后固定）。
\end{itemize}

% ================================================================
\section{工程实践总结}
% ================================================================
\subsubsection{做得好的地方}
\begin{itemize}
  \item \textbf{代码组织}：按外设/算法清晰分模块，头文件声明 + cpp 实现规整。
  \item \textbf{错误处理}：初始化大量带降级（MPU6050 试 0x68 失败试 0x69；OLED 失败仍继续；GPS 信号丢失自动热重启）。\textbf{失败不死机、打印原因、降级运行}的思路很成熟。
  \item \textbf{可观测性}：串口三种打印模式可运行时切换；I²C 扫描、原始 NMEA 打印——调试钩子完备。
  \item \textbf{构建系统}：PlatformIO 依赖锁版本，\texttt{monitor\_filters = esp32\_exception\_decoder} 自动解崩溃栈。
  \item \textbf{配置管理}：引脚、阈值、滤波系数都用 \texttt{\#define}/\texttt{const} 集中在文件头。
  \item \textbf{场景化分层}：热路径手拼 JSON 求性能，冷路径用 ArduinoJson 求可维护——分得清。
\end{itemize}
\subsubsection{可以改进的地方}
\begin{itemize}
  \item \textbf{文档同步}：README/优化文档已严重脱节（坑 8）。
  \item \textbf{魔法数字}：\texttt{-0.47/+0.5/-0.48} 校准偏置散落多文件，应抽成统一配置或自动校准。
  \item \textbf{缓冲区安全}：手拼 JSON 用 \texttt{sprintf} 无长度保护，应换 \texttt{snprintf}。
  \item \textbf{SD 功能收尾}：要么启用要么删，别留半成品调用。
  \item \textbf{测试策略}：目前\textbf{无任何自动化测试}（\texttt{test/} 只有空 README）。IMU 滤波、Haversine、零漂判定这些纯函数很适合 host 端单元测试。
  \item \textbf{持续集成}：无 CI，可加 \texttt{pio ci} 在 push 时编译检查。
\end{itemize}

% ================================================================
\section{项目复盘}
% ================================================================
\subsubsection{最大的亮点}
把“算法”当成项目主角，而非“点亮外设”。\textbf{三级滤波 + GPS-IMU 融合 + 动态信心度}这套组合，
把 30 元 GPS 的静止零漂从 ±2.5 压到 ±0.8 km/h（与专业设备差距从 20 倍缩到 4 倍，成本差 67 倍）。

\subsubsection{最大的难点}
\textbf{在脏数据上做可信的实时融合}。难点不在写公式，而在：什么时候信谁、信多少（动态信心度）、
怎么不让滤波延迟拖垮测试计时（自适应 \(\alpha\)）。都是反复调参 + 串口看波形磨出来的。

\subsubsection{学到的知识}
滤波器选型的工程权衡（FIR vs IIR、硬件 vs 软件、截止频率 vs 响应延迟）；传感器融合实战；
ESP32 硬件陷阱（strapping 引脚、ADC2/WiFi 冲突）；裸机分时调度模式；GPS NMEA/PMTK、Doppler 测速。

\subsubsection{如果重新设计会怎么做}
\begin{itemize}
  \item 传感器融合上 \textbf{1D 卡尔曼}（只融合纵向速度，状态量少，ESP32 扛得住）。
  \item 校准全自动化，删硬编码偏置，统一静止在线校准 + 温度补偿。
  \item 姿态主路径加互补滤波，解决加速时 Pitch 虚假偏移。
  \item 抽配置层（所有引脚/阈值/系数集中到 \texttt{config.h}）。
  \item 加 host 端单元测试；用 FreeRTOS 双核物理隔离 Web/录音 与 传感器融合。
\end{itemize}

\subsubsection{下一步可以扩展什么}
升级 GPS 到 NEO-M9N（\texttt{GPS\_UPGRADE\_ANALYSIS.md} 已选型，150 元换 5-8 倍精度）；真正启用 SD 记录 +
Python 分析脚本；加磁力计（QMC5883L）补全 Yaw；大倾角重力分量补偿 $a_{\mathrm{true}}=a_{\mathrm{meas}}-g\sin(\mathrm{Roll})$；
网页端轨迹回放 / 成绩对比。
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

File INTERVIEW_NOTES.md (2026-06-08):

# ESP32 IMU + GPS 项目 — 面试技术答辩归档

> 本文档面向技术面试场景，逐一解释项目中遇到的真实工程问题、解决方案原理及量化效果。
> 所有描述均有对应代码佐证（标注了文件和行号）。

---

## 目录

1. [项目背景一句话介绍](#0-项目背景)
2. [问题一：IMU 被发动机震动淹没](#问题一imu-被发动机震动淹没)
3. [问题二：姿态角纯用加速度计 → 震动下抖动](#问题二姿态角纯靠加速度计的局限)
4. [问题三：GPS 静止时速度不归零（零漂）](#问题三gps-静止零漂)
5. [问题四：GPS-IMU 融合的信心度机制](#问题四gps-imu-融合与动态信心度)
6. [问题五：IMU 加速度偏置（Zero-g Offset）校准](#问题五imu-加速度偏置校准)
7. [问题六：GPS 位置跳变过滤](#问题六gps-位置跳变过滤)
8. [已知缺口与改进方向](#已知缺口与改进方向)
9. [面试常见追问 Q&A](#面试常见追问-qa)

---
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

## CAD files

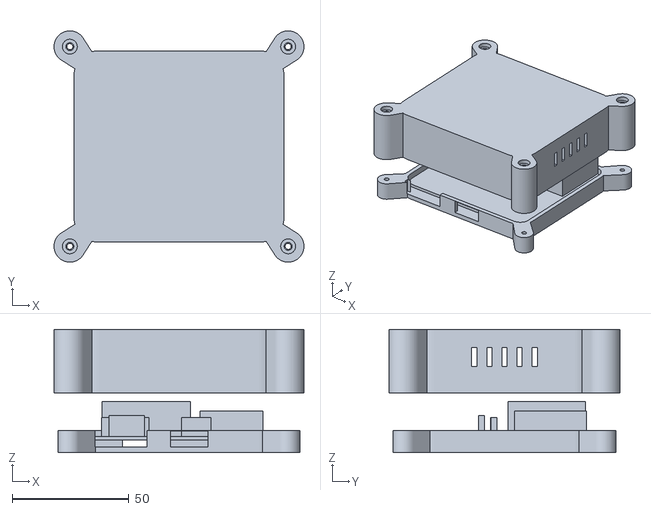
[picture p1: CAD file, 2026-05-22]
cad/pcb1_enclosure_exploded.stl
107.3 x 99.3 x 53.0

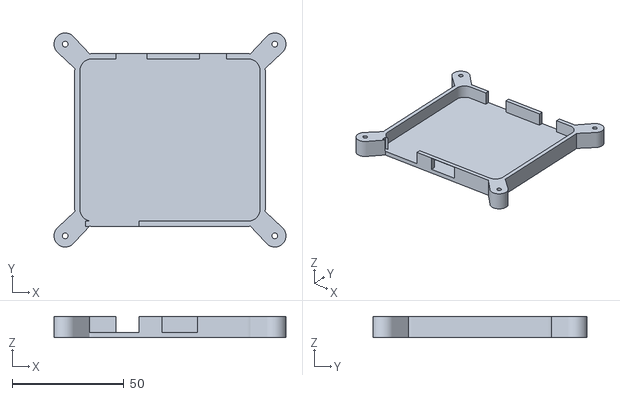
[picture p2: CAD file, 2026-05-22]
cad/pcb1_enclosure_base.stl
103.7 x 95.7 x 9.55

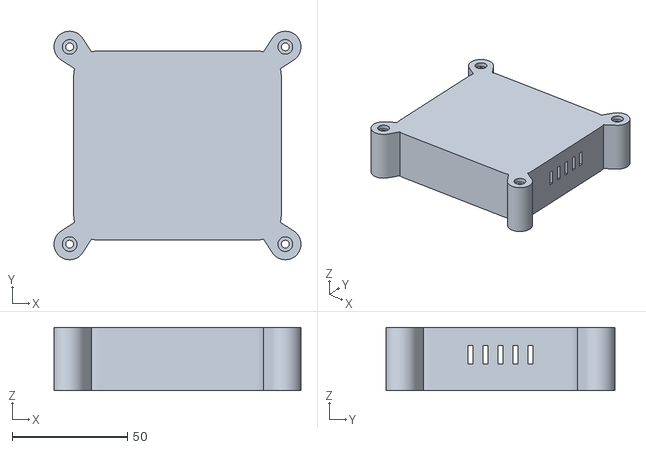
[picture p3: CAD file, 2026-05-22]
cad/pcb1_enclosure_lid.stl
107.3 x 99.3 x 27.4

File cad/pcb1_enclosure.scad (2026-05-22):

/*
  Parametric enclosure for PCB1 derived from Gerber_BoardOutlineLayer.GKO.
  Board outline: 78.867 mm x 70.866 mm with 5.08 mm corner radius.
*/

$fn = $preview ? 32 : 64;  // fast preview, high-res render

show_mode = "assembled";  // assembled, exploded, base, lid, pcb
export_mode = 0;  // 0=use show_mode, 1=base, 2=lid, 3=exploded, 4=pcb
show_components = true;

// PCB measured from Gerber outline.
board_length = 78.867;
board_width = 70.866;
board_corner_radius = 5.08;
board_thickness = 1.6;

// Mechanical clearances.
fit_gap = 0.35;
board_edge_gap = 0.8;
underside_clearance = 3.0;
topside_clearance = 18.0;
wall_thickness = 2.4;       // 6 × 0.4 mm nozzle walls
floor_thickness = 2.4;
lid_top_thickness = 2.4;    // matches floor_thickness
lid_clearance = 0.45;
lid_wall_thickness = 2.0;
lid_overlap_height = 6.0;
lid_wall_height = topside_clearance + lid_overlap_height + 1.0;
corner_relief = 0.6;

// Shell fastening: external screw ears avoid stealing the PCB interior space.
use_fastening_ears = true;
ear_radius = 4.8;
ear_offset = 4.2;
ear_bridge_radius = 3.2;
ear_bridge_pull = 0.72;
ear_bridge_inset = 7.8;
base_boss_diameter = 8.4;
base_boss_pad_radius = 5.0;
lid_ear_wall = 2.0;
screw_clearance_diameter = 3.4;
screw_pilot_diameter = 2.6;
screw_head_diameter = 6.4;
screw_head_depth = 2.2;

// Internal support geometry for a hole-free PCB.
support_ring_width = 3.0;
support_ring_height = 1.8;
retainer_height = 2.2;
retainer_width = 7.0;
retainer_inset = 11.0;
retainer_gap = 0.4;

// Optional lid pressure pads that keep the PCB seated.
use_pressure_pads = true;
pressure_pad_height = 1.5;
pressure_pad_diameter = 8.0;
component_clearance_gap = 1.2;

// Ventilation slots cut into the lid east/west outer walls.
use_vent_slots   = true;
vent_slot_width  = 2.2;   // slot opening in Y (mm)
vent_slot_height = 8.0;   // slot opening in Z (mm)
vent_slot_pitch  = 6.5;   // centre-to-centre spacing (mm)
vent_slot_count  = 5;     // slots per wall pair

// Edge cutouts in the base, described as [center,width,height].
// Defaults are inferred from the PCB probe and silkscreen data.
north_cutouts = [
    [25.4, 14.0, 8.5],   // ESP32 USB / top-side service access
    [61.9, 12.0, 8.0]    // top-right 4-pin connector
];

south_cutouts = [
    [16.8, 24.0, 8.0],   // lower-left connector cluster
    [47.0, 16.0, 7.0]    // lower-middle/right connector cluster
];

east_cutouts = [];
west_cutouts = [];

exploded_gap = 22.0;

outer_length = board_length + 2 * (board_edge_gap + wall_thickness);
outer_width = board_width + 2 * (board_edge_gap + wall_thickness);
outer_corner_radius = board_corner_radius + board_edge_gap + wall_thickness;

board_origin_x = wall_thickness + board_edge_gap;
board_origin_y = wall_thickness + board_edge_gap;
board_seat_z = floor_thickness + underside_clearance;
base_height = board_seat_z + board_thickness + retainer_height + fit_gap;
lid_total_height = lid_top_thickness + lid_wall_height;
base_inner_length = outer_length - 2 * wall_thickness;
base_inner_width = outer_width - 2 * wall_thickness;
base_inner_radius = max(outer_corner_radius - wall_thickness - corner_relief, 0.8);
lid_inner_length = outer_length + 2 * lid_clearance;
lid_inner_width = outer_width + 2 * lid_clearance;
lid_inner_radius = outer_corner_radius + lid_clearance;
lid_outer_length = lid_inner_length + 2 * lid_wall_thickness;
lid_outer_width = lid_inner_width + 2 * lid_wall_thickness;
lid_outer_radius = lid_inner_radius + lid_wall_thickness;
lid_origin_x = -(lid_wall_thickness + lid_clearance);
lid_origin_y = -(lid_wall_thickness + lid_clearance);
active_mode = export_mode == 1 ? "base"
    : export_mode == 2 ? "lid"
    : export_mode == 3 ? "exploded"
    : export_mode == 4 ? "pcb"
    : show_mode;

ear_positions = [
    [-ear_offset, -ear_offset],
    [outer_length + ear_offset, -ear_offset],
    [-ear_offset, outer_width + ear_offset],
    [outer_length + ear_offset, outer_width + ear_offset]
];

module rounded_rect_2d(length, width, radius) {
    hull() {
        for (x = [radius, length - radius])
            for (y = [radius, width - radius])
                translate([x, y]) circle(r = radius);
    }
}

module shell_outer_2d() {
    rounded_rect_2d(outer_length, outer_width, outer_corner_radius);
}

module ear_bridge_anchor_pair(x_side, y_side) {
    translate([
        x_side < 0 ? ear_bridge_inset : outer_length - ear_bridge_inset,
        y_side < 0 ? outer_corner_radius * ear_bridge_pull : outer_width - outer_corner_radius * ear_bridge_pull
    ])
        circle(r = ear_bridge_radius);

    translate([
        x_side < 0 ? outer_corner_radius * ear_bridge_pull : outer_length - outer_corner_radius * ear_bridge_pull,
        y_side < 0 ? ear_bridge_inset : outer_width - ear_bridge_inset
    ])
        circle(r = ear_bridge_radius);
}

module fastening_ears_2d() {
    if (use_fastening_ears) {
        for (pos = ear_positions)
            hull() {
                translate(pos) circle(r = ear_radius);
                ear_bridge_anchor_pair(pos[0], pos[1]);
            }
    }
}

module shell_with_ears_2d() {
    union() {
        shell_outer_2d();
        fastening_ears_2d();
    }
}

module base_boss_tabs_2d() {
    if (use_fastening_ears) {
        for (pos = ear_positions)
            hull() {
                translate(pos) circle(r = base_boss_pad_radius);
                ear_bridge_anchor_pair(pos[0], pos[1]);
            }
    }
}

module lid_bridge_anchor_pair(x_side, y_side) {
    translate([
        x_side < 0 ? lid_origin_x + ear_bridge_inset : lid_origin_x + lid_outer_length - ear_bridge_inset,
        y_side < 0 ? lid_origin_y + lid_outer_radius * ear_bridge_pull : lid_origin_y + lid_outer_width - lid_outer_radius * ear_bridge_pull
    ])
        circle(r = ear_bridge_radius + lid_ear_wall * 0.35);

    translate([
        x_side < 0 ? lid_origin_x + lid_outer_radius * ear_bridge_pull : lid_origin_x + lid_outer_length - lid_outer_radius * ear_bridge_pull,
        y_side < 0 ? lid_origin_y + ear_bridge_inset : lid_origin_y + lid_outer_width - ear_bridge_inset
    ])
        circle(r = ear_bridge_radius + lid_ear_wall * 0.35);
}

module lid_fastening_ears_2d() {
    if (use_fastening_ears) {
        for (pos = ear_positions)
            hull() {
                translate(pos) circle(r = ear_radius + lid_ear_wall);
                lid_bridge_anchor_pair(pos[0], pos[1]);
            }
    }
}

module lid_outer_2d() {
    union() {
        translate([lid_origin_x, lid_origin_y])
            rounded_rect_2d(lid_outer_length, lid_outer_width, lid_outer_radius);

        lid_fastening_ears_2d();
    }
}

module lid_inner_2d() {
    translate([-lid_clearance, -lid_clearance])
        rounded_rect_2d(lid_inner_length, lid_inner_width, lid_inner_radius);
}

module ear_holes(diameter, height) {
    if (use_fastening_ears) {
        for (pos = ear_positions)
            translate([pos[0], pos[1], -0.05])
                cylinder(h = height + 0.1, d = diameter);
    }
}

module screw_counterbores() {
    if (use_fastening_ears) {
        for (pos = ear_positions)
            translate([pos[0], pos[1], lid_wall_height + lid_top_thickness - screw_head_depth])
                cylinder(h = screw_head_depth + 0.05, d = screw_head_diameter);
    }
}

module board_outline_2d(clearance = 0) {
    translate([board_origin_x, board_origin_y])
        offset(r = clearance)
            rounded_rect_2d(board_length, board_width, board_corner_radius);
}

module board_center_relief_2d() {
    translate([board_origin_x + support_ring_width, board_origin_y + support_ring_width])
        rounded_rect_2d(
            board_length - 2 * support_ring_width,
            board_width - 2 * support_ring_width,
            max(board_corner_radius - support_ring_width, 0.8)
        );
}

module edge_cutout(side, center_pos, width, height) {
    if (width > 0 && height > 0) {
        if (side == "north")
            translate([center_pos - width / 2, outer_width - wall_thickness - 0.1, floor_thickness])
                cube([width, wall_thickness + 0.2, height]);
        else if (side == "south")
            translate([center_pos - width / 2, -0.1, floor_thickness])
                cube([width, wall_thickness + 0.2, height]);
        else if (side == "east")
            translate([outer_length - wall_thickness - 0.1, center_pos - width / 2, floor_thickness])
                cube([wall_thickness + 0.2, width, height]);
        else if (side == "west")
            translate([-0.1, center_pos - width / 2, floor_thickness])
                cube([wall_thickness + 0.2, width, height]);
    }
}

module edge_cutouts(side, cutouts) {
    for (cutout = cutouts)
        edge_cutout(side, cutout[0], cutout[1], cutout[2]);
}

module pcb_proxy() {
    color([0.05, 0.45, 0.15])
        translate([board_origin_x, board_origin_y, board_seat_z])
            linear_extrude(board_thickness)
                rounded_rect_2d(board_length, board_width, board_corner_radius);
}
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

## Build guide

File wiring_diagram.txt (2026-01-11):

/*
 * ESP32 双I²C总线 + 麦克风接线图
 * 
 * ESP32-WROOM-32 引脚分配：
 * 
 *     ESP32          MPU6050         OLED (SSD1306)     麦克风模块
 *   ┌─────────┐    ┌─────────┐     ┌───────────┐     ┌───────────┐
 *   │         │    │         │     │           │     │           │
 *   │ GPIO22  ├────┤ SCL     │     │           │     │           │
 *   │ GPIO21  ├────┤ SDA     │     │           │     │           │
 *   │         │    │ VCC ────┼──┬──┤ VCC       │  ┌──┤ VCC       │
 *   │         │    │ GND ────┼──┼──┤ GND       │──┼──┤ GND       │
 *   │         │    └─────────┘  │  │           │  │  │           │
 *   │ GPIO19  ├─────────────────┼──┤ SCL       │  │  │           │
 *   │ GPIO18  ├─────────────────┼──┤ SDA       │  │  │           │
 *   │ GPIO34  ├─────────────────┼──┼───────────┼──┼──┤ OUT       │
 *   │ 3.3V    ├─────────────────┘  │           │──┘  │           │
 *   │ GND     ├────────────────────┘           │     └───────────┘
 *   └─────────┘                    └───────────┘
 * 
 *     ESP32          GPS (GT-U7)
 *   ┌─────────┐    ┌───────────┐
 *   │ GPIO16  ├────┤ TX (RX<-) │
 *   │ GPIO17  ├────┤ RX (TX->) │
 *   │ 3.3V    ├────┤ VCC       │
 *   │ GND     ├────┤ GND       │
 *   └─────────┘    └───────────┘
 * 
 * 重要提醒：
 * 1. 所有设备共用3.3V电源和GND
 * 2. 不要连接到5V，ESP32和传感器都是3.3V设备
 * 3. 如果连接距离较长，建议添加4.7kΩ上拉电阻到3.3V
 * 4. 确保接线稳定，避免接触不良
 * 5. 麦克风OUT必须接到ADC引脚(GPIO34是纯输入引脚，最适合)
 * 
 * I²C地址：
 * - MPU6050: 0x68 (AD0接GND) 或 0x69 (AD0接VCC)
 * - SSD1306: 0x3C (大部分模块) 或 0x3D
 * 
 * 引脚功能说明：
 * - SDA (Serial Data): 数据线，双向通信
 * - SCL (Serial Clock): 时钟线，主设备产生时钟信号
 * - GPIO34: ADC1_CH6 模拟输入引脚，用于麦克风音频采集
 * 
 * 电气特性：
 * - 工作电压: 3.3V
 * - I²C频率: 400kHz (快速模式)
 * - 上拉电阻: 内部已有，外部可选4.7kΩ
 * - GPS波特率: 9600bps
 * - 麦克风采样率: 8kHz
 */

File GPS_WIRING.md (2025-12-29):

# ESP32 Draggy Performance Logger - 接线图

## 硬件连接图

### ESP32 开发板连接

#### I2C设备连接 (共享总线)
- **SDA**: GPIO21 → MPU6050 SDA, OLED SDA
- **SCL**: GPIO22 → MPU6050 SCL, OLED SCL
- **VCC**: 3.3V → 所有设备VCC  
- **GND**: GND → 所有设备GND

#### GT-U7 GPS模块连接
- **GPS VCC** → ESP32 3.3V (或5V，根据模块规格)
- **GPS GND** → ESP32 GND
- **GPS TX** → ESP32 GPIO16 (RX2)
- **GPS RX** → ESP32 GPIO17 (TX2)

### 完整连接表

| 设备 | 引脚 | ESP32引脚 | 说明 |
|---|---|---|---|
| MPU6050 | VCC | 3.3V | 电源 |
| MPU6050 | GND | GND | 地线 |
| MPU6050 | SDA | GPIO21 | I2C数据线 |
| MPU6050 | SCL | GPIO22 | I2C时钟线 |
| OLED SSD1306  | VCC | 3.3V | 电源 |
| OLED SSD1306  | GND | GND | 地线 |
| OLED SSD1306  | SDA | GPIO21 | I2C数据线 (与MPU共享) |
| OLED SSD1306  | SCL | GPIO22 | I2C时钟线 (与MPU共享) |
| GT-U7 GPS | VCC | 3.3V/5V | 电源 (检查模块电压要求) |
| GT-U7 GPS | GND | GND | 地线 |
| GT-U7 GPS | TX | GPIO16 | GPS串口发送→ESP32接收 |
| GT-U7 GPS | RX | GPIO17 | GPS串口接收←ESP32发送 |

### 注意事项

1. **电源要求**
   - 确认GT-U7模块的工作电压 (3.3V或5V)
   - 如果是5V模块，可能需要电平转换

2. **GPS天线**
   - GT-U7模块通常自带陶瓷天线
   - 确保天线面朝上，远离金属遮挡
   - 首次定位可能需要1-5分钟

3. **I2C地址**
   - MPU6050: 0x68 (AD0接地) 或 0x69 (AD0接VCC)
   - OLED: 0x3C 或 0x3D (根据模块设置)

4. **车辆安装**
   - MPU6050应水平安装，X轴指向车头方向
   - 确保设备固定牢固，减少振动影响
   - GPS天线需要良好的卫星视野

### 推荐的车辆安装位置

- **仪表台中央**: GPS信号接收良好，易于观察OLED显示
- **中控台**: 靠近12V电源，便于长期供电
- **避免**: 金属屋顶下方，强电磁干扰区域

### 供电方案

1. **USB供电**: 开发和测试阶段
2. **车载12V转5V/3.3V**: 实际使用
3. **移动电源**: 便携式测试

### 性能优化建议

1. **GPS定位精度**
   - 选择开阔场地进行首次定位
   - 等待至少4颗卫星信号稳定

2. **IMU校准**
   - 设备安装后进行零点校准
   - 定期检查传感器偏移

3. **数据记录**
   - 建议使用SPIFFS保存测试数据
   - 可通过Web界面下载历史记录

### 故障排除

1. **GPS无法定位**
   - 检查天线位置和朝向
   - 确认串口连接和波特率 (9600)
   - 观察卫星数量显示

2. **I2C设备无响应**
   - 检查SDA/SCL接线
   - 确认设备地址设置
   - 检查电源电压

3. **性能数据异常**
   - 重新校准IMU传感器
   - 检查车辆安装角度
   - 确认GPS速度数据有效

## 软件配置

### 主要功能模式

- **模式0**: IMU数据显示 (姿态角、G力)
- **模式1**: WiFi连接二维码  
- **模式2**: GPS状态 (速度、卫星数量)
- **模式3**: 性能数据 (加速时间、最大G力)

### Web界面访问

1. 连接WiFi热点 "ESP32-IMU" (密码: 12345678)
2. 访问 http://192.168.4.1
3. 查看实时数据和历史记录

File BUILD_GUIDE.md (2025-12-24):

# 项目编译和使用指南

## 📋 环境要求

### 1. 安装VS Code和PlatformIO扩展

1. 下载并安装 [Visual Studio Code](https://code.visualstudio.com/)
2. 在VS Code中安装PlatformIO扩展：
   - 打开VS Code
   - 按Ctrl+Shift+X打开扩展面板
   - 搜索"PlatformIO IDE"
   - 点击安装

### 2. 打开项目

1. 在VS Code中选择 **File → Open Folder**
2. 选择项目目录：`esp32 imu`
3. PlatformIO会自动识别项目并下载依赖

## 🔧 编译步骤

### 方法1：使用VS Code界面（推荐）

1. 打开项目后，在底部状态栏会显示PlatformIO图标
2. 点击底部的"✓"图标进行编译
3. 或者使用快捷键：Ctrl+Alt+B

### 方法2：使用PlatformIO命令面板

1. 按Ctrl+Shift+P打开命令面板
2. 输入"PlatformIO: Build"
3. 选择并执行

### 方法3：使用PlatformIO终端

1. 在VS Code中打开终端（Ctrl+`）
2. 执行命令：
```bash
# 如果已安装PlatformIO CLI
pio run

# 或者使用完整命令
platformio run
```

## 📤 上传到ESP32

### 准备工作

1. **连接ESP32**：使用USB数据线连接ESP32到电脑
2. **确认端口**：在设备管理器中查看COM端口号
3. **驱动安装**：确保ESP32驱动已正确安装

### 上传步骤

1. **VS Code界面方式**：
   - 点击底部状态栏的"→"(上传)图标
   - 或使用快捷键：Ctrl+Alt+U

2. **命令行方式**：
```bash
# 编译并上传
pio run --target upload

# 指定端口上传（如果检测不到）
pio run --target upload --upload-port COM3
```

## 🖥️ 串口监控

### 查看输出数据

1. **VS Code方式**：
   - 点击底部状态栏的"🔌"(串口监视器)图标
   - 波特率会自动设置为115200

2. **命令行方式**：
```bash
# 监视串口输出
pio device monitor

# 指定端口和波特率
pio device monitor --port COM3 --baud 115200
```

### 预期输出示例

```
ESP32双I²C总线IMU+OLED项目启动...
初始化I²C总线0 (MPU6050)...
初始化I²C总线1 (OLED)...
初始化MPU6050传感器...
✓ MPU6050连接成功
✓ MPU6050配置完成
初始化OLED显示屏...
✓ OLED初始化成功
系统初始化完成
开始数据采集和显示...

=================== IMU数据 ===================
加速度 (g):   X=0.012, Y=-0.034, Z=0.987
角速度 (°/s): X=0.45, Y=-0.23, Z=0.12
温度: 28.5°C
合成加速度: 0.988g
===============================================
```

## 🔍 故障排除

### 编译错误

1. **库依赖问题**：
   - 确保`platformio.ini`中的库版本正确
   - 清除缓存：PlatformIO → Miscellaneous → Clean

2. **版本冲突**：
   - 删除`.pio`文件夹
   - 重新编译项目

### 上传失败

1. **端口问题**：
   - 检查USB连接
   - 确认端口号正确
   - 尝试不同的USB线

2. **ESP32进入下载模式**：
   - 按住BOOT按键，然后按RESET按键
   - 松开RESET，再松开BOOT
   - 重试上传

### 运行异常

1. **设备连接检查**：
   - 验证所有接线正确
   - 检查电源供应（3.3V）
   - 测试I²C设备地址

2. **代码调试**：
   - 检查串口输出中的错误信息
   - 使用I²C扫描功能查找设备

## 🛠️ 开发技巧

### 1. 实时调试

在`main.cpp`中添加调试代码：
```cpp
// I²C设备扫描
void scanI2CDevices(TwoWire &wire, const char* busName) {
    Serial.printf("扫描%s总线设备...\n", busName);
    int deviceCount = 0;
    for (byte address = 1; address < 127; address++) {
        wire.beginTransmission(address);
        if (wire.endTransmission() == 0) {
            Serial.printf("发现设备地址: 0x%02X\n", address);
            deviceCount++;
        }
    }
    Serial.printf("总共发现 %d 个设备\n", deviceCount);
}

// 在setup()中调用
scanI2CDevices(I2C0, "I²C0");
scanI2CDevices(I2C1, "I²C1");
```

### 2. 性能监控

添加性能监控代码：
```cpp
void loop() {
    unsigned long startTime = micros();
    
    // 原有代码...
    readIMUData();
    updateDisplay();
    
    unsigned long endTime = micros();
    Serial.printf("循环执行时间: %lu微秒\n", endTime - startTime);
}
```

### 3. 错误恢复

添加自动重连机制：
```cpp
bool reconnectMPU6050() {
    Serial.println("尝试重新连接MPU6050...");
    mpu.initialize(&I2C0);
    if (mpu.testConnection()) {
        Serial.println("MPU6050重连成功");
        return true;
    }
    Serial.println("MPU6050重连失败");
    return false;
}
```

## 📚 进阶配置

### 自定义编译选项

在`platformio.ini`中添加：
```ini
build_flags = 
    -D CORE_DEBUG_LEVEL=3      # 调试级别
    -D CONFIG_ARDUHAL_LOG_COLORS=1  # 彩色日志
    -D BOARD_HAS_PSRAM         # 如果使用PSRAM
    
monitor_filters = 
    esp32_exception_decoder    # 异常解码
    time                       # 添加时间戳
```

### 优化设置

```ini
board_build.partitions = huge_app.csv  # 更大的应用分区
board_build.flash_mode = qio           # 更快的Flash模式
board_build.f_cpu = 240000000L         # CPU频率240MHz
board_build.f_flash = 80000000L        # Flash频率80MHz
```

---

**注意**：如果遇到任何问题，请首先检查硬件连接，然后查看串口输出中的错误信息。大部分问题都可以通过仔细检查接线和配置来解决。

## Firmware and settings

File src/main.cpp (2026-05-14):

/**
 * ESP32 I²C总线项目 - 使用Adafruit MPU6050库
 * 功能：使用Adafruit MPU6050库连接MPU6050和OLED显示屏
 * 
 * 硬件连接：
 * I²C总线 (共享):
 *   - SDA: GPIO21
 *   - SCL: GPIO22
 *   - MPU6050和OLED共享同一条I²C总线
 * 
 * 设备地址：
 *   - MPU6050: 0x68
 *   - OLED SSD1306: 0x3C
 * 
 * 作者：ESP32项目
 * 日期：2024
 */

#include <Arduino.h>
#include <Wire.h>
#include <Adafruit_GFX.h>
#include <Adafruit_SSD1306.h>
#include <WiFi.h>
#include <WebServer.h>
#include <SPIFFS.h>
#include "mpu6050.h"
#include "gps_module.h"
#include "performance_analyzer.h"
#include "audio_recorder.h"
#include "sd_logger.h"

// I²C双路总线引脚定义
// I2C0 - MPU6050传感器
#define I2C0_SDA 21    // MPU6050 SDA引脚
#define I2C0_SCL 22    // MPU6050 SCL引脚

// I2C1 - OLED显示屏
#define I2C1_SDA 18    // OLED SDA引脚
#define I2C1_SCL 19    // OLED SCL引脚

// OLED显示屏配置
#define SCREEN_WIDTH 128
#define SCREEN_HEIGHT 64
#define OLED_RESET -1
#define SCREEN_ADDRESS 0x3C

// 双路I²C总线设计
TwoWire I2C_MPU = TwoWire(0);  // I2C0 - MPU6050传感器
TwoWire I2C_OLED = TwoWire(1); // I2C1 - OLED显示屏

// 创建显示器对象（使用I2C1）
Adafruit_SSD1306 display(SCREEN_WIDTH, SCREEN_HEIGHT, &I2C_OLED, OLED_RESET);

// WiFi热点配置
const char* ap_ssid = "ESP32-IMU";
const char* ap_password = "12345678";

// Web服务器
WebServer server(80);

// 显示模式：0=IMU数据, 1=二维码, 2=GPS数据, 3=性能数据, 4=摩托车模式
int display_mode = 1;

// ===== Dragy模式定时配置 =====
unsigned long lastUpdateTime = 0;
const unsigned long UPDATE_INTERVAL = 50;      // 50ms显示更新(20Hz)

unsigned long lastIMUTime = 0;
const unsigned long IMU_INTERVAL = 5;          // 5ms IMU采样(200Hz) - 用于GPS-IMU融合

unsigned long lastGPSTime = 0;
const unsigned long GPS_INTERVAL = 100;        // 100ms GPS处理(10Hz)

// 串口打印配置
unsigned long lastPrintTime = 0;
const unsigned long PRINT_INTERVAL = 200;  // 200ms打印间隔(每秒5次)
const unsigned long DETAILED_PRINT_INTERVAL = 2000; // 2秒详细打印间隔
unsigned long lastDetailedPrintTime = 0;

// 打印模式选择 (0=简要模式, 1=详细模式, 2=混合模式)
int printMode = 2;

// 函数声明
void updateDisplay();
void displayGPSData();
void displayPerformanceData();
void displayMotorcycleData();
void handleMotoData();
void handleAudioData();
void handleAudioControl();
void handleAudioDownload();
void printDataToSerial();
void handleSerialCommands();
void scanI2CDevices();

/**
 * 更新OLED显示 - 图形化六轴显示
 */
// Web服务器处理函数
void handleRoot() {
    File file = SPIFFS.open("/index.html", "r");
    if (!file) {
        server.send(404, "text/plain", "HTML file not found! Please upload SPIFFS files first.");
        return;
    }
    
    // 添加HTTP缓存头和keep-alive
    server.sendHeader("Cache-Control", "public, max-age=300"); // 5分钟缓存
    server.sendHeader("Connection", "keep-alive");
    server.sendHeader("Content-Encoding", "identity");
    
    server.streamFile(file, "text/html");
    file.close();
}

void handleData() {
    // 简化数据处理 - 减少计算负载
    float acc_x_corrected = mpu6050_data.Acc_X_Filtered - 0.47;
    float acc_y_corrected = mpu6050_data.Acc_Y_Filtered + 0.5;
    float acc_z_corrected = mpu6050_data.Acc_Z_Filtered - 0.48;
    
    // 简化角度计算
    float roll = atan2(acc_z_corrected, acc_x_corrected) * 57.2958;  // 57.2958 = 180/PI
    float pitch = atan2(acc_y_corrected, acc_x_corrected) * 57.2958;
    
    // 简单滤波 - 只在必要时使用
    static float prev_roll = 0.0, prev_pitch = 0.0;
    static bool first_run = true;
    
    if (!first_run) {
        // 简单的均值滤波
        roll = (prev_roll + roll) * 0.5;
        pitch = (prev_pitch + pitch) * 0.5;
    }
    first_run = false;
    prev_roll = roll;
    prev_pitch = pitch;
    
    // 构建高精度JSON响应 - 最大化性能
    char json_buffer[750];
    
    // 高精度GPS数据验证
    double safe_lat = (gps_data.valid_location && gps_data.satellites >= 6) ? gps_data.latitude : 0.0;
    double safe_lon = (gps_data.valid_location && gps_data.satellites >= 6) ? gps_data.longitude : 0.0;
    double safe_speed = (gps_data.valid_speed && gps_data.satellites >= 6) ? gps_data.speed_kmh : 0.0;
    
    // 高精度数据输出
    sprintf(json_buffer, 
        "{"
        "\"temp\":%d,"
        "\"gravity\":%.3f,"
        "\"roll\":%d,"
        "\"pitch\":%d,"
        "\"gps\":{"
            "\"speed\":%.2f,"
            "\"rawGPSSpeed\":%.2f,"
            "\"imuSpeed\":%.2f,"
            "\"speedConfidence\":%.2f,"
            "\"maxSpeed\":%.2f,"
            "\"satellites\":%d,"
            "\"valid\":%s,"
            "\"latitude\":%.8f,"
            "\"longitude\":%.8f,"
            "\"altitude\":%.2f,"
            "\"hdop\":%.3f,"
            "\"course\":%.1f,"
            "\"accuracy\":%.2f"
        "},"
        "\"performance\":{"
            "\"accelG\":%.4f,"
            "\"lateralG\":%.4f,"
            "\"accel0to100\":%.2f,"
            "\"brake100to0\":%.2f,"
            "\"maxAccelG\":%.4f,"
            "\"maxBrakeG\":%.4f,"
            "\"maxLateralG\":%.4f,"
            "\"power\":%.2f,"
            "\"confidence\":%.2f"
        "}"
        "}",
        (int)mpu6050_data.Temperature,
        sqrt(acc_x_corrected*acc_x_corrected + acc_y_corrected*acc_y_corrected + acc_z_corrected*acc_z_corrected),
        (int)roll,
        (int)pitch,
        safe_speed,                 // 融合后的最终速度
        gps_data.speed_kmh,         // 原GPS速度
        0.0,                        // IMU积分速度(暂未实现)
        100.0,                      // 速度可信度(默认100%)
        gps_data.max_speed_session,
        gps_data.satellites,
        (gps_data.valid_location && gps_data.satellites >= 6) ? "true" : "false",
        safe_lat,
        safe_lon,
        gps_data.altitude,
        gps_data.hdop,
        gps_data.course,
        gps_data.position_accuracy,
        fused_data.current_accel_g,
        fused_data.current_lateral_g,
        performance_data.accel_0_100_time,
        performance_data.brake_100_0_time,
        fused_data.session_max_accel_g,
        fused_data.session_max_brake_g,
        fused_data.session_max_lateral_g,
        fused_data.instantaneous_power_estimate,
        (gps_data.satellites >= 8 && gps_data.hdop < 1.5) ? 1.0 : 0.6
    );
    
    // 优化的HTTP头
    server.sendHeader("Cache-Control", "no-cache, no-store, must-revalidate");
    server.sendHeader("Connection", "keep-alive");
    
    server.send(200, "application/json", json_buffer);
}

/**
 * 处理摩托车数据API请求
 */
void handleMotoData() {
    // 更新摩托车数据
    updateMotorcycleData();
    
    char json_buffer[600];
    
    sprintf(json_buffer,
        "{"
        "\"lean\":{\"current\":%.2f,\"filtered\":%.2f,\"maxL\":%.1f,\"maxR\":%.1f},"
        "\"g\":{\"fwd\":%.3f,\"lat\":%.3f,\"vert\":%.3f,\"combined\":%.3f},"
        "\"max\":{\"fwdG\":%.2f,\"brakeG\":%.2f,\"latG\":%.2f,\"combG\":%.2f},"
        "\"state\":{\"accel\":%s,\"brake\":%s,\"lean\":%s,\"wheelie\":%s,\"stoppie\":%s,\"corner\":%s},"
        "\"corner\":{\"count\":%d,\"speed\":%.1f,\"g\":%.2f,\"radius\":%.0f},"
        "\"wheelie\":{\"angle\":%.1f,\"max\":%.1f,\"count\":%d},"
        "\"speed\":%.1f,"
        "\"topSpeed\":%.1f,"
        "\"gyro\":{\"roll\":%.1f,\"pitch\":%.1f,\"yaw\":%.1f},"
        "\"sats\":%d"
        "}",
        moto_data.lean_angle,
        moto_data.lean_angle_filtered,
        moto_data.max_lean_left,
        moto_data.max_lean_right,
        moto_data.forward_g,
        moto_data.lateral_g,
        moto_data.vertical_g,
        moto_data.combined_g,
        moto_data.max_forward_g,
        moto_data.max_brake_g,
        moto_data.max_lateral_g,
        moto_data.max_combined_g,
        moto_data.is_accelerating ? "true" : "false",
        moto_data.is_braking ? "true" : "false",
        moto_data.is_leaning ? "true" : "false",
        moto_data.is_wheelie ? "true" : "false",
        moto_data.is_stoppie ? "true" : "false",
        moto_data.in_corner ? "true" : "false",
        moto_data.corner_count,
        moto_data.corner_speed,
        moto_data.corner_g,
        moto_data.corner_radius_estimate,
        moto_data.wheelie_angle,
        moto_data.max_wheelie_angle,
        moto_data.wheelie_count,
        gps_data.valid_speed ? gps_data.speed_kmh : 0.0,
        moto_data.top_speed,
        moto_data.roll_rate,
        moto_data.pitch_rate,
        moto_data.yaw_rate,
        gps_data.satellites
    );
    
    server.sendHeader("Cache-Control", "no-cache, no-store, must-revalidate");
    server.sendHeader("Connection", "keep-alive");
    server.send(200, "application/json", json_buffer);
}

/**
 * 处理录音状态API请求
 */
void handleAudioData() {
    char json_buffer[400];
    
    const char* stateStr = "idle";
    switch (audio_data.state) {
        case RECORDING_IDLE: stateStr = "idle"; break;
        case RECORDING_WAITING: stateStr = "waiting"; break;
        case RECORDING_ACTIVE: stateStr = "recording"; break;
        case RECORDING_PAUSED: stateStr = "paused"; break;
        case RECORDING_STOPPED: stateStr = "stopped"; break;
    }
    
    sprintf(json_buffer,
        "{"
        "\"state\":\"%s\","
        "\"filename\":\"%s\","
        "\"duration\":%.1f,"
        "\"fileSize\":%lu,"
        "\"volume\":%d,"
        "\"peakVolume\":%d,"
        "\"autoRecord\":%s,"
        "\"storage\":{"
            "\"total\":%lu,"
            "\"used\":%lu,"
            "\"free\":%lu"
        "},"
        "\"error\":%s,"
        "\"errorMsg\":\"%s\""
        "}",
        stateStr,
        audio_data.filename,
        audio_data.duration_ms / 1000.0,
        audio_data.file_size,
        audio_data.current_volume,
        audio_data.peak_volume,
        audio_data.auto_record_on_ride ? "true" : "false",
        audio_data.spiffs_total,
        audio_data.spiffs_used,
        audio_data.spiffs_free,
        audio_data.error ? "true" : "false",
        audio_data.error_msg
    );
    
    server.sendHeader("Cache-Control", "no-cache");
    server.send(200, "application/json", json_buffer);
}

/**
 * 处理录音控制API请求
 * 参数: action = start | stop | pause | resume | delete | toggle_auto
 */
void handleAudioControl() {
    String action = server.arg("action");
    String response = "{\"success\":true,\"message\":\"";
    
    if (action == "start") {
        if (startRecording()) {
            response += "录音已开始\"}";
        } else {
            response = "{\"success\":false,\"message\":\"";
            response += audio_data.error_msg;
            response += "\"}";
        }
    } else if (action == "stop") {
        stopRecording();
        response += "录音已停止\"}";
    } else if (action == "pause") {
        pauseRecording();
        response += "录音已暂停\"}";
    } else if (action == "resume") {
        resumeRecording();
        response += "录音已恢复\"}";
    } else if (action == "delete") {
        deleteAllRecordings();
        response += "所有录音已删除\"}";
    } else if (action == "toggle_auto") {
        audio_data.auto_record_on_ride = !audio_data.auto_record_on_ride;
        response += audio_data.auto_record_on_ride ? "自动录音已开启\"}" : "自动录音已关闭\"}";
    } else if (action == "list") {
        // 返回录音列表
        String list = getRecordingsList();
        server.send(200, "application/json", list);
        return;
    } else {
        response = "{\"success\":false,\"message\":\"未知操作\"}";
    }
    
    server.send(200, "application/json", response);
}

/**
 * 处理录音文件下载
 * 参数: file = 文件名
 */
void handleAudioDownload() {
    String filename = server.arg("file");
    if (filename.length() == 0) {
        server.send(400, "text/plain", "Missing file parameter");
        return;
    }
    
    // 确保文件名以/开头
    if (!filename.startsWith("/")) {
        filename = "/" + filename;
    }
    
    if (!SPIFFS.exists(filename)) {
        server.send(404, "text/plain", "File not found");
        return;
    }
    
    File file = SPIFFS.open(filename, "r");
    if (!file) {
        server.send(500, "text/plain", "Cannot open file");
        return;
    }
    
    // 设置下载头
    server.sendHeader("Content-Disposition", "attachment; filename=" + filename.substring(1));
    server.streamFile(file, "audio/wav");
    file.close();
}

void displayQRCode() {
    display.clearDisplay();
    display.setTextSize(1);
    display.setTextColor(SSD1306_WHITE);
    
    // 显示WiFi信息
    display.setCursor(0, 0);
    display.println("WiFi: ESP32-IMU");
    display.println("Pass: 12345678");
    display.println("");
    display.println("Scan QR or visit:");
    display.println("http://192.168.4.1");
    display.println("");
    display.println("Press BOOT to switch");
    
    // 简单的二维码替代（文字版）
    display.setCursor(0, 56);
    display.print("QR: 192.168.4.1");
    
    display.display();
}
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
void loop() {
  unsigned long currentTime = millis();
  
  // 处理Web服务器请求
  server.handleClient();
  
  // 检查BOOT按钮切换显示模式（GPIO0通常是BOOT按钮）
  static bool lastBootState = HIGH;
  bool currentBootState = digitalRead(0);
  if (lastBootState == HIGH && currentBootState == LOW) {
    display_mode = (display_mode + 1) % 5; // 切换显示模式: 0=IMU, 1=二维码, 2=GPS, 3=性能, 4=摩托车
    delay(200); // 防抖
  }
  lastBootState = currentBootState;
  
  // 处理串口命令
  handleSerialCommands();
  
  // ===== 高频IMU采样 (200Hz) - Dragy模式关键 =====
  if (currentTime - lastIMUTime >= IMU_INTERVAL) {
    ReadMPU6050();  // 200Hz读取IMU数据
    
    // GPS-IMU速度融合 (每次IMU采样都进行)
    double dt = IMU_INTERVAL / 1000.0; // 转换为秒
    fuseIMUSpeed(mpu6050_data.Acc_X, mpu6050_data.Acc_Y, dt);
    
    lastIMUTime = currentTime;
  }
  
  // ===== GPS数据处理 (10Hz) =====
  if (currentTime - lastGPSTime >= GPS_INTERVAL) {
    updateGPSData(); // 10Hz更新GPS数据
    
    // ===== SD卡数据记录 (10Hz) =====
    // 自动检测是否应该开始/停止记录
    checkAutoLogging(fused_data.current_speed_kmh);
    
    // 如果正在记录，保存数据点
    if (sd_status.logging) {
      RideDataPoint dp;
      dp.timestamp = currentTime;
      dp.latitude = gps_data.latitude;
      dp.longitude = gps_data.longitude;
      dp.speed_kmh = gps_data.speed_kmh;
      dp.altitude = gps_data.altitude;
      dp.satellites = gps_data.satellites;
      dp.hdop = gps_data.hdop;
      dp.accel_x = mpu6050_data.Acc_X;
      dp.accel_y = mpu6050_data.Acc_Y;
      dp.accel_z = mpu6050_data.Acc_Z;
      dp.gyro_x = mpu6050_data.Angle_Velocity_R;
      dp.gyro_y = mpu6050_data.Angle_Velocity_P;
      dp.gyro_z = mpu6050_data.Angle_Velocity_Y;
      dp.roll = mpu6050_data.Roll;
      dp.pitch = mpu6050_data.Pitch;
      dp.forward_g = fused_data.current_accel_g;
      dp.lateral_g = fused_data.current_lateral_g;
      dp.fused_speed = fused_data.current_speed_kmh;
      logDataPoint(dp);
    }
    
    lastGPSTime = currentTime;
  }
  
  // ===== 录音模块更新 (持续) =====
  updateAudioRecorder();  // 处理音频采样和自动录音触发
  
  // ===== 显示和融合更新 (20Hz) =====
  if (currentTime - lastUpdateTime >= UPDATE_INTERVAL) {
    updateFusedData(); // 更新融合性能数据
    
    // 根据显示模式选择显示内容
    if (display_mode == 0) {
      updateDisplay();  // 显示IMU数据
    } else if (display_mode == 1) {
      displayQRCode();  // 显示二维码
    } else if (display_mode == 2) {
      displayGPSData(); // 显示GPS数据
    } else if (display_mode == 3) {
      displayPerformanceData(); // 显示性能数据
    } else if (display_mode == 4) {
      displayMotorcycleData(); // 显示摩托车数据
    }
    
    printDataToSerial();
    
    lastUpdateTime = currentTime;
  }
}

/**
 * 显示GPS数据
 */
void displayGPSData() {
  display.clearDisplay();
  display.setTextSize(1);
  display.setTextColor(SSD1306_WHITE);
  
  display.setCursor(0, 0);
  display.println("=== GPS STATUS ===");
  
  // 显示卫星和信号质量
  display.printf("Sats: %d HDOP: %.1f\n", gps_data.satellites, gps_data.hdop);
  
  // 显示速度信息
  if (gps_data.valid_speed) {
    display.printf("Speed: %.1f km/h\n", gps_data.speed_kmh);
    display.printf("Max: %.1f km/h\n", gps_data.max_speed_session);
  } else {
    display.println("Speed: No Fix");
  }
  
  // 显示位置信息
  if (gps_data.valid_location) {
    display.printf("Lat: %.4f\n", gps_data.latitude);
    display.printf("Lon: %.4f\n", gps_data.longitude);
  } else {
    display.println("Location: No Fix");
  }
  
  // 显示时间
  if (gps_data.valid_time) {
    display.printf("Time: %02d:%02d:%02d\n", 
                   gps_data.hour, gps_data.minute, gps_data.second);
  }
  
  display.display();
}

/**
 * 显示性能数据
 */
void displayPerformanceData() {
  display.clearDisplay();
  display.setTextSize(1);
  display.setTextColor(SSD1306_WHITE);
  
  display.setCursor(0, 0);
  display.println("=== PERFORMANCE ===");
  
  // 显示当前状态
  display.printf("Speed: %.1f km/h\n", fused_data.current_speed_kmh);
  display.printf("Accel: %.2fG ", fused_data.current_accel_g);
  display.printf("Lat: %.2fG\n", fused_data.current_lateral_g);
  
  // 显示状态指示
  display.print("Status: ");
  if (fused_data.is_accelerating) display.print("ACC ");
  if (fused_data.is_braking) display.print("BRK ");
  if (fused_data.is_cornering) display.print("COR");
  display.println();
  
  // 显示测试结果
  if (performance_data.accel_0_100_time > 0) {
    display.printf("0-100: %.2fs\n", performance_data.accel_0_100_time);
  }
  
  if (performance_data.brake_100_0_time > 0) {
    display.printf("100-0: %.2fs\n", performance_data.brake_100_0_time);
  }
  
  // 显示峰值数据
  display.printf("Max G: +%.1f/%.1f/%.1f\n", 
                fused_data.session_max_accel_g,
                fused_data.session_max_brake_g,
                fused_data.session_max_lateral_g);
  
  display.display();
}

/**
 * 显示摩托车数据 (display_mode = 4)
 */
void displayMotorcycleData() {
  // 更新摩托车数据
  updateMotorcycleData();
  
  display.clearDisplay();
  display.setTextSize(1);
  display.setTextColor(SSD1306_WHITE);
  
  // 标题栏 - 包含录音状态
  display.setCursor(0, 0);
  display.print("MOTO ");
  
  // 录音状态指示
  if (audio_data.state == RECORDING_ACTIVE) {
    display.print("[REC]");  // 正在录音
  } else if (audio_data.auto_record_on_ride) {
    display.print("[AUTO]"); // 自动录音待命
  }
  
  // 显示状态图标
  display.setCursor(70, 0);
  if (moto_data.is_wheelie) display.print("W!");
  else if (moto_data.is_stoppie) display.print("S!");
  else if (moto_data.is_leaning) display.print(">");
  else if (moto_data.is_braking) display.print("B");
  else if (moto_data.is_accelerating) display.print("A");
  
  // GPS状态
  display.setCursor(100, 0);
  display.printf("%dS", gps_data.satellites);
  
  // === 大字体显示倾角 ===
  display.setTextSize(2);
  display.setCursor(0, 10);
  
  // 倾角显示
  float lean = moto_data.lean_angle_filtered;
  if (lean >= 0) {
    display.printf("R%4.1f", lean);  // 右倾
  } else {
    display.printf("L%4.1f", -lean); // 左倾
  }
  display.setTextSize(1);
  display.setCursor(80, 10);
  display.print("deg");
  
  // 速度显示
  display.setCursor(80, 18);
  display.printf("%.0fkm/h", gps_data.speed_kmh);
  
  // === 第三行: G力数据 ===
  display.setCursor(0, 28);
  display.printf("Fwd:%.2fG Lat:%.2fG", moto_data.forward_g, moto_data.lateral_g);
  
  // === 第四行: 弯道信息 ===
  display.setCursor(0, 38);
  if (moto_data.in_corner) {
    display.printf("Corner! G:%.2f R:%.0fm", moto_data.corner_g, moto_data.corner_radius_estimate);
  } else {
    display.printf("Corners:%d Wheelie:%d", moto_data.corner_count, moto_data.wheelie_count);
  }
  
  // === 第五行: 录音信息或峰值记录 ===
  display.setCursor(0, 48);
  if (audio_data.state == RECORDING_ACTIVE) {
    // 显示录音信息
    display.printf("REC %.0fs Vol:%d", 
                  audio_data.duration_ms / 1000.0,
                  audio_data.current_volume);
  } else {
    display.printf("MaxL:%.0f/%.0f MaxG:%.1f", 
                  -moto_data.max_lean_left, 
                  moto_data.max_lean_right, 
                  moto_data.max_combined_g);
  }
  
  // === 第六行: 最高速度 ===
  display.setCursor(0, 56);
  display.printf("Top:%.1fkm/h W:%.0fdeg", 
                moto_data.top_speed,
                moto_data.max_wheelie_angle);
  
  display.display();
}

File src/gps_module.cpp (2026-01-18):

#include "gps_module.h"
#include "mpu6050.h"  // 添加MPU6050头文件
#include <SPIFFS.h>
#include <ArduinoJson.h>

// 全局对象定义
TinyGPSPlus gps;
HardwareSerial gpsSerial(2); // 使用Serial2
GPS_DATA gps_data;
PERFORMANCE_DATA performance_data;

// 性能测试阈值
const double ACCEL_TEST_START_SPEED = 5.0;    // 5km/h开始加速测试
const double ACCEL_TEST_60_SPEED = 60.0;      // 60km/h目标
const double ACCEL_TEST_100_SPEED = 100.0;    // 100km/h目标
const double ACCEL_TEST_200_SPEED = 200.0;    // 200km/h目标

const double BRAKE_TEST_START_SPEED = 95.0;   // 95km/h以上开始制动测试
const double BRAKE_TEST_END_SPEED = 5.0;      // 5km/h以下结束制动测试

const double LAP_RADIUS = 50.0;                // 起点/终点检测半径(米)

/**
 * 初始化GPS模块 - 针对Dragy风格性能测量优化
 */
bool initGPS() {
    Serial.println("正在初始化GPS模块 (Dragy模式)...");
    
    // 初始化GPS串口 - 使用GT-U7默认的9600波特率
    gpsSerial.begin(GPS_BAUD, SERIAL_8N1, GPS_RX_PIN, GPS_TX_PIN);
    
    // 等待GPS模块启动
    delay(1000);
    
    // 清空串口缓冲区
    while (gpsSerial.available()) {
        gpsSerial.read();
    }
    
    Serial.println("配置GPS模块参数 (10Hz模式)...");
    
    // ===== 关键：10Hz更新频率 (100ms) =====
    // GT-U7在9600波特率下支持10Hz，但需要精简NMEA输出
    gpsSerial.println("$PMTK220,100*2F");
    delay(300);
    
    // 只输出RMC和GGA - 10Hz时必须精简，否则数据溢出
    // RMC包含：时间、位置、速度(Doppler)、航向
    // GGA包含：定位质量、卫星数、HDOP、高度
    gpsSerial.println("$PMTK314,0,1,0,1,0,0,0,0,0,0,0,0,0,0,0,0,0,0,0*28");
    delay(300);
    
    // 启用SBAS增强定位精度
    gpsSerial.println("$PMTK313,1*2E");
    delay(300);
    
    // 设置DGPS模式为WAAS
    gpsSerial.println("$PMTK301,2*2E");
    delay(300);
    
    Serial.println("GPS模块初始化完成 - 10Hz Dragy模式");
    Serial.printf("GPS配置: RX=%d, TX=%d, 波特率=%d, 更新率=10Hz\n", 
                  GPS_RX_PIN, GPS_TX_PIN, GPS_BAUD);
    
    // 初始化性能数据
    resetPerformanceData();
    
    return true;
}

/**
 * 更新GPS数据
 */
void updateGPSData() {
    static unsigned long last_gps_data_time = 0;
    static unsigned long last_reconnect_attempt = 0;
    static int signal_lost_count = 0;
    static bool was_connected = false;
    static unsigned long last_raw_print = 0;
    
    unsigned long current_time = millis();
    
    // 读取GPS数据并打印原始NMEA（每2秒打印一次用于调试）
    bool got_new_data = false;
    String nmea_buffer = "";
    while (gpsSerial.available() > 0) {
        char c = gpsSerial.read();
        nmea_buffer += c;
        if (gps.encode(c)) {
            got_new_data = true;
            last_gps_data_time = current_time;
            signal_lost_count = 0;
        }
    }
    
    // 每5秒打印一次原始GPS数据用于调试
    if (nmea_buffer.length() > 0 && current_time - last_raw_print > 5000) {
        Serial.println("\n=== GPS原始NMEA数据 ===");
        Serial.print(nmea_buffer);
        Serial.printf("字节数: %d, 卫星数(parsed): %d\n", nmea_buffer.length(), gps.satellites.value());
        Serial.println("========================\n");
        last_raw_print = current_time;
    }
    
    // GPS信号监控和恢复
    if (current_time - last_gps_data_time > 3000) { // 3秒没有数据
        signal_lost_count++;
        
        // 每10秒尝试一次恢复
        if (current_time - last_reconnect_attempt > 10000) {
            Serial.println("GPS信号丢失，尝试恢复...");
            
            // 发送热重启命令
            gpsSerial.println("$PMTK101*32");
            delay(100);
            
            // 重新配置关键参数
            gpsSerial.println("$PMTK220,200*2C"); // 5Hz更新
            delay(100);
            gpsSerial.println("$PMTK314,0,1,0,1,0,0,0,0,0,0,0,0,0,0,0,0,0,0,0*28");
            delay(100);
            
            last_reconnect_attempt = current_time;
            Serial.printf("GPS恢复尝试完成，信号丢失计数: %d\n", signal_lost_count);
        }
        
        // 标记GPS数据为无效
        if (signal_lost_count > 5) {
            gps_data.valid_location = false;
            gps_data.valid_speed = false;
            gps_data.valid_time = false;
            gps_data.valid_date = false;
        }
    }
    
    // 处理有效的GPS数据
    if (got_new_data) {
        // 更新基础位置信息
        if (gps.location.isValid()) {
            double new_lat = gps.location.lat();
            double new_lon = gps.location.lng();
            
            // 数据合理性检验
            if (abs(new_lat) <= 90.0 && abs(new_lon) <= 180.0) {
                // 简单的位置跳变检测 (仅在已定位后)
                if (gps_data.valid_location) {
                    double distance = calculateDistance(gps_data.latitude, gps_data.longitude, new_lat, new_lon);
                    if (distance < 1000) { // 1km以内的变化才接受
                        gps_data.latitude = new_lat;
                        gps_data.longitude = new_lon;
                    }
                } else {
                    gps_data.latitude = new_lat;
                    gps_data.longitude = new_lon;
                }
                gps_data.valid_location = true;
                gps_data.fix_age = gps.location.age();
            }
        } else {
            gps_data.valid_location = false;
        }
        
        // 更新高度
        if (gps.altitude.isValid()) {
            double new_alt = gps.altitude.meters();
            if (new_alt > -1000 && new_alt < 10000) { // 合理高度范围
                gps_data.altitude = new_alt;
            }
        }
        
        // 更新时间
        if (gps.date.isValid() && gps.time.isValid()) {
            gps_data.year = gps.date.year();
            gps_data.month = gps.date.month();
            gps_data.day = gps.date.day();
            gps_data.hour = gps.time.hour();
            gps_data.minute = gps.time.minute();
            gps_data.second = gps.time.second();
            gps_data.centisecond = gps.time.centisecond();
            gps_data.valid_date = gps.date.isValid();
            gps_data.valid_time = gps.time.isValid();
        }
        
        // 更新速度和方向 - 极限优化版本
        if (gps.speed.isValid()) {
            double new_speed = gps.speed.kmph();
            if (new_speed >= 0 && new_speed < 400) {
                
                // 极限精度的静止检测 - 适配10Hz高频数据
                static double speed_buffer[20] = {0}; // 增加缓冲区适配10Hz
                static int buffer_index = 0;
                static double speed_sum = 0.0;
                static int stable_count = 0;
                
                // 更新循环缓冲区
                speed_sum -= speed_buffer[buffer_index];
                speed_buffer[buffer_index] = new_speed;
                speed_sum += new_speed;
                buffer_index = (buffer_index + 1) % 20;
                
                double avg_speed = speed_sum / 20.0;
                
                // 计算标准差和变化率 - 10Hz高频分析
                double variance = 0.0;
                for (int i = 0; i < 20; i++) {
                    double diff = speed_buffer[i] - avg_speed;
                    variance += diff * diff;
                }
                variance /= 20.0;
                double std_dev = sqrt(variance);
                
                // 10Hz下的动态阈值 - 更精细的控制
                double signal_quality = (gps_data.satellites >= 8) ? 1.0 : 0.7;
                double base_threshold = (gps_data.hdop < 1.2) ? 1.0 : 1.6; // 更低阈值
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

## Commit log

2025-12-24 关于imu的初次尝试
2025-12-26 第一个版本，初步实现oled功能
2025-12-27 修改了一下显示设置
2025-12-27 调参校准数据正确
2025-12-27 初步增加网页功能
2025-12-27 网页功能加入
2025-12-29 加入GPS功能
2025-12-29 融合算法优化
2025-12-31 优化了一下界面
2025-12-31 修改一下页面设置
2026-01-11 小改版提交
2026-01-14 提交修改
2026-01-18 尝试加入sd卡功能
2026-05-14 3d模型文件
    [pcb1_enclosure.scad, pcb1_enclosure_base.stl, pcb1_enclosure_exploded.stl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]
2026-05-22 建模提交
    [pcb1_enclosure.scad, pcb1_enclosure_base.stl, pcb1_enclosure_exploded.stl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]
2026-06-08 面试准备
2026-09-28 删除非必要产物
2026-09-28 删除一些不必要的文件
2026-09-28 chore: 移除已备份的 PDF/临时产物，远程仓库不再跟踪
2026-10-02 chore: .tex 文件不计入 GitHub 语言统计
